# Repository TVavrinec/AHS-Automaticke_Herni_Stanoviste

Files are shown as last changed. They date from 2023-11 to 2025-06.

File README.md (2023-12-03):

# AHS-Specifikace hrubý popis
Specifikace AHS (Automatické Herní Stanoviště), nástupcem Lucerny a BlackBoxu
Jde o statické zařízení sloužící jako herní stanoviště.
Mělo by tedy být mobilní jen natolik aby nebyl problém jej přepravovat.
Není ale cílem aby ho hráči nosil během hry nosil s sebou.

# Konkrétní uživatelské požadavky
- Dva LED kruhy jeden radiální a jeden axiální (tak jak na lucerně)
- Tlaková plocha (tak jak na lucerně ale doladit samotnou kontaktní plochu aby se zvýšila spolehlivost)
- Výdrž na baterii alespoň pět hodin aby bylo možné organizovat čtyřhodinovou hru s rezervou na nastavování atd.
- Elegantní zapínání (znamená ne powerbankou a kabelem!!!)
- Snadná montáž (znamená ne 16h na jeden kus)
- Servisně snadné připojený komunikační/GPS modul uvnitř zařízení (A9, MC60 ???)
- Servisně snadné připojená dvířka a jiné moduly vně základního zařízení
- Základní zvuková odezva (pískle, na pokročilejší zvuk bude modul)

# Základní struktura elektroniky

Elektronika je rozdělena na dvě desky, Led dsku a Hlavní desku.

## LedDeska

Oproti předchozím verzím je přidán LED-kruh i na druhou stranu LedDesky abychom se zbavili LED-pásku a odebrat výstupní konektor
- Přední axiální LEDkoví kruh z 60ti RGB LEDek
- Zadní radiální LEDkoví kruh z 60ti RGB LEDek (buď přímo radiální [buce cca třikrát dražší] nebo axiální s odraznou plochou [radializátorem])
- LDC1614 nebo LDC1314 + čtyři snímací cívky pro snímání tlakové plochy

## Hlavní deska 
- ESP32-S3
- Interní systémy
    - dohodnutí PD
    - bzučák (bez oscilátorové)
    - Power manager
        - jednočlánek
        - zapínání (ovládání na Mini UI)
        - step-up na 5V
        - LDO na 3V3
        - LDO na 1V8
        - nabíječka
        - hw ochrana podvybití
- Konektory na
    - ledDesku
    - komunikační modul
    - externí moduly
    - USB-C (nabíjení a primární programování [USB přímo z ESP, nebudeme zabírat místo převodníkem])
    - mini UI
    - kontakty na SemiSemafoří programátor
    - zbylé piny

## Mini UI
Minimalistické vývojové rozhraní.
- RESET tlačítka
- BOOT tlačítka
- zapínací tlačítko
- vypínací tlačítko bych spojil se zapínacím nebo možná s resetem (dlouhí stisk vypíná, nechci tam mít příliž mnoho tlačítek)
- dvě tlačítka 
- dvě obyčejné ledky?

# Popis jednotlivých bodů
## Interní systémy
### Dohodnutí PD
Vykomunykování vyššího napětí a proudu zajišťuje čip **AP33772** připojený na I2C ESP.

### Bzučák
Piezzo připojené mezi dva piny ESP aby bylo možné programově nastavit frekvenci a částečně i hlasitost.

### Power manager
#### Zapínání
Umožňuje uživateli zařízení zapnout tlačítkem.
Vypnutí je možné provést softwarově z ESP.

#### Step-up na 5V
Zajišťuje napájení světelným kruhům a externím modulům.
Maximální proud je sto ukrmit oba světelné kruhy a moduloví konektor.
*Je tedy sto dodat cca 7A*

#### LDO na 3V3
Z napětí 3.3V je napájeno ESP32S3, LCD1x14 a PD sink AP33772.
*Je tedy sto dodat cca 1A*

#### Nabíječka
Nabíjení probíhá přez USB-C, nabíječka je proto schopna rovzu z 5V.
Aby se ale zařízení dalo nabít rychleji je možno použít standard PowerDelivery s napětí až 21V.
Na nabíjení je proto použit chip **BQ24179YBGR**.

### Hw ochrana podvybití
Kvuli ochraně baterie se zařízení vypne pokud se baterie vybije pod 2.8V (podle https://web.archive.org/web/20101122230718/https://www.panasonic.com/industrial/includes/pdf/Panasonic_LiIon_Charging.pdf by napětí na článek nemělo klesnout pod 2.3V a AHS přidává rezervu 0.1V [ https://web.archive.org/web/20100413182032/http://www.panasonic.com/industrial/batteries-oem/oem/lithium-ion.aspx ]) 

## Konektory
### USB-C
D+ D- jsou napojeny přímo na ESP a CC piny jsou napojeny na AP33772(to přes I2C na ESP).

### Konektor komunikačního modulu
Na konektor, je z ESP vyvedeno: 
-   I2C
-   celý UART
-   FUL_CARD_POWER_OFF
-   RESET
-   WoWWAN (interrupt)

a mimo ESP je na konektoru:
-   napájení přímo z baterie
-   SIM

Pin-out M2 konektoru z https://files.waveshare.com/upload/0/02/SIM7600X-M2_Hardware_Design_V1.01.pdf
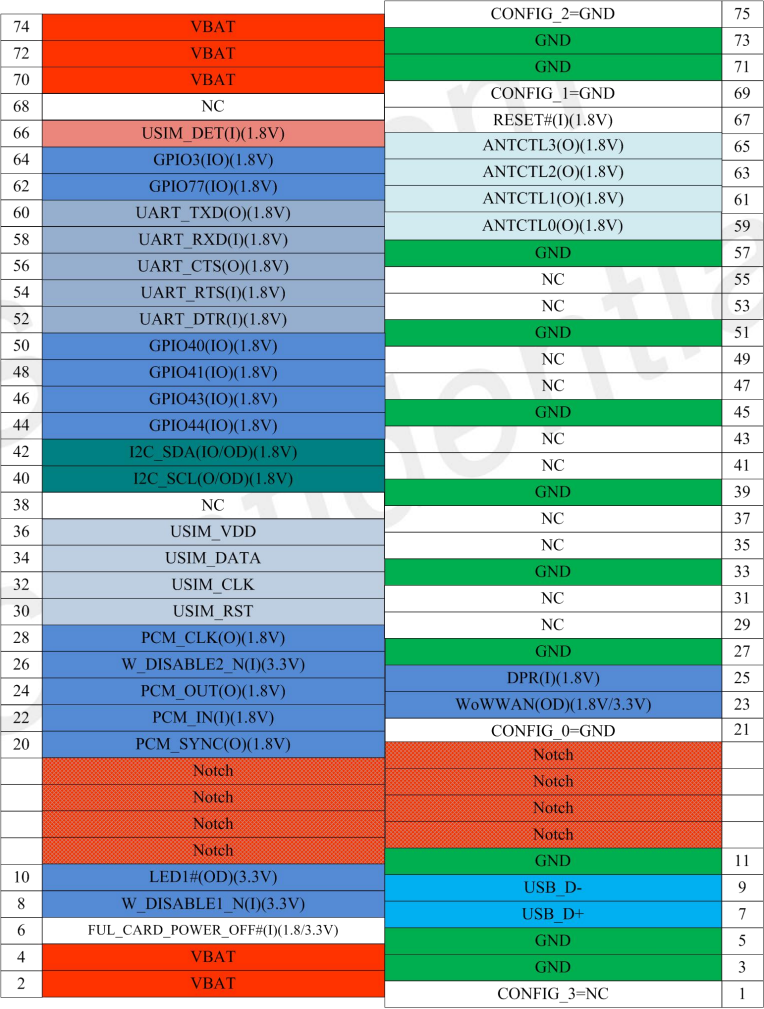
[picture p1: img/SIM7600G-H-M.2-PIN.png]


### Konektor na LedDesku

<-1--13-> 5V

<----14-> LED-DO

<-15-27-> GND

<----28-> 3V3

<----29-> LDC-GND

-----30-> LDC-INT

<----31-> SDA

<----32-- SCL

Pull-upy na I2C a na LDC-INT mají 4.7kΩ.
LDC-GND je na hlavní desce normální GND ale kvůli velkým proudum do ledek je v kabelu a na Led desce vedena odděleně.
Konektorem na 5V proteče alespoň 5A.

### Moduloví konektor

---> USART-RX

<--> 5V

<--> GND

<--- USART-TX

<--> GND

<--> 5V

---> INI

Všechny moduly jsou připojeny na jeden RX pin AHS.
Proto musí firmware AHS zajistit aby dva moduli nevysílali současně!
Každý modul má TX připojen přes rezistor 180Ω jako ochranu.

Interrupt na modulech se chová jako open-collector což je zajistit hardwarově.

AHS zajišťuje odolnost proti rušení na všech vstupních vodičích pomocí 4.7kΩ pull-up a odolnost proti zkratu na datových výstupních vodičích pomocí 180Ω.
Zároveň zajistí ESD ochranu všem vodičům co vedou z/do AHS.

Konektor je zároveň sto dodat napájení 5V s proudem v součty 2A.

Komunikace muže být vedena kabelem o délce až 25cm při komunikační rychlosti 5Mbps.
*Při dalším prodlužování linky bude třeba vodiče RX a TX vlnově přizpůsobit a doplnit linku terminátory*

## mechanická část
Základ AHS je mechanicky krátký válec s tlakovou plochou na horní ploše.
Kolem tlakové plochu je umístěn axiální světelný kruh a v horní části válcové plochy je radiální světelný kruh.

- Tělo minimálně v prototypu tisknuté
- Vyzkoušet různé provedení kontaktní plochy
    - Stejně jako na předchozí verzi FR4 ale tlustší aby se tolik nekroutila
    - PCB s hliníkovým jádrem + zalití do epoxidu nebo jiné dostatečně průsvitné hmoty
- Konektor externích modulu, USB-C a mini UI překrýt krytkou (ochrana před bordelem a náhodným mačkáním na tlačítka) 

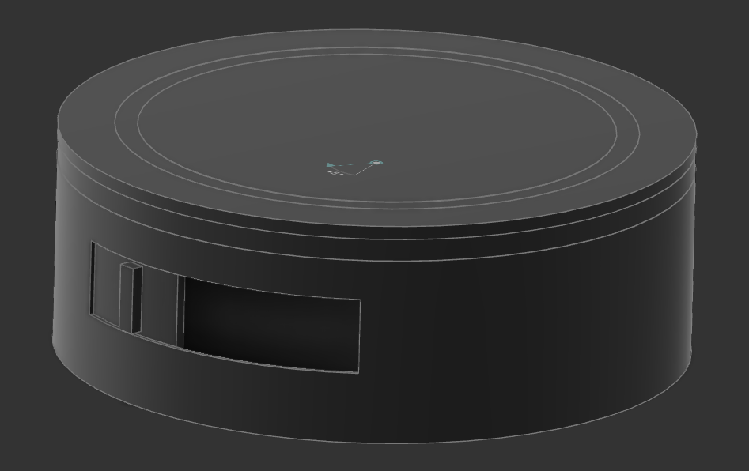
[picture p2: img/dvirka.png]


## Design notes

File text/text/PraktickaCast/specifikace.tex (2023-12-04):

Celé zařízení je rozděleno na základní jednotku a případné moduly které zajistí nové herní možnosti.
Například může jít o připojení úložného prostoru nebo zvukového modulu, který poskytne jak plnohodnotný zvukoví výstup tak vstup.

\subsection{uživatelské požadavky}
Jde o statické zařízení sloužící jako herní stanoviště.
Vyžaduje tedy mobilitu ale jen v rámci transportu na místo hry a spt, nikoliv v rámci samotné hry.

Zařízení bude mít dva světelné kruhy složené z inteligentních RGB LED.
Jeden radiální a druhý axiální na horní straně zařízení sloužící primárně jako odezva pro hráče na malou vzdálenost, např. při zadávání hesla.
Radiální kruh, také v horní části zařízení slouží naopak pro signalizace na delší vzdálenost, takový maják.

Uvnitř axiálního světelného kruhu se bude nacházet tzv. tlaková plocha.
Jedná se o ovládací prvek podobný dotykové ploše, s tím rozdílem že je schopen měřit i silu která na něj působí.

Aby bylo stanoviště reálně použitelné při hře musí celou hru vydržet na baterii.
Není ojedinělé aby měla outdoorová hra čtyři pět hodin bez přestávky.
Plus je nutná nějaká rezerva a čas na nastavování.
Pochopitelně je čas který zařízení zvládne běžet z baterie, silně závisí na činnosti, ale nebylo mi zrovna ideální, kdyby byla baterka, nějak výrazně omezující.
Výdrž na jedno nabití bych tedy chtěl směřovat alespoň na pět hodin.

Vzhledem k plánu připojovat moduly je nutné vyřešit jak se to budě dělat.
Bylo by ideální kdyby si mohl uživatel říct co bude hrát za hru a podle toho si sám připojil moduly které potřebuje.
Tomuto určitě nechceme bránit ale přímo to podporovat nese řadu problému jak ze strany konektoru a mechaniky, tak ze strany softwaru.
Konektor by totiž musel být ideálně beznástrojové rozpojitelný a opětovně spojitelný a přitom dostatečně pevný aby se zařízení mechanicky chovalo jako jeden celek.
Takový konektor je ale poměrně složité udělat tak aby byl spolehliví a tak jde v tuto chvíli spíš o hudbu budoucnosti.
Ze softwarového pohledu jde pak o problém z duvodu detekce konkrétních modulu a hlavně o otázku jak se chovat k modulum které jsou potenciálně záměnné.
Dejme tomu že máme modul klávesnici a modul dvířka.
Dvířka jsou původně primárně úložný prostor, díky detekci zavření je lze ale použít i jako velmi pohodlná tlačítka a v některých hrách se proto používají jen jako tlačítka.
Potenciální modul klávesnice je ovšem jen suma tlačítek.
Při vytváření konkrétní hry na míru modulum které herní návrhář má zrovna k dispozici je tento problém nepodstatný protože sám návrhář rozhodně co má jak být.
Ale ve chvíli kdy je ale o hru navrženou pro jinou kombinaci modulu nastává problém jak rozhodnout zda se dají dvířka použít místo klávesnice nebo ne.
Abychom se všem temto problémům, alespoň prozatím vyhnuli, rozhodli jsme že doplnění, či výměna modulu, pujde jen při servisním zásahu.

Některé hry vyžadují tak velké herní území že by na komunikaci mezi stanovišťmi už nestačila WiFi ani Bluetooth, které AHS jinak využívá ke komunikaci.  
Proto bude mít AHS možnost připojení k mobilní síti a tedy připojení k internetu.
Tím se za prvé rozšíří dosah AHS, všude kde je mobilní pokrytí a také přibude další metoda jak se stanovištěm komunikovat.
V rámci tohoto komunikačního modulu bude možné používat navíc i GNSS \footnote{Global Navigation Satellite System}.
Vzhledem k faktu že se přece jen nejedná o systém, který by využila většina her a zároveň je poměrně drahý došli jsme k rozhodnutí, mít jej jen jako doplnitelný modul.
Protože se jedná o modul který zprostředkovává komunikaci se světem je pravděpodobné že bude potřebovat převádět výrazně větší množství dat než běžný modul.
Primárně z tohoto důvodu je tento modul připojen na samostatném konektoru.
Potřebné antény budou už v základním zařízení ale samotný modul spadá do doplňkové výbavy.

V řadě případu je užitečné mít možnost zvuková zpětné vazby.
Ideální by bylo moci přehrávat libovolnou nahrávku, většinou ale stačí jednoduchý ton jako řekněme potvrzení na zadané heslo.
Možnost přehrávat plnohodnotnou nahrávku proto odsouváme jako možný doplňkový modul a v základní jednotce pro jednoduchost postačí piezoměnič. 

% \begin{itemize}
%     \item Dva LED kruhy jeden radiální na horní straně zařízení a jeden axiální v horní části zařízení
%     \item Tlaková plocha
%     \item Výdrž na baterii alespoň pět hodin aby bylo možné organizovat čtyřhodinovou hru s rezervou na nastavování atd.
%     \item Servisně snadné připojený komunikační/GPS modul uvnitř zařízení
%     \item Servisně snadné připojená dvířka a jiné moduly vně základního zařízení
%     \item Základní zvuková odezva
% \end{itemize}

\subsection{Struktura elektroniky základní jednotky}

Elektronika je rozdělena na tři samostatné PCB.
Jde o HlavníDeska na které je většina elektroniky, o~desku s~hlavním uživatelským rozhraním (LedDeska) a~o~obslužnou desku s~minimalistickým uživatelským rozhraním pro neherní obsluhu (MiniUI).

\subsubsection{LedDesku}
Jak název napovídá na LedDesce se nacházejí oba světelné kruhy, mimo to je zde i elektronika pro snímání tlakové plochy, tedy LDC1x14 \cite{LDC1614} a jeho snímací cívky.
Právě snímaní tlakové plochy je jeden z podstatných duvodu oddělení této desky od zbytku, zabere totiž docela dost prostoru.

\begin{itemize}
    \item Axiální LED kruh z 60ti RGB LED WS2812
    \item Zadní radiální LED kruh z 60ti RGB LED WS2812
    \item LDC1614 nebo LDC1314 se čtyřmi snímacími cívkami pro snímání tlakové plochy
    \item konektor na propojení s HlavníDeskou
\end{itemize}

\subsubsection{MiniUI}
Kvuli aktuální představě mechanické konstrukce není úplně dobře možné mít toto minimalistické uživatelské rozhraní na HlavníDeska.
Proto sme se rozhodli jej vyseparovat na samostatnou destičku, na které bude jen pár tlačítek a dvě signalizační LED.

\begin{itemize}
    \item RESET tlačítka
    \item BOOT tlačítka
    \item zapínací tlačítko
    \item dvě uživatelská tlačítka 
    \item dvě uživatelské ledky
\end{itemize}

\subsubsection{HlavníDeska}
Na HlavníDesce je většina systému základního zařízení.

Protože máme dlouholetým zkušenostem s mikrokontrolery ESP32, rozhodovali jsme jen mezi konkrétními čipy z této rodiny.
% Dnes už tedy jen většina, mikrokontroleru této rodiny má integrovanou WiFi a Bluetooth periferii, kterou AHS určitě využije.
Aktuální plán na tvorbu vysoko-úrovňového návrhu konkrétních her je používat skriptovací jazyk JavaScript, považujeme za nevhodné provádět tento návrh na úrovní jazyka C/C++.
Abychom tohoto mohli dosáhnout, musíme provozovat nějaký interpreter JavaScriptu a z aktuálně dostupných možností, považujeme za nejideálnější Jaculus \cite{Jaculus}.
Jaculus dělá řadu věcí paralelně a je tím pádem pro jeho chod ideální mít více jader procesoru, což aktuálně znamená tři možnosti ESP32, ESP32S2 a ESP32S3.
ESP32S2 nemá Bluetooth, který bychom rádi měli k dispozici.
ESP32S3 je téměř jen vylepšená verze staršího ESP32, oproti tomu mu sice chybí pár možností, ty ale v AHS nepotřebujeme využívat a naopak se nám hodí vyšší výpočetní výkon, rychlejší paměť a více piny.
AHS tedy ovládá mikrokontroler ESP32S3.

Zdroj AHS je tvořen dvěma LiIon články 18650 v paralelním uspořádání.
Paralelní uspořádání jsme zvolili aby nebylo nutné řešit balancování článků.

Aby nebylo možné softwarově baterii podvybít má AHS systém, který celé zařízení vypne v případě kdy dojde k vybití baterie pod 2.8V.
Pochopitelně software by měl vybitou baterii zaznamenat mnohem dřív a chovat se podle toho, např. neumožnit spustit hru s baterii na napětím 3.0V.

Baterii je pochopitelně nutno nabijet a bylo by velmi nepohodlné kvuli tomu muset vytahovat články ze zařízení.
Proto je na HlavníDesce i nabíjecí elektronika.
Navíc aby se minimalizoval čas nabíjení zařízení podporuje standard PowerDelivery a to až do napětí 21V.

Protože různé periferie vyžadují různá napájecí a komunikační napětí jsou na HlavníDeska hned čtyři napájecí větvě.
\begin{itemize}
    \item VCC, napětí baterie sloužící jako zdroj pro ostatní napájecí větvě a pro napájení komunikačního modulu. 
    \item Napětí \(3.3\-[V]\) na napájení logické části celého základního zařízení.
    \item Napětí \(5.0\-[V]\) pro LedDesku a externí moduly
    \item Napětí \(1.8\-[V]\) pro napájení napěťových převodníků sloužících na komunikaci s komunikačním modulem 
\end{itemize}
Napětí jednotlivých větví to u \(3.3\-[V]\) a \(1.8\-[V]\) tvořeno pomocí LDO.
Na vytvoření pěti voltové větvě je ale potřeba spínaný zdroj a to primárně ze dvou důvodů.
Za prvé protože napětí baterie ze které se tato větev napájí má nižší napětí a je jej tedy třeba vyspínat na napětí vyšší.
Za druhé tento zdroj poskytuje do systému mnohem větší proudy než druhé dvě větve a bylo by tedy vhodné, ho použít i v případě použití sériového řazení článků.

Na hlavníDesce je také řada konektorů sloužící pro připojení ostatních systémů.
Jde o konektory na:
\begin{itemize}
    \item propojení s LedDeskou                                             % samostatný objekt
    \item připojení MiniUI                                                  % samostatný objekt
    \item komunikační modul (M2 Konektor umožňuje použít různé moduly)      % externě definovaný objekt
    \item externí moduly                                                    % samostatný objekt
    \item USB-C (nabíjení a programování AHS)                               % externě definovaný objekt
    \item programátor                                                       % samostatný objekt
\end{itemize}
Do konektorů by se asi dal zařadit i držák na dva LiIon články 18650.

Za zmínku také stojí přítomnost piezoměniče pro jednoduchou zvukovou odezvu. 

\subsubsection{Propojení HlavníDesky a LedDesky}
Mezi HlavníDeskou a LedDeskou je třeba převést napájení a několik signálů.
LedDeska vyžaduje na konektoru přítomnost dvou napájecích větví \(5\-[V]\) pro světelné kruhy a \(3.3\-[v]\) pro snímání tlakové plochy.
Protože do LEDek může téct proud až 5A a být zároveň i docela rychle spínaný, považujeme za rozumné oddělit napájecím větvím zem.
Oddělení je tedy provedeno už na konektoru HlavníDesky.

Na samotné propojení jsme se rozhodli použít FFC kabel s roztečí \(0.5\-[mm]\).
Jednim vodičem takovéhoto kabelu zle vést proud maximálně \(0.4\-[A]\) \cite{FFC-konektor}.
Protože ale potřebujeme dodat proud až 5A použijeme 13 vodičů vedle sebe jakožto nejmenší počet který přenese požadovaný proud v rámci daných mezí.

Mimo napájení je tímto propojením veden i signál s daty pro světelné kruhy a I2C sběrnice s interruptem pro připojení čipu LDC1614 \cite{LDC1614}.

Vzhledem k počtu potřebných vodičů (konkrétně 32) jsme se rozhodli použít velmi běžný FFC konektor se 40 kontakty, s tím že zbylé kontakty se mohou hodit v budoucnu.

\subsubsection{Modulový konektor}
Modulovým konektorem je vedeno \(5\-[V]\) jako napájení pro moduly a UART s interruptem pro komunikaci.
Nad volbou komunikační sběrnice jsme strávili poměrně dost času přemýšlením.
Původně jsme uvažovali o využití RS485 jakožto odolné sběrnice u které by v případ potřeby nemusel být problém ani delší kabel.
RS485 má ale nevýhodu v tom že potřebuje dodatečný hardware, kterému bychom se hlavně na modulech rádi vyhnuli.
Stejný problém nastel u CANu i USB které by navíc mělo výhodu kompatibility se velkým množstvím hotových zařízení.

V první uvaze o UARTu jsme jej nejprve zavrhli kvuli potenciální náročnosti na přeposílání dat mezi moduly.
Při standardním použití, bychom totiž moduly řadili za sebe.
Prvnímu modulu by tak chodili data pro všechny ostatní moduly a musel by je přeposílat dál, což by stálo nezanedbatelné množství procesorového času.
V jisté chvíli jsme ale narazili na nestandardní komunikaci pomocí UARTu implementované v projektu Servio \cite{Servio}.
Tato implementace používá UART jako sběrnici.
Namísto standardního použití pro komunikace jeden s jedním tak muže komunikovat jeden s více.
Na tomto řešení je výhodné že nevyžaduje žádný dodatečný hardware a prakticky každý dnešní mikrokontroler je možné k této sběrnici velmi snadno připojit.
Ve srovnání s RS485 je sice mnohem méně odolná proti rušení, ale uvnitř zařízení nebude linka vedena na víc jak malé desítky centimetru.
Komunikace na delším kabelu je pak jednoduše nahraditelné bezdrátovou komunikací a není tak potřebné aby to nativně umožňovala tato sbernice.
Každopádně v případě potřeby delšího kabelu je možné navrhnout externí modul, který s této sbernic velmi jednoduše udělá RS485.
Alternativně by se pro komunikaci na delším kabelu dalo použít USB které je společně s nabíjením přivedeno na USB-C.

Všechny moduly jsou tedy připojeny na jeden RX pin AHS.
Proto musí firmware AHS zajistit aby dva moduly nevysílali současně.
Aby se zabránilo možným zkratum, jako ochranu má každý modul své piny UARTu připojeny přes rezistor \(180\-[\Omega]\).
Interrupt pin modulů se naopak chová jako open-collector a na straně hlavního zařízení je na něj tedy připojen pull-up rezistor.
Abychom alespoň trochu zvýšili odolnost linky proti rušení přidáme na přijímací stranu pull-up rezistor.
Cílem je zvýšení komunikačního proudu aby se případný proud vyvolaný rušením dal jednodušeji zanedbat.
V neposlední řadě jsou mají všechny piny na konektoru ESD ochranu.

\subsubsection{Konektor programátor}
Zařízení se dá jednoduše programovat přes USB-C, tento kanál se ale dá softwarově narušit a pro takové případy je tu konektor na programátor.
Jde o šest plošek na které se programátor připojuje pomocí pogo-pin.
Programátor sice obsahuje jen jednoduchou elektroniku která by mohla být i přímo v elektronice AHS ale ve většině případu by byla zbytečná.
Ve chvíli kdy by byla potřeba tak je stejně nutná odborná obsluha a pro tu není problém použít programátor.

\subsubsection{USB-C}
Jako napájecí a programovací konektor je použito USB-C.
Díky němu je možné podporovat standard PowerDelivery využitý pro zrychlení nabíjení.
Konektor je ale použit i na pohodlnější programování zařízení, pez potřeby programátoru.

\subsubsection{Konektor komunikačního modulu}
Pro připojení komunikačního modulu jsme zvolili konektor M2 typ-B jakožto standard pro tyto moduly.
Díky tomuto konektoru můžeme jednoduše připojit různé LTE a GNSS moduly.

% Na konektor, je z ESP vyvedeno: 
% -   I2C
% -   celý UART
% -   FUL_CARD_POWER_OFF
% -   RESET
% -   WoWWAN (interrupt)

% a mimo ESP je na konektoru:
% -   napájení přímo z baterie
% -   SIM

% Pin-out M2 konektoru z https://files.waveshare.com/upload/0/02/SIM7600X-M2_Hardware_Design_V1.01.pdf
% ![](img/SIM7600G-H-M.2-PIN.png)

% ## mechanická část
% Základ AHS je mechanicky krátký válec s tlakovou plochou na horní ploše.
% Kolem tlakové plochu je umístěn axiální světelný kruh a v horní části válcové plochy je radiální světelný kruh.

% - Tělo minimálně v prototypu tisknuté
% - Vyzkoušet různé provedení kontaktní plochy
%     - Stejně jako na předchozí verzi FR4 ale tlustší aby se tolik nekroutila
%     - PCB s hliníkovým jádrem + zalití do epoxidu nebo jiné dostatečně průsvitné hmoty
% - Konektor externích modulu, USB-C a mini UI překrýt krytkou (ochrana před bordelem a náhodným mačkáním na tlačítka) 

% ![](img/dvirka.png)

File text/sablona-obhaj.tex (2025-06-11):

% Soubory musí být v kódování, které je nastaveno v příkazu \usepackage[...]{inputenc}

\documentclass[%        Základní nastavení
  %draft,    				  % Testovací překlad
  12pt,       				% Velikost základního písma je 12 bodů
	t,                  % obsah slajdů bude vždy začínat od shora (nebude vertikálně centrovaný)
	aspectratio=1610,   % poměr stran bude 16:10 (všechny projektory v učebnách na Technické 12 Brno),
	                    % další volby jsou 43, 149, 169, 54, 32.
	unicode,						% Záložky a informace budou v kódování unicode
]{beamer}				    	% Dokument třídy 'zpráva', vhodná pro sazbu závěrečných prací s kapitolami
%\usepackage{etex}

\usepackage[utf8]		  % Kódování zdrojových souborů je v UTF-8
	{inputenc}					% Balíček pro nastavení kódování zdrojových souborů
	
\usepackage{graphicx} % Balíček 'graphicx' pro vkládání obrázků
											% Nutné pro vložení logotypů školy a fakulty

\usepackage[          % Balíček 'acronym' pro sazby zkratek a symbolů
	nohyperlinks				% Nebudou tvořeny hypertextové odkazy do seznamu zkratek
]{acronym}						
											% Nutné pro použití prostředí 'acronym' balíčku 'thesis'

%% Balíček hyperref je volán třídou beamer automaticky, proto není třeba následujícího kódu:
%\usepackage[
%	breaklinks=true,		% Hypertextové odkazy mohou obsahovat zalomení řádku
%	hypertexnames=false % Názvy hypertextových odkazů budou tvořeny
%											% nezávisle na názvech TeXu
%]{hyperref}						% Balíček 'hyperref' pro sazbu hypertextových odkazů
%											% Nutné pro použití příkazu 'nastavenipdf' balíčku 'thesis'

\usepackage{cmap} 		% Balíček cmap zajišťuje, že PDF vytvořené `pdflatexem' je
											% plně "prohledávatelné" a "kopírovatelné"

%\usepackage{upgreek}	% Balíček pro sazbu stojatých řeckých písmem
											%% např. stojaté pí: \uppi
											%% např. stojaté mí: \upmu (použitelné třeba v mikrometrech)
											%% pozor, grafická nekompatibilita s fonty typu Computer Modern!

%\usepackage{amsmath} %balíček pro sabu náročnější matematiky

\usepackage{booktabs} % Balíček, který umožňuje v tabulce používat
% příkazy \toprule, \midrule, \bottomrule

\usepackage[absolute,overlay]{textpos}

%%%%%%%%%%%%%%%%%%%%%%%%%%%%%%%%%%%%%%%%%%%%%%%%%%%%%%%%%%%%%%%%%
%%%%%%      Definice informací o dokumentu             %%%%%%%%%%
%%%%%%%%%%%%%%%%%%%%%%%%%%%%%%%%%%%%%%%%%%%%%%%%%%%%%%%%%%%%%%%%%

\input{nastaveni}      % v tomto souboru doplňte údaje o sobě, o názvu práce...
                       % (tento soubor je sdílený s textem práce)

%%%%%%%%%%%%%%%%%%%%%%%%%%%%%%%%%%%%%%%%%%%%%%%%%%%%%%%%%%%%%%%%%%%%%%%%

%%%%%%%%%%%%%%%%%%%%%%%%%%%%%%%%%%%%%%%%%%%%%%%%%%%%%%%%%%%%%%%%%%%%%%%%
%%%%%%     Nastavení polí ve Vlastnostech dokumentu PDF      %%%%%%%%%%%
%%%%%%%%%%%%%%%%%%%%%%%%%%%%%%%%%%%%%%%%%%%%%%%%%%%%%%%%%%%%%%%%%%%%%%%%
%% Při vloženém balíčku 'hyperref' lze použít příkaz '\pdfsettings'
\pdfsettings
%  Nastavení polí je možné provést také ručně příkazem:
%\hypersetup{
%  pdftitle={Název studentské práce},    	% Pole 'Document Title'
%  pdfauthor={Autor studenstké práce},   	% Pole 'Author'
%  pdfsubject={Typ práce}, 						  	% Pole 'Subject'
%  pdfkeywords={Klíčová slova}           	% Pole 'Keywords'
%}
\hypersetup{pdfpagemode=FullScreen}       % otevření rovnou v režimu celé obrazovky
%%%%%%%%%%%%%%%%%%%%%%%%%%%%%%%%%%%%%%%%%%%%%%%%%%%%%%%%%%%%%%%%%%%%%%%

\usetheme{VUT} 				% barvy a rozložení prezentace odpovídající VUT FEKT
% alternativně lze použít jiná berevná témata, ale bez záruky. Například: 
%\usetheme{Darmstadt} \usecolortheme{default2}
\logoheader					% vytvoření zkráceného loga VUT FEKT v hlavičce slajdu, nechte odkomentované

\begin{document}

% v případě zakomentování následujícího se zobrazí v pravém dolním rohu slajdů klikatelné navigační symboly 
\disablenavigationsymbols

% titulní snímek, vysazen bez horních, dolních a postranních lišt (volba plain),
% není tak vysazen ani nadpis snímku
\maketitle

%%%%%%%%%%%%%%%%%%%%%%%%%%%%%%%%%%%%%%%%%%%%%%%%%%%%%%%%%%%%%%%%%%%%%%%
% 1. snímek s cíli (zadaním) práce
\begin{frame} 
	% nadpis snímku
	\frametitle{Cíle práce}
	\begin{enumerate}
		\item Popsat potřeby zážitkových her
		\item Navrh specifikace zařízení vhodných pro zážitkové hry 
		\item Navrhnout tato zařízení
		\begin{itemize}
			\item Statické zařízení AHS
			\item Dynamické zařízení Semisemafor 
		\end{itemize}
		\item Navrhnout a otestovat
	\end{enumerate}
\end{frame}

%%%%%%%%%%%%%
\begin{frame} 
	\frametitle{Náčrt funkcí AHS}
	\vspace{10mm}
	\begin{itemize}
		\item Statické herní stanoviště
		\item Bezdrátová komunikace
		\item Zobrazení herních dat
		\item Jednoduše přizpůsobitelný \newline uživatelský vstup
		\item Odolnost proti vodě
		\item Možnost servisně doplnit \newline moduly s přídavnými funkcemi 
	\end{itemize}

	\begin{textblock}{8}(7.5,5)
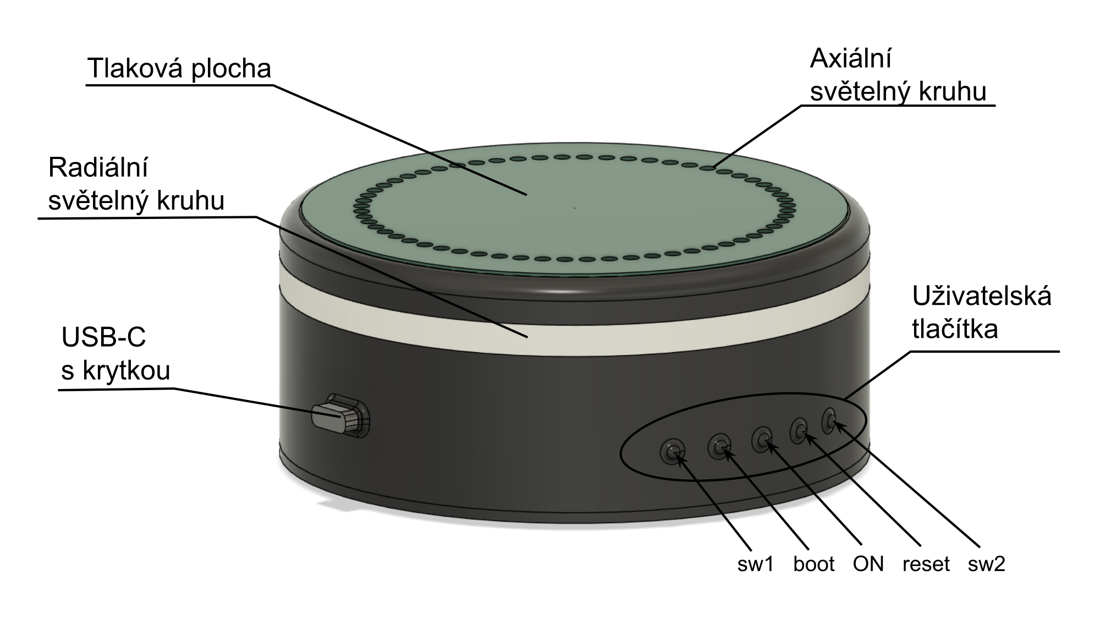
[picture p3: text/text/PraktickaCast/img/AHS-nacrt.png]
		
	\end{textblock}
\end{frame} 

%%%%%%%%%%%%%
\begin{frame} 
	\frametitle{Výsledná konstrukce AHS}
	\centering
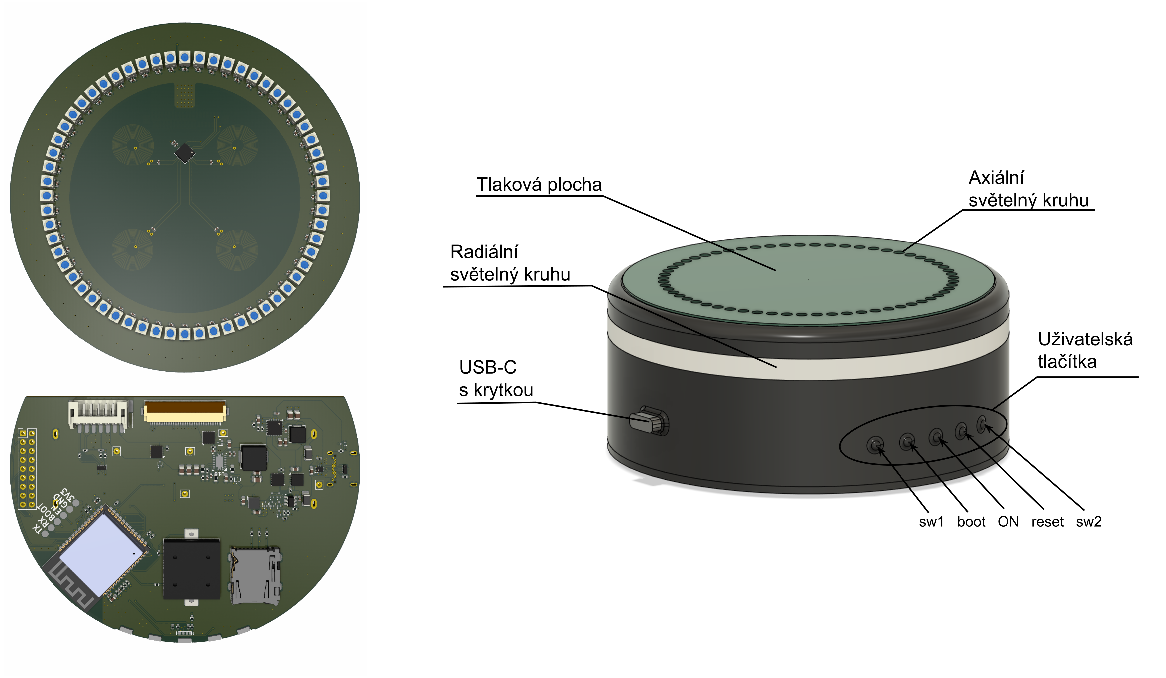
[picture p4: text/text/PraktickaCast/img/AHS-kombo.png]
	
\end{frame} 

\begin{frame} 
	\frametitle{Tlaková plocha}
	\centering
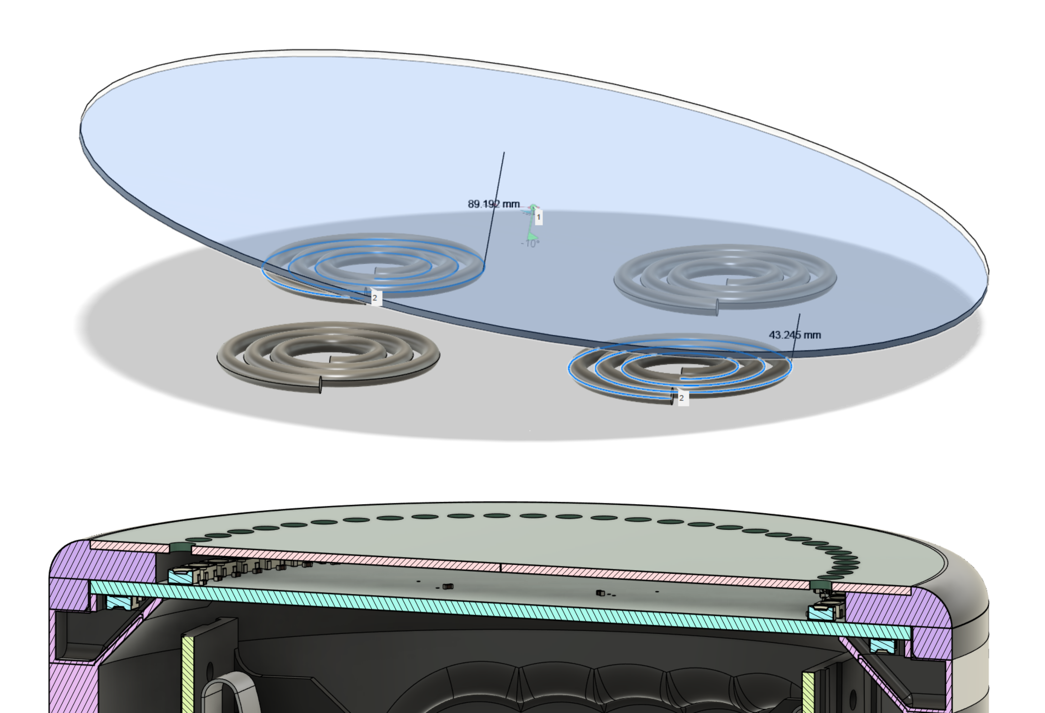
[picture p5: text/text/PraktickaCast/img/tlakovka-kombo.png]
	
\end{frame} 

%%%%%%%%%%%%%
\begin{frame} 
	\frametitle{Náčrt funkcí Semisemaforu}
	\vspace{10mm}
	\begin{itemize}
		\item Osobní zařízení
		\item bezdrátová komunikace
		\item zobrazení herních dat
		\item jednoduchý uživatelský vstup
		\item Odolnost proti vodě
	\end{itemize}

	\begin{textblock}{8}(7.5,2.5)
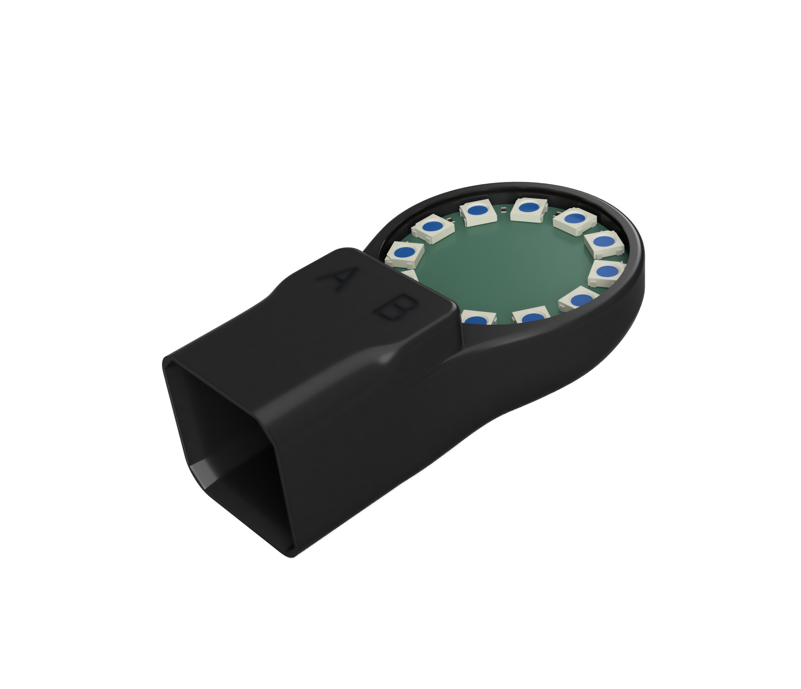
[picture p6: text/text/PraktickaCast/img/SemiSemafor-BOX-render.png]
		
	\end{textblock}
\end{frame} 

%%%%%%%%%%%%%
\begin{frame} 
	\frametitle{Závěr}
	\dots
\end{frame}

% podekovani
\begin{frame}[c] 
% bez nadpisu snímku
	\frametitle{\mbox{ }}
	\begin{center}
		{\Huge Děkuji za pozornost!}
	\end{center}
\end{frame}

% otázky oponenta
\frame{
\frametitle{Otázky oponenta}
	\emph{Jaká je souvislost Vašeho vzorce (1.2) s~Maxwellovými rovnicemi v~integrálním tvaru?}\\[2ex]
	%
	Již staří Římané\,\dots
}

\end{document}

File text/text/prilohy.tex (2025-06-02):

\chapter{Schémata AHS}
\label{AHS-sch}
\includepdf[pages=-, angle=90]{text/PraktickaCast/sch/ZakladniElektronika.pdf}

\chapter{Topologie DPS AHS}
\label{AHS-pcb}

\begin{figure}[!h]
	\begin{center}
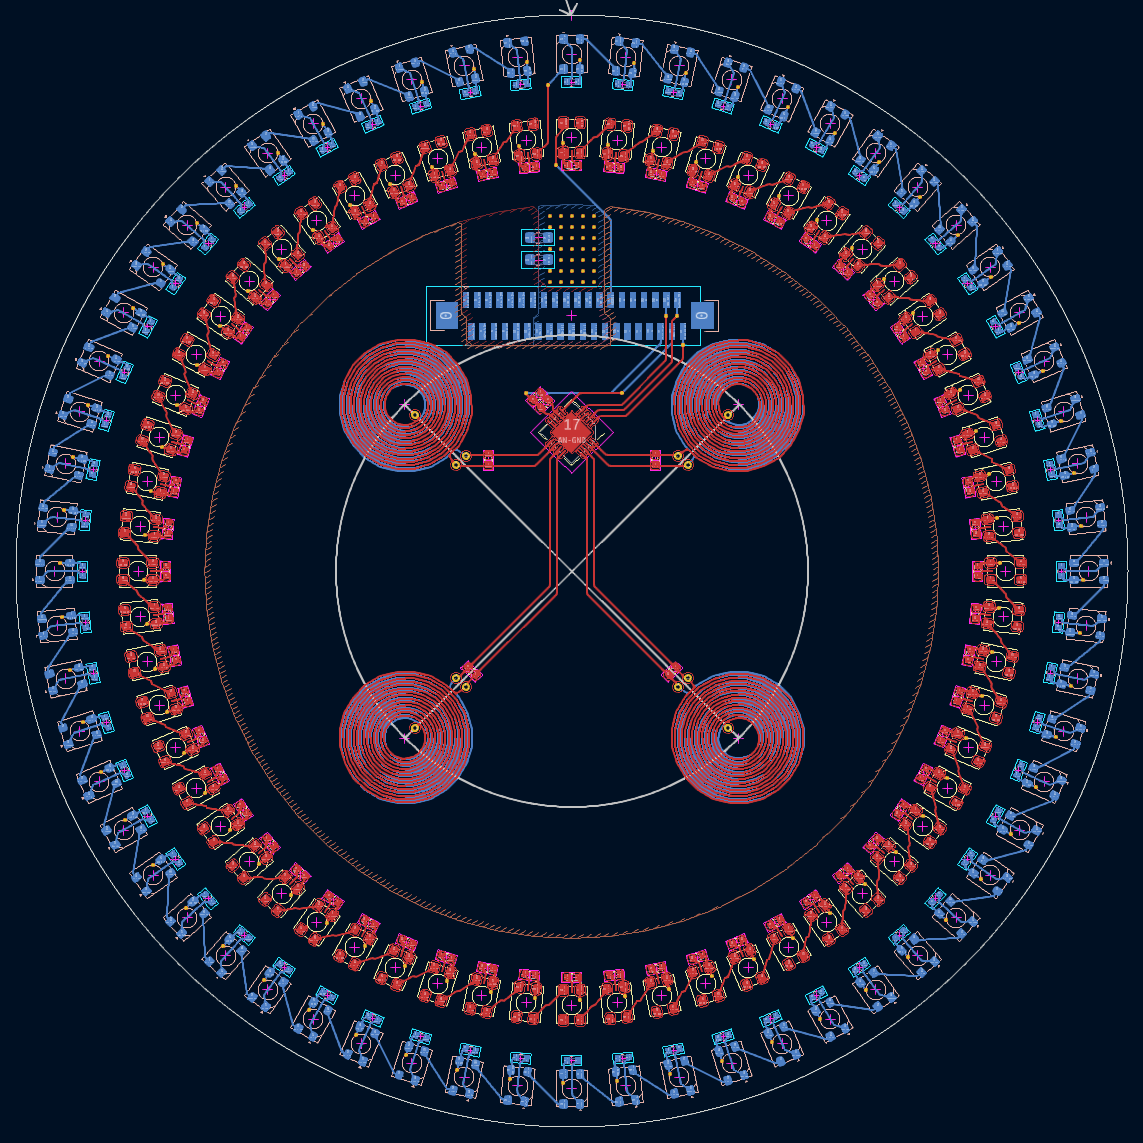
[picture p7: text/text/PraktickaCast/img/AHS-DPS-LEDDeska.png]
		
	\end{center}
	\caption{DPS LED desky AHS}
\end{figure}

\begin{figure}[!h]
	\begin{center}
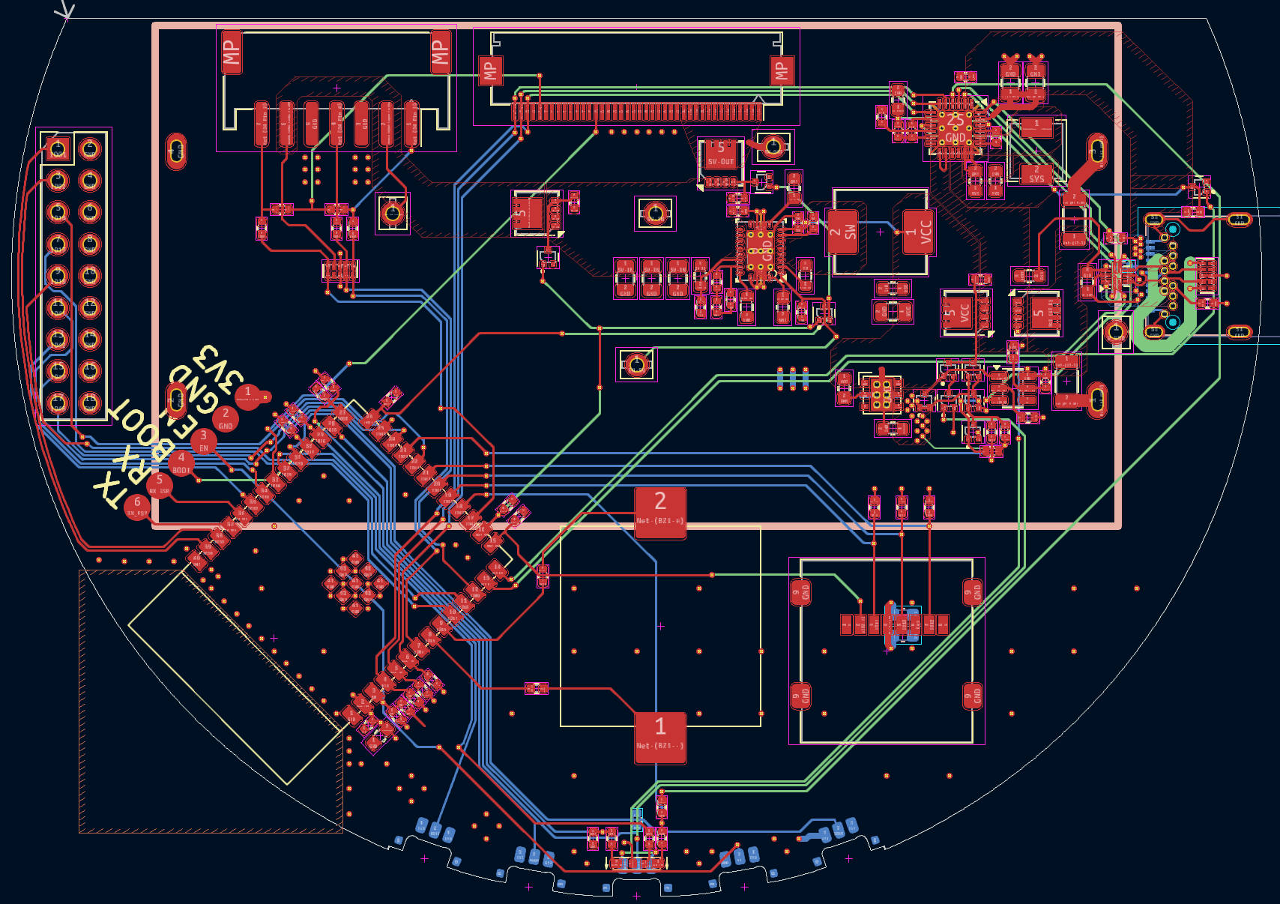
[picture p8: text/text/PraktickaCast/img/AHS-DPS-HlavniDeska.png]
	  
	\end{center}
	\caption{DPS hlavní desky AHS}
\end{figure}

\newpage

\chapter{Schémata Semisemaforu}
\section{Původní schéma Semisemaforu}
\label{Semisemafor-sch-v1}
\includepdf[pages=-, angle=90]{text/PraktickaCast/sch/Semisemafor-V1.0.pdf}

\section{Výsledné schéma Semisemaforu}
\label{Semisemafor-sch-v2}
\includepdf[pages=-, angle=90]{text/PraktickaCast/sch/Semisemafor-V1.1.pdf}

\chapter{Topologie DPS Semisemaforu}
\begin{figure}[!h]
	\begin{center}
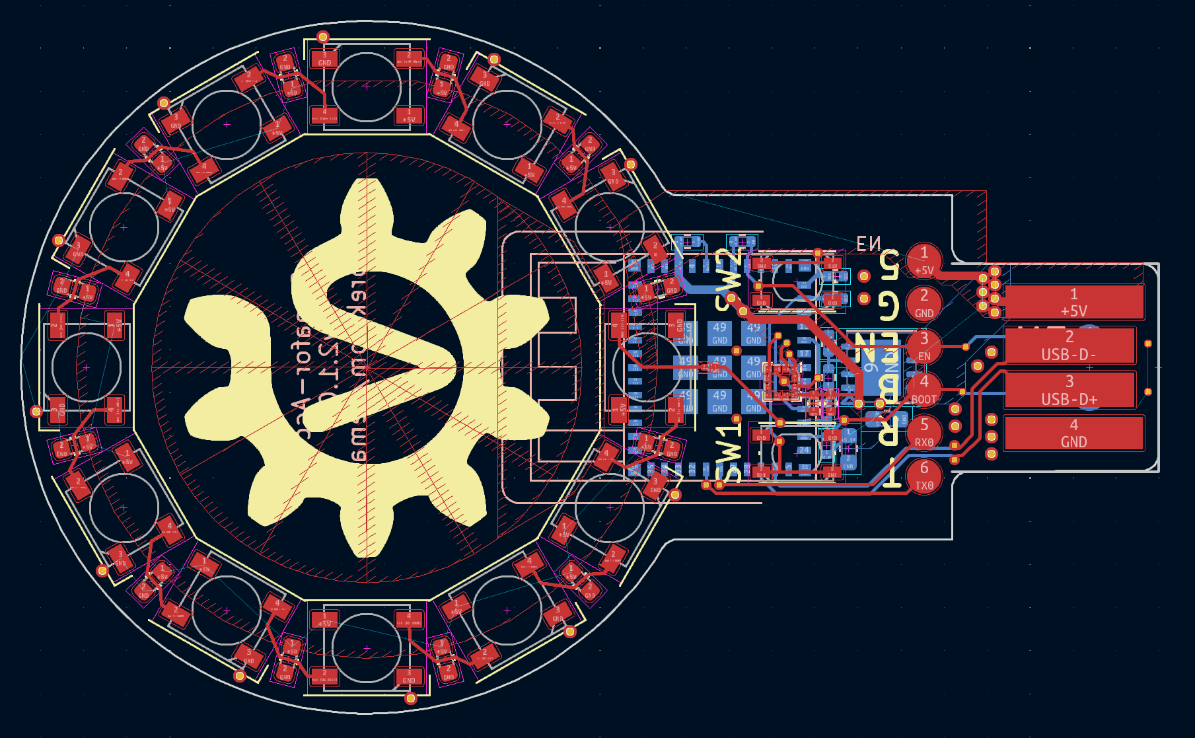
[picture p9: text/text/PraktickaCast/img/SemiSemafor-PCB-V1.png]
	  
	\end{center}
	\caption{Původní DPS Semisemaforu}
	\label{Semisemafor-pcb-v1}
\end{figure}

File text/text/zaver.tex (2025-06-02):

\chapter*{Závěr}
\phantomsection
\addcontentsline{toc}{chapter}{Závěr}

V~práci je~popsáno několik outdoorových her, které nevyužívají elektroniku a~následně je~rozebrána možnost jejich rozšíření za využití elektroniky.
Navíc~je popsána i~jedna hra, která od~základu s~elektronikou počítá.
Na základě těchto her jsou odvozeny požadavky, které jsou na~elektronická zařízení v~hrách kladeny.
Následně byl proveden návrh a~výroba dvou zařízení, která tyto požadavky plní a~je tak možné je~v~outdoorových hrách nasadit.

Jednodušší zařízení je~určeno k~tomu, aby jej hráč nosil sebou, a~jeho cílem je~být dostatečně malé a~levné, aby jej bylo možné používat při hrách ve~velkém počtu.
Využívá mikrokontrloér ESP32-C3 \cite{ESP32C3}, dvanáct LED WS2812B \cite{WS2812B} a~jako zdroj malou powerbanku.

Druhé zařízení je~určeno k~tomu, aby zastoupilo organizátora na~stanovišti a~umožnilo mu~tak zapojení do~hry jiným způsobem.
Toto zařízení tedy už~nemusí být tak malé ani levné, protože se~nepředpokládá nasazení v~tak velkém počtu a~je potřeba, aby bylo dobře viditelné.
Zařízení je~rozděleno na~základní řídící jednotku a~moduly, které jsou k~základní jednotce připojeny pomocí atypicky použitého UARTu.
Nestandardně je~UART použit pro komunikaci jeden s~více, namísto standardního jeden s~jedním (viz podkapitola \ref{sec:ModulovyKonektor}).
To má~za cíl umožnit připojení více modulů k~jedné základní jednotce bez potřeby přeposílání zpráv skrz moduly.
Zařízení má~už vlastní baterii a~elektroniku, která se~stará o~její nabíjení a~chrání ji~proti podbití a~přebití.
Řídícím mikrokontrolerém je~ESP32-S3 \cite{ESP32S3} a~také jsou zde využity LED WS2812B tentokrát ve~větším množství.
Významnou částí základní jednotky je~také tlaková plocha (viz kapitoly \ref{popisTlakovky2} a~\ref{popisTlakovky3}), která umožňuje hráčům interagovat se~základním zařízením pomocí doteku a~tlaku.

Pro obě zařízení bylo také nutné vytvořit vhodný obal, který dokáže odolat např. dešti, kterému mohou být za~provozu vystaveny.
Zařízení byla také zprovozněna a~ověřena jejich funkce.

Přestože jsou obě zařízení elektronicky i~mechanicky funkční, je pro využití jejich potenciálu třeba další vývoj na~straně programu obou zařízení.
Také bude třeba vyvinout moduly k~AHS, např. v~práci zmíněný zvukový modul.
Do budoucna bych také rád zřídil web, na kterém by byly dostupné již hotové hry, a~který by~umožňoval nahrávat hry přímo do~zařízení.
Touto cestou by totiž bylo možné výrazně usnadnit používání zařízení.

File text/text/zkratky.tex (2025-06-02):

\cleardoublepage
\chapter*{\listofabbrevname}
\phantomsection
\addcontentsline{toc}{chapter}{\listofabbrevname}

\begin{acronym}[KolikMista]

	\acro{AHS}
		{Automatické Herní Stanoviště}

	\acro{LDO}		% název/zkratka
		{Low-dropout regulator - regulátor napětí s nízkým úbytkem}

	\acro{FFC}						% název
		{Flexible Flat Cable - plochý ohební kabel}					% popis

	\acro{DPS}
		{Deska Plošných Spojů}    %CAN, UART, RX, TX, USB, I2C, LDC1614, NFC, LoRa, NB-IoT 
	
	% \acro{PCB}
	% 	{Printed Circuit Board - deska plošných spojů}    %CAN, UART, RX, TX, USB, I2C, LDC1614, NFC, LoRa, NB-IoT 

	\acro{FDM}
	{Fused Deposition Modeling}% - 3D tisková technologie využívající tavení tiskové struny}

	\acro{IMU}
	{Inertial Measurement Unit - inerciální měřící jednotka}% - 3D tisková technologie využívající tavení tiskové struny}

\end{acronym}

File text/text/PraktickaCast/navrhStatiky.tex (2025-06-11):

% Celé zařízení je~rozděleno na~základní jednotku a~případné moduly, které zajistí nové herní možnosti.
%~Například může jít o~připojení úložného prostoru nebo zvukového modulu, který poskytne jak plnohodnotný zvukový výstup tak vstup.

%~\subsection{uživatelské požadavky}
Uživatelským požadavkem je~statické zařízení sloužící jako herní stanoviště.
Vyžaduje tedy mobilitu jen v~rámci transportu na~místo hry a~zpět, nikoliv v~rámci samotné hry.
Z~toho plynou požadavky na~velikost výsledného zařízení.

Zařízení bude mít dva světelné kruhy složené z~60 RGB LED.
Číslo 60~jsem zvolil, protože se~jedná o~dostatečně jemné dělení, aby se~daly dělat plynulé efekty.
Zároveň jde o~číslo, které koresponduje s~hodinovým ciferníkem a~stupnicí na~kompasu.
Jeden z~kruhů bude radiální a~druhý axiální.

Axiální kruh bude umístěn~na horní stranu zařízení a~bude sloužit primárně jako odezva pro hráče na~malou vzdálenost, např. při zadávání hesla.
Radiální kruh pak bude umístěn také v~horní části zařízení a~jeho účelem bude naopak signalizace na~delší vzdálenost.
Například může sloužit jako maják viditelný ve tmě i~na stovky metrů.

%TODO: dopsat a~vygenerovat ilustraci
Uvnitř axiálního světelného kruhu se~bude nacházet tzv. tlaková plocha. %\label{popisTlakovky1}
Jedná se~o~ovládací prvek podobný dotykové ploše s~tím rozdílem, že~je schopen měřit i~sílu, která na~něj působí.
% Tento prvek je~založen na~měření rezonanční frekvence snímacích LC~článků, nad kterými se~nachází tlaková plocha.
% Tlaková plocha je~vodivý objekt, ve~kterém se~cívkou LC~článku indukují vířivé proudy a~následně se~jimi indukují proudy zpět v~cívce LC~článku.
% Tím plocha ovlivňuje indukčnost cívky a~tedy i~rezonanční frekvenci LC~článku.
% Ovlivnění indukčnosti je~závislé na~vzdálenosti plochy od~cívky a~tedy i~na~síle, která na~plochu působí.
% Velikost síly, která na~plochu působí, totiž ovlivňuje její průhyb a~tedy i~vzdálenost od~cívky.
% Díky velkému rozlišení použitého čipu LDC1614 \cite{LDC1614} (28 bitů) je~možné měřit změny vzdálenosti v~řádu jednotek mikrometrů \cite{LDC1614LinearPositionSensing}.
% Tato metoda je~tedy schopna měřit vzdálenost plochy od~jednotlivých cívek, které jsou čtyři, a~plochu tak snímají na~čtyřech místech.
% Následně je~z~těchto hodnot možno dopočítat, jak je~plocha nakloněna a~tím určit, kde se~jí uživatel dotýká.
%~Protože je~zároveň možné určit i~sílu jakou uživatel při dotyku vyvinul, dostal tento systém jméno tlaková plocha. %~silová by~bývalo přesnější ale nějak mi~to nejde přes pysky

Aby bylo stanoviště reálně použitelné při hře, musí celou hru vydržet na~baterii.
Není ojedinělé, aby měla bojovka čtyři i~pět hodin bez přestávky.
Plus je~nutná časová rezerva a~čas na~nastavování.
Čas, který zařízení zvládne běžet z~baterie, silně závisí na~činnosti, ale nebylo by~zrovna ideální, kdyby baterie byla výrazně omezujícím faktorem.
Výdrž na~jedno nabití by~tedy měla být alespoň šest hodin.

Vzhledem k~plánu připojovat moduly je~nutné navrhnout mechanizmus připojení.
Bylo by~ideální, kdyby si~mohl uživatel říct, co~bude hrát za~hru, a~podle toho si~sám připojil moduly, které potřebuje.
Tomuto určitě nechci bránit, ale přímo to~podporovat nese~řadu problémů, jak ze~strany konektoru a~mechaniky, tak ze~strany softwaru.
Konektor by~totiž musel být ideálně beznástrojově rozpojitelný a~opětovně spojitelný a~přitom dostatečně pevný, aby se~zařízení mechanicky chovalo jako jeden celek.
Takový konektor je~ale poměrně složité vyrobit, tak aby byl spolehlivý, a~tak jde v~tuto chvíli jen o~možnost dalšího vývoje.
Ze softwarového pohledu jde pak o~problém, jak detekovat konkrétní modul a~hlavně o~otázku, jak se~chovat k~modulům, které jsou potenciálně záměnné.

% Dejme tomu, že~máme modul klávesnici a~modul dvířka.
% Dvířka jsou původně navržena primárně jako úložný prostor, díky detekci zavření je~lze ale použít i~jako pohodlná tlačítka a~v~některých hrách se~proto používají jen jako tlačítka.
% Potenciální modul klávesnice je~ovšem jen suma tlačítek.
% Při vytváření konkrétní hry na~míru modulům, které herní návrhář má~zrovna k~dispozici, je~tento problém nepodstatný, protože sám návrhář rozhodne, co~má jak být.
% Ale ve~chvíli, kdy jde o~hru navrženou pro jinou kombinaci modulů, nastává problém jak rozhodnout, zda se~dají dvířka použít místo klávesnice nebo ne~a~naopak.
% Abych se~všem těmto problémům alespoň prozatím vyhnul, rozhodl jsme se, že~doplnění či~výměna modulu půjde jen při servisním zásahu.
% Problém záměny modulů tak budu řešit tím, že~každá hra bude vytvořena jen pro konkrétní sadu modulů.

V~řadě případů je~užitečné mít možnost zvukové zpětné vazby.
Ideální by~bylo moci přehrávat libovolnou nahrávku, většinou ale stačí jednoduchý tón, řekněme jako potvrzení zadaného hesla.
Pro možnost přehrávání plnohodnotného zvuku bude proto sloužit samostatný modul a~v~základní jednotce, postačí jednoduchá sirénka.

Z~požadavků mi~vyplynulo zařízení, jehož možný vzhled je~nastíněn na~obrázku \ref{fig:AHS-nacrt}.
\begin{figure}[h]
    \centering
    
    \caption{Návrh vzhledu zařízení}
    \label{fig:AHS-nacrt}
\end{figure}

\newpage
\section{Elektronické systémy zařízení}

Elektronika bude~rozdělena na~dvě samostatné DPS.
Pujde o~hlavní desku, na~které bude umístěna většina elektroniky a~o~desku s~hlavním uživatelským rozhraním (LED deska).
Kompletní schéma a~topologie DPS je~k~vidění v~přílohách (schéma je~k vidění v~příloze \ref{AHS-sch} a~DPS v~příloze \ref{AHS-pcb}).

%~Původně jsem uvažoval ještě třetí desku, se~základním uživatelským rozhraním (mini~UI) pro usnadnění zajištění jisté míry voděodolnosti, ale nakonec jsem se~rozhodl spojit ji~s~hlavní deskou.

\subsection{LED deska}
Na LED desce budou umístěny oba světelné kruhy a~elektronika pro snímání tlakové plochy, tedy LDC1614 \cite{LDC1614} a~jeho snímací LC~články.
Právě snímaní tlakové plochy je~jeden z~hlavních důvodů oddělení této elektroniky na~samostatnou desku, zabere totiž na DPS velkou plochu.

Na LED desce se~tedy nachází:
\begin{itemize}
    \item Axiální LED kruh z~60 RGB LED WS2812B v~pouzdře \(3,5\)\;x\;\(2,8~mm\)
    \item Radiální LED kruh z~60 RGB LED WS2812B v~pouzdře \(3,5\)\;x\;\(2,8~mm\)
    \item LDC1614 se~čtyřmi snímacími LC~články pro snímání tlakové plochy 
    \item konektor na~propojení s~hlavní deskou
\end{itemize}

% Čip LDC1614 \cite{LDC1614} lze zaměnit za~LDC1314 \cite{LDC1314}, tyto čipy se~liší vlastně jen šířkou výstupního registru.
% Dalo by~se~tedy čekat snížení citlivosti při použití verze čipu LDC1314, není to~ale úplně pravda.
% Uživatel si~u~LDC1314 ale musí zvolit kompromis mezi rozsahem měření a~jeho citlivostí.
% Nastavení se~navíc dá~jednoduše měnit za~chodu, takže by~LDC1314 znamenalo nanejvýš trochu složitější program ale ne~nutně ztrátu citlivosti nebo rozsahu. 

\newpage
\subsection{Hlavní deska}

Řídícím mikrokontrolérem AHS bude ESP32-S3 (výběr je~rozebrán v~podsekci \ref{subs:vybermikrokontroléru}).
Na hlavní desce bude spolu s~mikrokontrolérem také zdroj poskytující správné napájení všech systémů zařízení.
Hlavní deska bude tedy zprostředkovávat několik napěťových větví.
V~neposlední řadě se zde bude nacházet základní uživatelské rozhraní v~podobě několika tlačítek, jednoduché RGB LED a sirénky.

Zdroj AHS je~tvořen dvěma LiIon články 18650 v~paralelním uspořádání.
Dva články volím, abych zajistil dostatečnou výdrž baterie a~abych využil volné místo v~zařízení.
Paralelní uspořádání jsem volil, aby nebyl nutný balancer při nabíjení, a~tedy abych zjednodušil zařízení.

Elektronika řeší i~nabíjení baterie, současně s~čímž realizuje i~ochranu proti podbití a~případnému přebití.
Aby nebylo možné softwarově baterii podvybít, má~AHS už~zmíněnou ochranu proti podvybití řešenou čistě hardwarově.
Tato ochrana tak celé zařízení vypne v~případě, že~dojde k~vybití baterie pod napětí \(2,8~V\).
Pochopitelně, software by~měl vybitou baterii zaznamenat mnohem dřív a~chovat se~podle toho, např. neumožnit spustit hru napětí na baterii \(3,0~V\).

Abych vyhověl napěťovým požadavkům všech použitých systémů, jsou na~hlavní desce tři různá napájecí napětí, která se~dál dělí do~šesti napájecích větví.
\begin{itemize}
    \item VCC, napětí baterie sloužící jako zdroj pro ostatní napájecí větve a~pro napájení komunikačního modulu. 
    \item Napětí \(3,3~V\) na~napájení logické části celého základního zařízení.
    \item Napětí \(5,0~V\) pro LED desku a~externí moduly a~napájení z~USB
    \begin{itemize}
        \item V-USB, z~USB-C konektoru pro nabíjení a~programování
        \item 5V-A, pro napájení modulu na~modulovém konektoru
        \item 5V-B, pro napájení LED kruhů
        \item 5V, jakožto zdroj pro větvě 5V-A a~5V-B 
    \end{itemize}
\end{itemize}
Napětí větví \(3,3~V\) je~tvořeno pomocí LDO.
Na vytvoření větve 5V~je ale potřeba spínaný zdroj.
Především proto, že napětí baterie, ze~které se~tato větev napájí, má~nižší napětí a~je jej tedy třeba transformovat na~napětí vyšší.
Navíc tento zdroj poskytuje do~systému proudy o~hodnotě až pět ampér a~bylo by~tedy vhodné použít spínaný zdroj i~v~případě vyššího vstupního napětí.
LDO by tak mělo malou efektivitu převodu a~především by~vytvářel nemalé množství odpadního tepla, se kterým by se zařízení muselo vypořádat.

Na hlavní desce je~také řada konektorů sloužících pro připojení ostatních systémů.
Jde o~konektory na:
\begin{itemize}
    \item propojení s~LED deskou,                % samostatný objekt
    \item externí moduly,                        % samostatný objekt
    \item USB-C (nabíjení a~programování AHS),   % externě definovaný objekt
    \item programátor,                           % samostatný objekt
    \item slot pro SD~kartu.
\end{itemize}
Do~konektorů by se také dal zařadit držák na~dva LiIon články 18650.

\subsection{Výběr mikrokontroléru \label{subs:vybermikrokontroléru}}
Požadavky na výbavu mikrokontroléru jsou:
\begin{itemize}
    \item WiFi,
    \item Bluetooth,
    \item alespoň 2~UARTy,
    \item alespoň 22~GPIO pinů,
    \item I2C,
    \item dostatečný výpočetní výkon pro hladký chod interpretru JavaScriptu nebo Pythonu.
\end{itemize}

Porovnání některých dostupných možností je~provedeno v~tab. \ref{tab:vybermikrokontroléru}.
\begin{table}[h]
    % \hspace{-20mm}
    \small
    \begin{tabular}{|l|l|l|l|l|c|}
        % \hline
        % mikrokontrolér                  ~&~Jádro         &~Počet GPIO pinů    & Počet UARTů  ~&~Počet I2C &~Wi-Fi a~Bluetooth                \\ \hline
        \hline
        \makecell{Mikro-\\kontrolér}    & Jádro         &~\makecell{Počet\\GPIO pinů} &~\makecell{Počet\\UARTů} &~\makecell{Počet\\I2C} &~\makecell{Wi-Fi a\\Bluetooth} \\
        \hline
        ESP32        \cite{ESP32}       &~2x Xtensa LX6 &~34    ~            & 3            ~&~2         &~\textcolor{green}{\checkmark}    \\ \hline
        ESP32-S3     \cite{ESP32S3}     &~2x~Xtensa LX7 &~45    ~            & 3            ~&~2         &~\textcolor{green}{\checkmark}    \\ \hline
        ESP32-C3     \cite{ESP32C3}     &~1x~RISC-V     &~16-22              & 2             &~1         &~\textcolor{green}{\checkmark}    \\ \hline
        ESP32-C6     \cite{ESP32C6}     &~1x~RISC-V     &~34    ~            & 3            ~&~2         &~\textcolor{green}{\checkmark}    \\ \hline
        PIC32MZ-W1  ~\cite{PIC32MZ}     &~DS60001192    & 62    ~            & 3            ~&~2         &~\textcolor{green}{\checkmark}    \\ \hline

        \textcolor{red}{nRF7000      \cite{nRF7000}}      &~-             &~\textcolor{red}{13}& \textcolor{red}{0} &~\textcolor{red}{0}    & \textcolor{green}{\checkmark}    \\ \hline
        \textcolor{red}{RTL8710      \cite{RTL8710}}      &~ARM Cortex-M3 &~\textcolor{red}{17}& \textcolor{red}{1} &~3                     &~\textcolor{green}{\checkmark}    \\ \hline
        \textcolor{red}{RTL8721DM    \cite{RTL8721DM}}    & -            ~&~\textcolor{red}{17}& 3                  & 2                    ~&~\textcolor{green}{\checkmark}    \\ \hline
        \textcolor{red}{STM32WB55    \cite{STM32WB55}}    & ARM Cortex-M4 &~37    ~            & \textcolor{red}{1} &~2                     &~\textcolor{red}{$\times$}        \\ \hline
        \textcolor{red}{MSP430BT5190 \cite{MSP430BT5190}} &~-             &~32                 &~4                 ~&~4~                   ~&~\textcolor{red}{$\times$}        \\ \hline
    \end{tabular}
    \caption{Dostupné vyhovující mikrokontroléry}
    \label{tab:vybermikrokontroléru}
\end{table}

Abych nemusel návrh komplikovat anténou, použil jsem v~návrhu mikrokontrolér na~modulu, který má~anténu integrovanou, a~navíc integruje i~flash paměť. 
Protože už~tyto moduly interně používají některé GPIO, klesne množství, které mohu využít.

\begin{table}[h]
    \centering
    \begin{tabular}{|l|l|l|l|l|}
        \hline
        mikrokontrolér                  & Počet GPIO pinů    & vyhovuje?                     \\ \hline
        ESP32-WROOM     \cite{ESP32}    & 26                 & \textcolor{green}{\checkmark} \\ \hline
        ESP32-S3-WROOM  \cite{ESP32S3}  & 36                 & \textcolor{green}{\checkmark} \\ \hline
        ESP32-C3-WROOM  \cite{ESP32C3}  & 15                 & \textcolor{red}{$\times$}     \\ \hline
        ESP32-C6-WROOM  \cite{ESP32C6}  & 23                 & \textcolor{green}{\checkmark} \\ \hline
        WFI32E01PC      \cite{PIC32MZ}  & 37                 & \textcolor{green}{\checkmark} \\ \hline
    \end{tabular}
    \caption{Moduly s~mikrokontroléry}
    \label{tab:ModulySmikrokontroléry}
\end{table}

Jedním z~požadavků na~zařízení je~dostatečný výpočetní výkon pro hladký chod interpretu JavaScriptu nebo Pythonu.
Výpočetní výkon se~porovnává poněkud složitěji, protože se~nejedná tak úplně o~jeden parametr.
V~tomto případě je~ale vhodné prozkoumat i~dostupnost interpretu pro daný mikrokontrolér.
Pro ESP32 a~ESP32-S3 je~dostupný JavaScriptový interpret Jaculus \cite{Jaculus} i~interpret jazyka Python MicroPython \cite{MicroPythonESP32S3} \cite{MicroPythonESP32}.
Pro PIC32MZ-W1 a~ESP32-C6 je~dostupný pouze interpret jazyka Python MicroPython \cite{MicroPythonPIC32MZ-W1} \cite{MicroPythonESP32C6}. %interpret JavaScriptu jsem však nenašel.
ESP32 a~ESP32-S3 tak poskytuje výhodu v~možnosti volby skriptovacího jazyka.
ESP32-S3 má~oproti starší verzi ESP32 výkonnější jádro a~interpret JavaScriptu, resp. Pythonu, na~něm tak běží o~něco plynuleji.

Další výhodou ESP32-S3 oproti PIC32MZ-W1 je~jeho cena, která se~pohybuje okolo 4~USD \cite{JSC-ESP32-S3}.
Zatímco PIC32MZ-W1 je~u~JLCPCB za~13.65~USD \cite{JSC-WFI32}.
Navíc u~firmy JLCPCB, kde plánuji elektroniku vyrábět, sice je~PIC32MZ-W1 v~nabídce, ale není na~skladě \cite{JSC-WFI32}, zatímco u~ESP32-S3 bylo v~době návrhu dostupných hned 19~variant \cite{JSC-ESP32-S3}.

V~mém případě má~ESP32-S3 ještě jednu podstatnou výhodu, a~tou je~fakt, že~s~rodinou mikrokontrolérů ESP32 mám dlouholeté zkušenosti.
Z~těchto důvodů jsem se~rozhodl pro ESP32-S3.

\subsection{Tlaková plocha \label{popisTlakovky2}}
Tlaková plocha je~založena na~měření indukčnosti čtyř cívek.
Tyto cívky jsou použity spolu s~paralelně řazeným kondenzátorem, aby dohromady tvořily rezonanční LC~článek.
Zároveň jsou cívky vytvořeny jako reliéf v~mědi DPS, aby jimi vytvořené magnetické pole sahalo mimo ně~a~dalo se~tak použít pro ovlivnění jejich vlastností.

V~objektu vloženém do~proměnného magnetického pole vytvářeného cívkou se~vytváří vířivé proudy, které následně tvoří magnetické pole ve~směru opačném k~poli vytvořenému cívkou.
Magnetické pole vzniklé z~vířivých proudů tak indukuje další proudy zpět v~cívce, čímž snižuje její zdánlivou indukčnost.
Ve výsledku tak objekt v~magnetickém poli cívky ovlivňuje její indukčnost.
Velikost indukovaných vířivých proudů a~tedy i~míra ovlivnění indukčnosti cívky, je~závislá na~vodivosti daného objektu (terčíku), na~jeho rozměrech a~na jeho poloze vůči cívce.
V~případě pohybu terčíku, pouze ve~směru kolmém k~ploše DPS s~vytvořenou cívkou, se~tak převádí vzdálenost terčíku a~DPS na~indukčnost cívky.
Vizualizace popsaného mechanizmu sa nachází na obr. \ref{fig:pryncip-LDC}.

\begin{figure}[h!]
    \centering
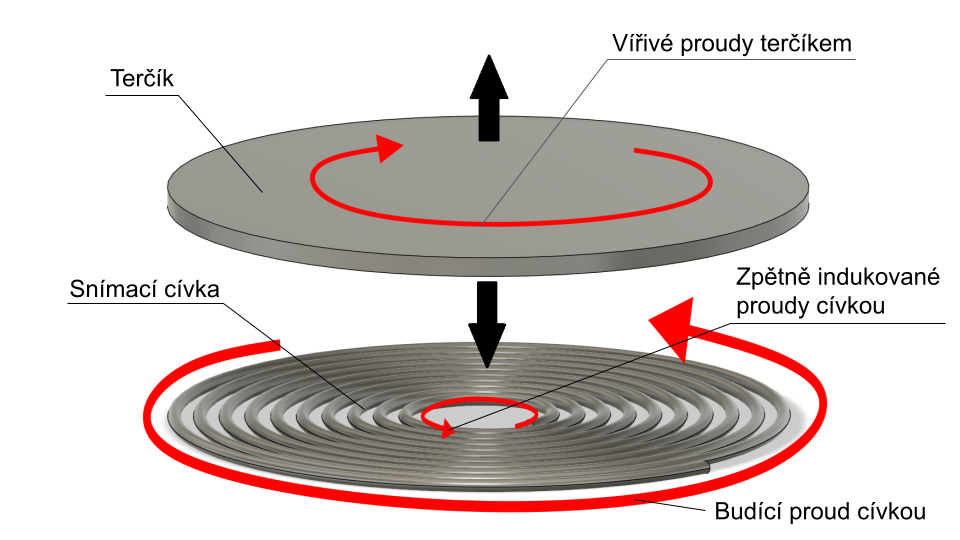
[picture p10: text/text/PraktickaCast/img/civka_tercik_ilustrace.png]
    
    \caption{Princip převodu vzdálenosti na~indukčnost}
    \label{fig:pryncip-LDC}
\end{figure}

Protože pro indukci vířivých proudů v~terčíku musí být magnetické pole cívky proměnné, musí být i~proud cívkou proměnný a~tedy i~napětí na~celém LC~článku.
V~případě použití čipu LDC1614 je~tedy LC~článek chvíli buzen nastaveným proudem, dokud nedosáhne nastavené napěťové amplitudy.
Následně přejde do~stavu měření, ve~kterém změří rezonanční frekvenci LC~článku porovnáváním s referenčním oscilátorem.
LDC1614 má interní oscilátor s~frekvencí \(40\)~{\itshape MHz}, ale např. v~aplikacích náročných na~přesnost je~možné připojit oscilátor externí. 
V~případě využití více kanálů následně přepne na~další kanál a~opakuje stejný postup \cite{LDC1614}.

Princip tlakové plochy tedy spočívá ve~snímání vzdálenosti terčíku, se~kterým přichází do~kontaktu uživatel, čtyřmi snímacími cívkami na~LED desce.
Princip uspořádání je~zobrazen na~obrázku č.\ref{fig:nastin-tlakovky}.

Kromě katalogových listů čipu LDC1614 jsem vycházel i~z~informací uvedených v~aplikační poznámce firmy Texas Instruments \cite{LDC1614SensorDesign} a~ze skript předmětu Mikrosenzory a mikroelektromechanické systémy \cite{SkriptaMMS}

\begin{figure}[h!]
    \centering
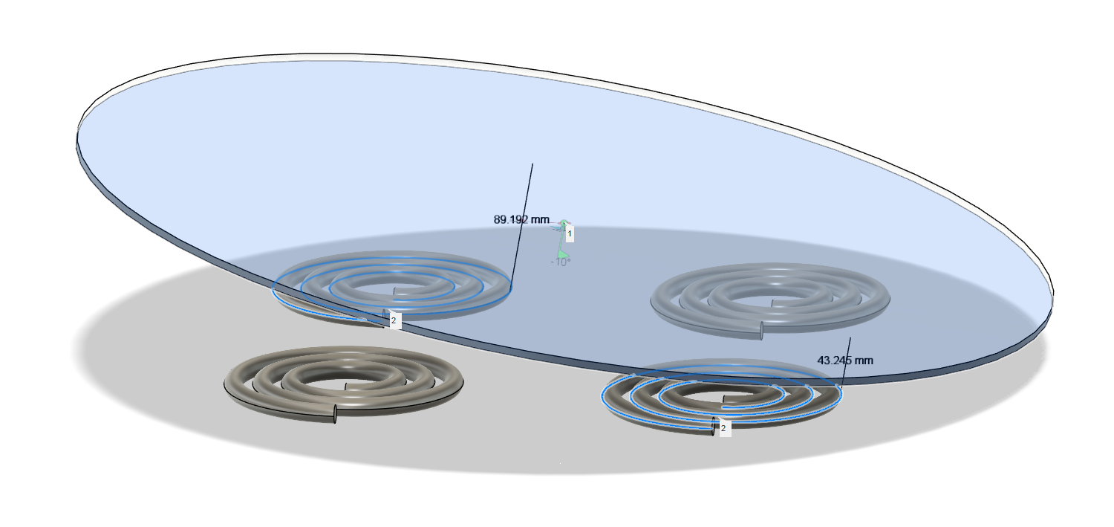
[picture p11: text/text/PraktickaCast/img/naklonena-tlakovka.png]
    
    \caption{Nástin principu snímání tlakové plochy}
    \label{fig:nastin-tlakovky}
\end{figure}

\subsection{Propojení hlavní desky a~LED desky}
Mezi hlavní deskou a~LED deskou je~třeba převést napájení a~několik signálů.
LED deska vyžaduje na~konektoru přítomnost dvou napájecích větví, \(5~V\) pro světelné kruhy a~\(3.3~V\) pro snímání tlakové plochy.
Protože do~RGB diod může téct proud až~\(5~A\) a~může být zároveň i~rychle spínaný, považuji za~rozumné oddělit napájecím větvím zem, abych omezil průnik rušení z~diod do~snímání tlakové plochy.
Oddělení je~tedy provedeno už~na konektoru hlavní desky a~už~v~kabelu jsou tedy větve vedeny samostatně.

Na samotné propojení jsem se~rozhodl použít FFC kabel s~roztečí \(0.5~mm\), pro jeho rozměry a~cenovou dostupnost.
Jedním vodičem takovéhoto kabelu lze vést proud maximálně \(0.4~A\) \cite{FFC-konektor}.
Protože ale potřebuji dodat proud až~\(5~A\), použiji \(13\) vodičů vedle sebe pro jednu cestu, jakožto nejmenší počet, který přenese~požadovaný proud v~rámci daných mezí.

Mimo napájení je~tímto propojením veden i~signál s~daty pro světelné kruhy a~I2C sběrnice se~signálem přerušení pro připojení čipu LDC1614 \cite{LDC1614}.
Výsledný počet vodičů v~kabelu je~tedy \(2 \cdot 13\) pro napájení, \(1\) pro data k~LED kruhům, dále \(2\) pro I2C, \(1\) pro signál přerušením a~nakonec \(2\) pro napájení snímání tlakové plochy.
Dohromady tedy kabel potřebuje \(32\) vodičů. 

Vzhledem k~počtu potřebných vodičů jsem se~rozhodl použít běžný FFC kabel se~40 kontakty s~tím, že~zbylé kontakty se~mohou hodit v~budoucnu.

\subsection{Modulový konektor \label{sec:ModulovyKonektor}}
Modulovým konektorem je~vedeno \(5~V\) jako napájení pro moduly a~komunikační sběrnice se~signálem přerušení pro komunikaci.

Nad volbou komunikační sběrnice jsem strávil značné množství času.
Původně jsem uvažoval o~využití RS485 jakožto odolné sběrnice, u~které by~v~případě potřeby nemusel být problém ani delší kabel.
RS485 má~ale nevýhodu v~tom, že~potřebuje dodatečný hardware, kterému bych se~hlavně na~modulech rád vyhnul.
Obdobný problém nastal u~CANu a~USB.
USB by~navíc mělo výhodu kompatibility s~velkým množstvím hotových zařízení.

V~první úvaze o~využití UARTu jsem jej zavrhl kvůli potenciální náročnosti na~přeposílání dat mezi moduly.
Při standardním použití bych totiž moduly řadil do~řetězu za~sebe.
Prvnímu modulu by~tak chodila data pro všechny ostatní moduly a~musel by~je přeposílat dál, což by~mohlo stát nezanedbatelné množství procesorového času.
%~TODO: nová linka, duvody, obhajoba

V~jisté chvíli jsem ale narazil na~nestandardní komunikaci pomocí UARTu implementované v~projektu Servio \cite{Servio}.
Tato implementace používá UART jako sběrnici.
Namísto standardního použití pro komunikace jeden-s-jedním tak může komunikovat jeden-s-více.
Na tomto řešení je~výhodné, že~nevyžaduje žádný dodatečný hardware a~prakticky každý dnešní mikrokontrolér je~možné k~této sběrnici velmi snadno připojit.

Ve srovnání s~RS485 je~sice mnohem méně odolná proti rušení, ale uvnitř zařízení nebude linka vedena na~příliš velkou vzdálenost.
Komunikace na~delším kabelu je~pak jednoduše nahraditelná bezdrátovou komunikací a~není tak potřebné, aby to~tato sběrnice v~základu podporovala.
% Navíc v~případě potřeby delšího kabelu je~možné navrhnout externí modul, který z~této sběrnice velmi jednoduše udělá RS485 pro externí využití.
% Alternativně by~se~pro komunikaci na~delším kabelu dalo použít USB, které je~společně s~nabíjením přivedeno na~USB-C.

Všechny moduly jsou připojeny na~jeden RX~pin AHS.
Proto musí firmware AHS zajistit, aby dva moduly nevysílaly současně.
Aby se~zabránilo možným zkratům, má~jako ochranu každý modul své piny UARTu připojeny přes rezistor \(180~\Omega\).
Pin~přerušení má na modulech naproti tomu jen schopnost signál přizemnit a~na straně hlavního zařízení je~dráha připojena přes rezistor k~napětí \(3,3~V\).
Abych alespoň trochu zvýšil odolnost linky proti rušení, přidám na~přijímací stranu pull-up rezistor.
Cílem je~zvýšení komunikačního proudu, aby se~případný proud vyvolaný rušením neprojevil.
V~neposlední řadě mají všechny piny na~konektoru ESD ochranu \cite{TPD4E02B04}.

\subsection{Konektor programátoru}
Zařízení se~dá jednoduše programovat přes USB-C, tento kanál je~ale možné softwarově narušit a~pro takové případy je~tu konektor na~programátor.
Jde o~šest plošek, na~které se~programátor připojuje pomocí pružinkových kontaktů.
Programátor sice obsahuje jen jednoduchou elektroniku, která by~mohla být i~přímo v~elektronice AHS, ale ve~většině případů by~byla zbytečná.
Ve chvíli, kdy by~byla potřeba, je~stejně nutná odborná obsluha a~pro tu~není problém použít externí programátor.

\subsection{USB-C}
USB-C je~použito pro nabíjení a~pohodlnější programování zařízení bez potřeby programátoru.

USB-C v~základu neposkytuje žádné napájecí napětí, protože je~navrženo k~obousměrnému provozu a může napájení jak poskytovat, tak spotřebovávat.
% Asi nejjednodušší zpusob jak požádat zdroj o~napájení je~dva rezistory s~hodnotou \(5.1~k\Omega\), přes které se~připojí signály \(CC1\) a~\(CC2\) k~zemi.
Asi nejjednodušší způsob jak požádat zdroj o~napájení, je~připojit dráhy {\it CC1} a~{\it CC2} k zemi přes rezistory o~hodnotě \(5.1~k\Omega\).
Takto zařízení dostane napětí \(5~V\) s~omezením proudu do~\(0.5~A\), tedy výkon \(2.5~W\).
V~tuto chvíli by~se~zařízení už~mohlo nabíjet, výkonem \(2.5~W\) by~se~ale nabíjelo velmi pomalu.
Proto jsem implementoval další systém, který má~za úkol zvýšit nabíjecí výkon a~tak zrychlit nabíjení.
Čip BQ25895M \cite{BQ25895} slouží primárně pro řízení nabíjení, ale zároveň se~stará o~komunikaci se~zdrojem a~zprostředkovává tak vyšší nabíjecí proud.
Velikost nabíjecího proudu se~navíc dá~v~případě potřeby nastavit přes I2C sběrnici z~ESP32-S3.

\subsection{Správa zapínání}
Zařízení je~vybaveno obvodem umožnujícím vypnutí jak uživatelské, tak programové a~v~případě hrozícího podbití i~automaticky.
Tento obvod zároveň kontroluje i~potenciální přebití baterie a~v~takovém případě odpojuje napájení nabíječky.

Původní verze správy zapínání je~vidět na~obr. \ref{fig:stary_PoverManager} (zapojení zapínacího tlačítka je~zjednodušeno, protože jeho zapojení je~složitější z~důvodu jeho čtení z~procesoru).

Na úvod popisu funkce je~vhodné říct, že~rezistor \(R_{5}\) slouží pro definici napětí na~\(G\) tranzistoru \(Q_{2}\) ve~chvíli vypnuté větve {\it 3V3} a~má~dostatečně velký odpor, aby se~při ostatních úvahách dal zanedbat.
Hlavní spínač je~PMOS tranzistor \(Q_{p1}\), který je~řízený NMOS tranzistory \(Q_{1}\) a~\(Q_{2}\).
Obvod \(U_{1}\) kontroluje stav baterie a~v~případě nízkého napětí na~dráze {\it Baterie} předpokládá, že~došlo k~limitnímu vybití baterie a~připojí na~vývod {\it OD}~(Over Discharge) \(0~V\) \cite{SL8261}.
To znamená zavřený tranzistor \(Q_{1}\), což znamená, že~se~rozepne i~tranzistor \(Q_{P1}\), protože se~jeho elektroda \(G\) vybije skrz rezistor \(R_{2}\).
Pokud je~baterie naopak nabita dostatečně, je~na vývod \(OD\)~obvodu \(U_{1}\) přivedeno jeho napájecí napětí \cite{SL8261}, v~našem případě tedy napětí baterie, které je~tak přivedeno na~\(G\) tranzistoru \(Q_{1}\).
Tranzistor \(Q_{1}\) je~tak otevřený, což znamená, že~zařízení má~povolení k~zapnutí. 
Když v~tuto chvíli dojde ke~stisku zapínacího tlačítka, přivede se~\(0~V\) na~\(G\) tranzistoru \(Q_{p1}\) a~dojde k~jeho otevření.
Následně naběhne napájecí větev {\it 3V3}, na~které bylo do~té doby \(0~V\).
Přes rezistor \(R_{4}\) se~tak přivede napětí {\it 3V3} na~\(G\) tranzistoru \(Q_{2}\) a~dojde k~jeho otevření.
Po otevření tranzistoru \(Q_{2}\) je~tranzistor \(Q_{p1}\) trvale otevřen a~zařízení je~tak zapnuto.

Následné vypnutí je~možné třemi cestami:
\begin{itemize}
    \item vybití baterie,
    \item povel z~procesoru,
    \item uživatelské tlačítko (v~pozdější verzi bylo odstraněno).
\end{itemize}

Ve chvíli, kdy dojde k~vybití baterie, zareaguje na~to obvod \(U_{1}\) rozepnutím tranzistoru \(Q_{1}\), čímž pomocí rezistoru \(R_{2}\) rozepne i~tranzistor \(Q_{p1}\) a~zařízení se~tak vypne.

Když procesor dostane příkaz k~vypnutí zařízení, stáhne dráhu {\it OFF} k~zemi, čímž vybije kapacitu \(C_{2}\) a~současně kapacitu \(G\) tranzistoru \(Q_{2}\), čímž dojde k~rozepnutí tranzistoru \(Q_{2}\).
Následně dojde k~rozepnutí tranzistoru \(Q_{p1}\) a~poklesu napětí na~napájecí větvi {\it 3V3}.
Z~této větve běží mimo jiné i~procesor a~není tedy jisté, že~udrží dráhu {\it OFF} na~napětí \(0~V\) až~do konce vypínání.
To je~důvodem přítomnosti kondenzátoru \(C_{2}\), který sice zpomalí reakci obvodu na~příkaz k~vypnutí, ale následně zajistí, že~se~obvod skutečně vypne.
Stisk tlačítka {\it OFF} má~reakci obdobnou. 

\begin{figure}[h!]
    \centering
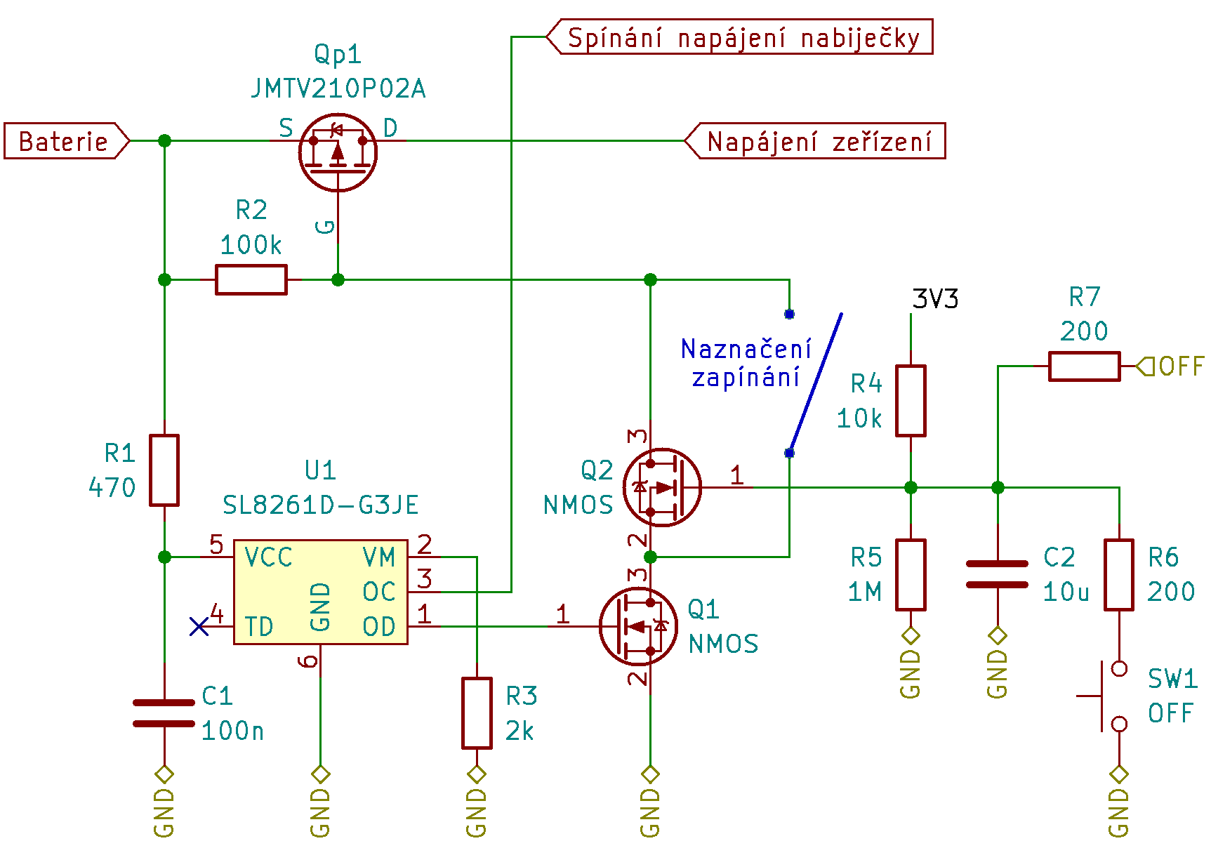
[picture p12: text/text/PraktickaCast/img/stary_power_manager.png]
    
    \caption{Původní verze správy zapínání}
    \label{fig:stary_PoverManager}
\end{figure}

Tato varianta však měla jeden problém způsobený absencí hystereze u~čipu kontrolující napětí baterie SL8261 \cite{SL8261}.
Ve chvíli, kdy se~baterie dostane do~stavu, kdy je~potřeba ji~odpojit, kontrola ji~skutečně odpojí.
To by~bylo správně, jenže z~baterie v~tu~chvíli pořád teče proud, který způsobuje úbytek jejího napětí.
Při přerušení proudu z~baterie se~tak napětí baterie lehce zvedne a~ochrana podbití tak znovu sepne.
Během této doby se~nestihne vybít kapacita na~napájecí větvi a~zařízení se~tak nestihne plně vypnout.
Obvod tak začne oscilovat a~skončí teprve až~napětí na~baterce klesne natolik, aby odpojení znovu nezvedlo napětí nad rozpoznávací úroveň čipu SL8261.

Tento problém má~dvě potenciální řešení.
Buď vyměnit obvod SL8261 za~jiný s~vhodnou hysterezí nebo upravit zapojení tak, aby v~případě, kdy se~čip SL8261 rozhodne zařízení vypnout, se~zařízení stihlo vypnout.
Následně tak už~nezáleží zda kontrola baterie zapnutí opět povolila, protože zařízení je~vypnuto klasickým způsobem.
Tato možnost navíc umožňuje zařízení uživatelsky znovu zapnout a~pokud by~zároveň výrazně klesla spotřeba, zařízení se~ještě chvíli udrží zapnuté a~uživateli tak může zahlásit vybití.
To může být výhodné, např. v~situacích, kdy se~stanoviště vybije ve~chvíli, kdy nikdo není poblíž a~když následně uživatel přijde, nemusí dlouho přemýšlet, co~se~stalo.

Obvod jsem tedy přepracoval a~doplnil jsem do~něj jeden bit paměti, do~kterého může kontrola baterie nebo mikrokontrolér zapsat a~tím zahájit vypínání.
Zároveň jsem odebral vypínací tlačítko s~tím, že~vypínání se~bude provádět programově za~pomoci běžného tlačítka, aby bylo možné nastavit časové chování tlačítka, např. vypnutí až~po delším stisku. 
Ve chvíli, kdy je~vypínání zahájeno, zařízení se~už nedá znovu zapnout až~do doby, než klesne napětí na~napájecí větvi výrazně pod napětí, při kterém by~mohlo dojít k~samovolnému zapnutí (cca \(1.5~V\)).
Výsledný obvod je~vidět na~obr. \ref{fig:PoverManager}.

Hlavní spínač je~v~tomto zapojení PMOS tranzistor \(Q_{p2}\), který je~řízený okolním zapojením.
Přivedením napětí \(0~V\) na~\(G\) tranzistoru \(Q_{p2}\) dojde k~jeho sepnutí a~následnému startu zařízení.
K~tomu může dojít sepnutím NMOS tranzistorů \(Q_{6}\) a~\(Q_{7}\).
Tranzistor \(Q_{4}\) má~stejnou funkci jako tranzistor \(Q_{1}\) v~předchozím zapojení, tedy když obvod \(U_{2}\) rozezná kriticky vybitou baterii, tranzistor rozepne.
Naopak když obvod rozezná nabitou baterii, povolí zapnutí sepnutím tranzistoru \(Q_{4}\).
Ve chvíli, kdy je~zapnutí povoleno a~uživatel stiskne \(ON\)~tlačítko, otevře tranzistor \(Q_{5}\), čímž přivede \(0~V\) na~\(G\) tranzistoru \(Q_{p2}\).
Tranzistor \(Q_{p2}\) se~tak sepne, v~reakci na~což se~uvede do~provozu napájecí větev {\it 3V3}.
To znamená, že~se~začnou skrz rezistory \(R_{12}\) a~\(R_{13}\) nabíjet kapacity \(G\) tranzistorů \(Q_{7}\), \(Q_{8}\) a~\(Q_{6}\).

Tranzistory \(Q_{7}\) a~\(Q_{8}\) spolu s~rezistory \(R_{12}\) a~\(R_{13}\) vytváří dvě do~kruhu zapojené inverze, které tak vytváří jednoduchou paměť.
Stav této paměti je~čitelný na~vývodech \(G\) obou tranzistorů, kde vždy existuje logická nula i~jednička, které se~mohou mezi sebou prohazovat a~tím udržovat informaci.
Zapnutý stav znamená logickou jedničku na~\(G\) tranzistoru \(Q_{7}\) a~nulu na~\(G\) tranzistoru \(Q_{8}\).
Při startu je~nutné, aby toto pořadí naběhlo správně a~nikoliv opačně (což by~znamenalo, že~ihned po~zapnutí dojde k~vypnutí).
Aby tedy se paměť při startu správně inicializovala, mají rezistory \(R_{12}\) a~\(R_{13}\) různé hodnoty, přesněji \(R_{12}\) má~větší odpor a~napětí na~\(G\) tranzistoru \(Q_{8}\) tak bude nabíhat pomaleji.
Napětí na~\(G\) tranzistoru \(Q_{7}\) tak dosáhne jeho otevření dříve, čímž přivede \(0~V\) na~\(G\) tranzistoru \(Q_{8}\), který tak zavře, čímž se~stav paměti ustálí.
Zvláštní hodnota rezistoru \(R_{12}\) je~způsobena snahou o~minimalizaci součástek.
Tuto hodnotu jsem již použil jinde na~zařízení a~abych tedy nemusel přidávat další hodnotu rezistoru, použil jsem tuto.

Aby měly takto vytvořené paměti smysl, je~nutné zajistit, aby žádný ze~zdrojů neměl dvojčinný [push-pull] výstup nebo aby alespoň uměl pracovat v~režimu s~vysokou impedancí.
Výstup z~mikrokontroléru toto umí zajistit jednoduše programově.
Obvod \(U_{1}\) hlídající napětí baterie má~ale výstup dvojčinný z~důvodu potřeby přímého řízení tranzistoru NMOS a~musím ho~to tedy ošetřit jinak.
Zvolil jsem řízení na~straně logické jedničky v~zapnutém stavu, aby vypnutí znamenalo stažení dráhy k~zemi.
Alternativou by~totiž bylo tahat dráhu k~napájecí větvi {\it 3V3}, což by~znamenalo dodatečné zapojení, protože obvod \(U_{2}\) je~napájený jiným napětím než mikrokontrolér a~tedy než tato paměťová buňka.
Mikrokontrolér stažením dráhy \(OFF\) spojí dráhu ze~zemí přes, pro naši úvahu zanedbatelný, ochranný rezistor \(R_{76}\).
Ochrana podbití je~pak připojena přes tranzistor \(Q_{3}\), z~něhož je~využita jen jeho dioda.
Namísto tranzistoru \(Q_{3}\) by~mohla být zapojena jen samostatná dioda, tranzistor je~zde použit z~obdobného důvodu jako zvláštní hodnota rezistoru \(R_{12}\) a~to, aby nebylo nutné do~zařízení přidávat další typ součástky.

Ve chvíli, kdy do~zapojení přijde povel k~vypnutí, zapíše se~povel nejprve do~této paměti.
Toto je~ostatně další důvod, proč se~do paměti zapisuje přes \(G\) tranzistoru \(Q_{7}\) a~ne~\(G\) tranzistoru \(Q_{8}\).
Kdyby totiž zápis probíhal z~druhé strany, zařízení by~se~začalo vypínat už~v~době zápisu do~paměti, protože by~probíhal na~straně, která řídí tranzistor \(Q_{p2}\).
Když tedy dojde k~zápisu do~paměti a~tranzistor \(Q_{p2}\) se~rozepne, začne padat napětí na~napájecí větvi {\it 3V3}, na~rozdíl od~dřívějšího zapojení, ale během toho nemůže dojít k~samovolnému zapnutí.
Protože aby mohlo dojít k~zapnutí, musel by~se~sepnout tranzistor \(Q_{7}\), což se~ale stát nemůže, protože je~sepnut tranzistor \(Q_{8}\). 
Tranzistor \(Q_{8}\) se~rozepne teprve ve~chvíli, kdy napětí na~napájecí větvi {\it 3V3} poklesne natolik, aby už~neudrželo tranzistor sepnutý a~v~tu~chvíli už~nemůže dojít k~sepnutí tranzistoru \(Q_{7}\).

\begin{figure}[h!]
    \centering
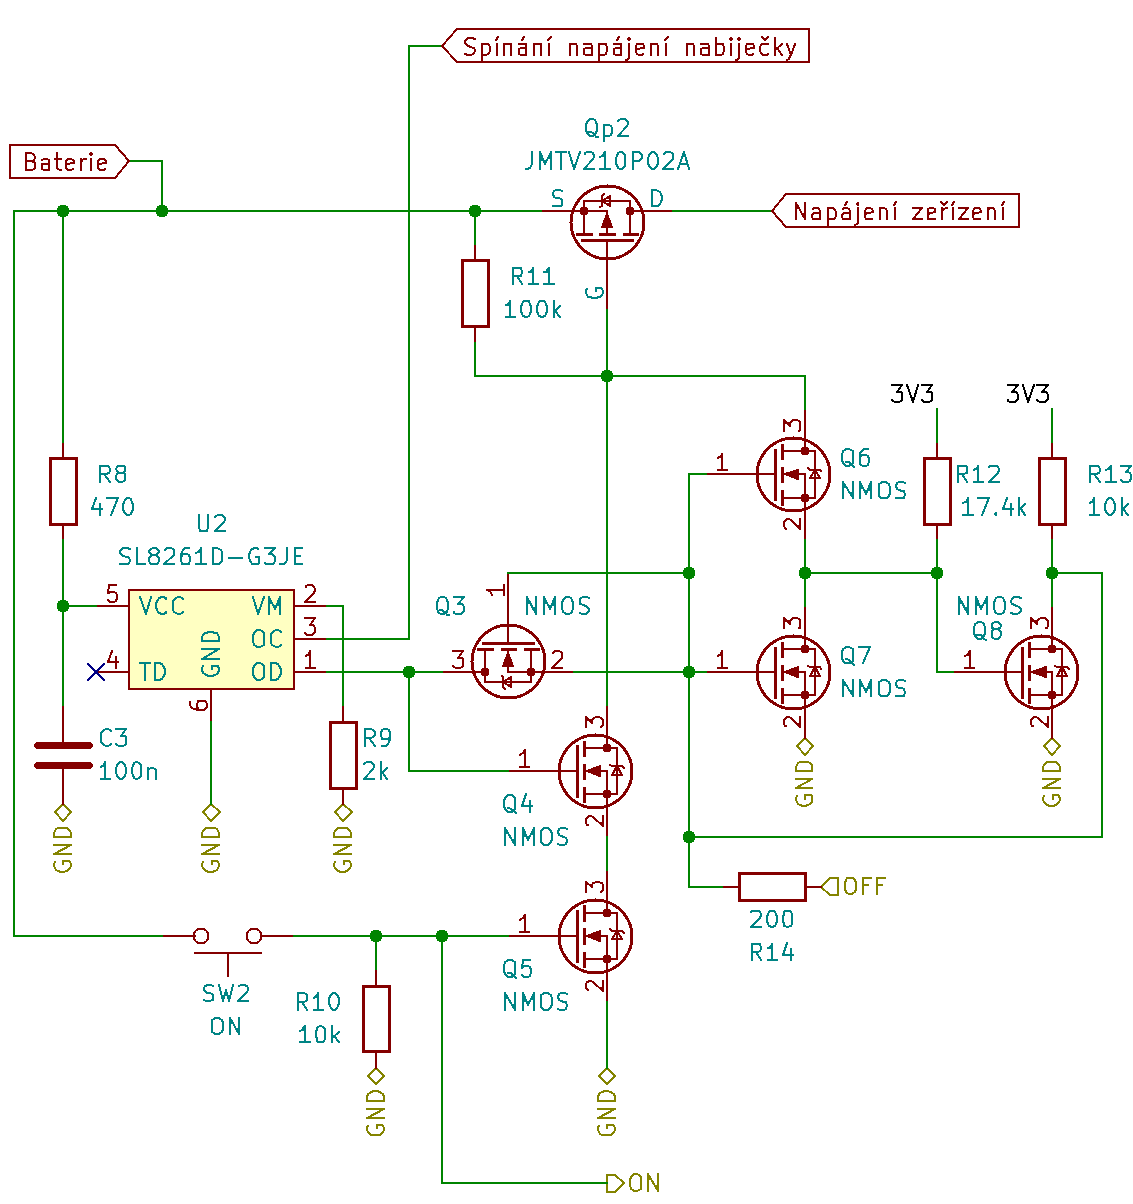
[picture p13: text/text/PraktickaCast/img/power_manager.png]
    
    \caption{Nová verze správy zapínání}
    \label{fig:PoverManager}
\end{figure}

Přestože~\(G\) tranzistoru \(Q_{p2}\) je~řízený stranou paměti \(G\) tranzistoru \(Q_{8}\), tyto dráhy musí být částečně odděleny.
V~případě přímého spojení by~totiž paměťová buňka nemohla správně plnit svoji funkci, protože by~na~ni~bylo skrz rezistor \(R_{11}\) ve~vypnutém stavu přivedeno napětí baterie.
To by~mělo za~následek růst spotřeby ve~vypnutém stavu zaviněný částečným startem zařízení a~především nemožnost normálního startu.
Skrze resistory \(R_{11}\) a~\(R_{12}\) by~se~totiž dostalo napětí baterie na~napájecí větev {\it 3V3}, kde by~mohlo některé systémy uvést do~provozu.
Proud tekoucí přes rezistory \(R_{11}\) a~\(R_{12}\) by~dosahoval řádově desítek mikroampér, což by~spotřebu ve~vypnutém stavu navýšilo přibližně o~řád.
Významnější problém by~ale byl otevřený tranzistor \(Q_{8}\), který by~tak držel zavřený tranzistor \(Q_{7}\), což by~znemožnilo nemožnost správného startu zařízení.
Řešením tohoto problému je~tranzistor \(Q_{6}\), který se~sepne jen ve~chvíli, kdy je~v~paměti zapsána správná hodnota.
Tehdy je~jeho \(S\) připojeno skrze tranzistor \(Q_{7}\) k~zemi a~jeho \(G\) skrze rezistor \(R_{13}\) k~napětí \(3,3~V\) a~je~tedy plně otevřen.
Naopak ve~chvíli, kdy je~do paměti zapsán povel k~vypnutí, je~na jeho \(S\) připojeno skrze rezistor \(R_{12}\) napětí napájecí větve {\it 3V3} a~jeho \(G\) skrze tranzistor \(Q_{8}\) k~zemi a~je~tedy plně uzavřen.
Tímto způsobem je~tedy zajištěno oddělení paměťové buňky od~\(G\) tranzistoru \(Q_{p2}\).

\subsection{Výkonová napájecí větev}
Jako napájecí napětí pro výkonové části zařízení slouží napětí \(5~V\), protože toto napětí využívají světelné kruhy, skládající se~z~LED WS2812 \cite{WS2812B}.
Tyto LED mají rozsah napájecího napětí \(3,5\) až~\(5,3~V\), a~právě proto volím napájecí napětí \(5~V\).
Stačilo by~sice i~napětí nižší, ale s~větví \(3,3~V\) bych výkonovou větev tak jako tak nespojil.
Především by tak však byl nutný složitější spínaný zdroj, který by~musel spínat nejen na~vyšší napětí, ale i~na~nižší, podle toho jaké napětí je~zrovna na~baterii.
Navíc je~napětí \(5~V\) vhodný i~pro napájení na~modulovém konektoru.

Vznikají tak dva systémy, které jsou napájeny napětím \(5~V\), především LED kruhy ale také moduly připojené na~modulovém konektoru.
Protože oba tyto systémy mohou mít nezanedbatelnou spotřebu i~ve~chvíli, kdy nejsou používány, je~vhodné mít možnost odpojit je~od napájení.
Použité LED mají totiž spotřebu i~ve vypnutém stavu \(0,5~mA\), což při počtu \(120\) LED dělá klidovou spotřebu \(60~mA\).
U~modulu toto sice neumím říct dopředu, ale dá se předpokládat, že bude výhodné moduly vypínat.

Čím jemnější dělení, tím lépe půjde optimalizovat spotřeba.
Protože jsou všechny moduly připojeny na~stejném konektoru, znamená to~dvě samostatně řiditelné větve.
Navíc je~vhodné vypínat i~samotný zdroj obou větví ve~chvíli, kdy není využíván.
Za tímto účelem jsem tedy implementoval schéma na~obr.\ref{fig:spinac_vikonove_vetve}

\begin{figure}[h!]
    \centering
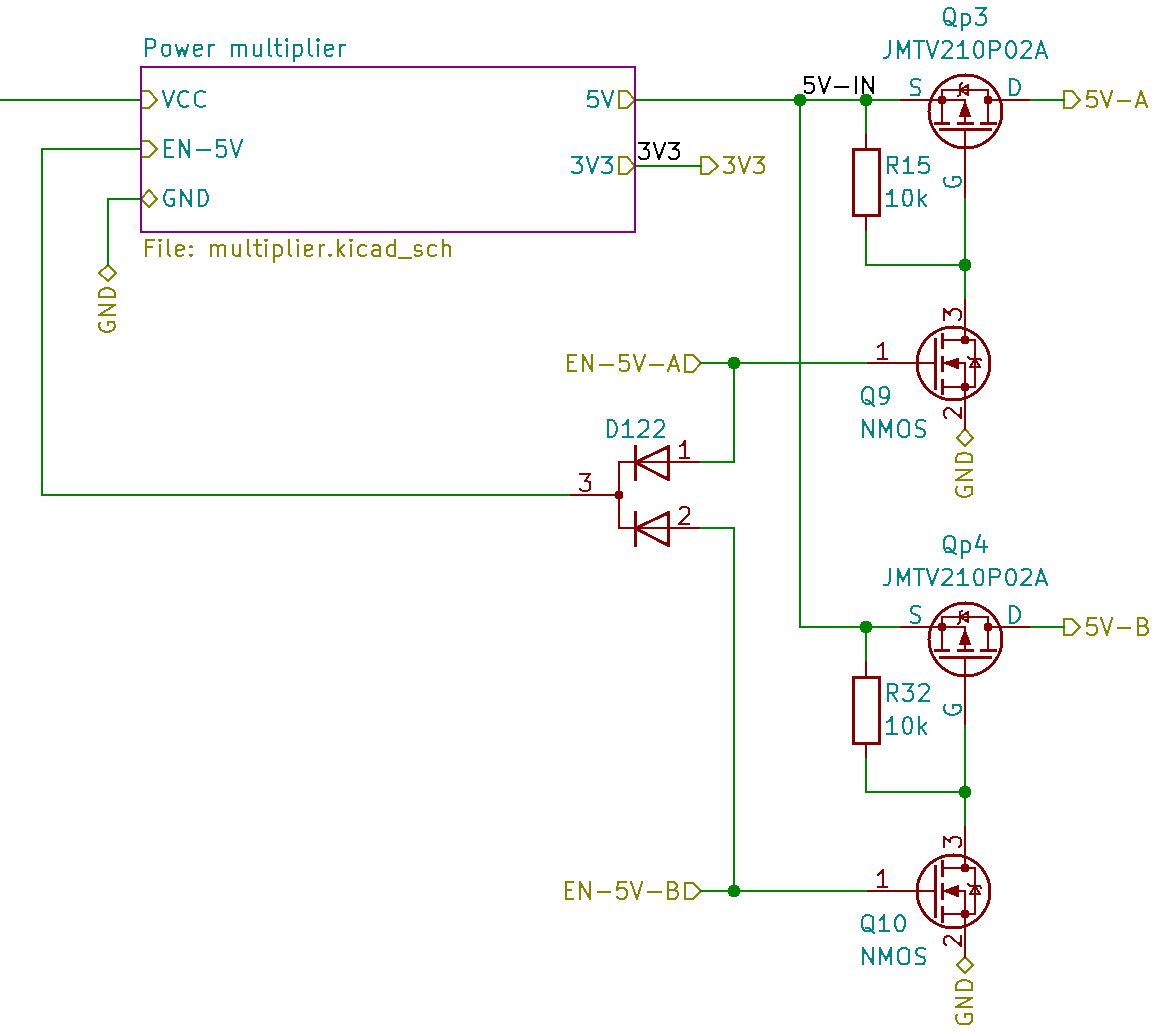
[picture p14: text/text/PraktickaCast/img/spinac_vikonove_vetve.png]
    
    \caption{Spínač výkonové větve}
    \label{fig:spinac_vikonove_vetve}
\end{figure}

Výchozí stav vstupů {\itshape EN-5V-A} a~{\itshape  EN-5V-B} je~\(0~V\), což je~definováno pomocí rezistorů, které tyto dráhy připojuje k~zemi.
Tyto rezistory však ve~schématu na~obr.\ref{fig:spinac_vikonove_vetve} nenajdete, protože jsou součástí schématu s~mikrokontrolérem.
Tam jsou zároveň použity k~definici výchozího stavu pinů {\it IO45} a~{\it IO46}, které se~používají při startu procesoru.
Ve výchozím stavu drah {\itshape EN-5V-A} a~{\itshape EN-5V-B} je~tedy \(0~V\), což znamená rozpojené tranzistory \(Q_9\) a~\(Q_{10}\).
Výsledkem rozpojení tranzistorů \(Q_9\) a~\(Q_{10}\) je~tedy za~pomocí rezistorů \(R_{15}\) a~\(R_{32}\) i~rozpojení tranzistorů \(U_{9}\) a~\(U_{15}\).
Současně s~tím je~\(0V\) i~na~dráze {\itshape EN-5V}, která řídí spínaný zdroj základní pěti voltové větve.
Výchozí stav této dráhy je~opět definovaný připojením k~zemi přes rezistor, který je~tentokrát umístěn ve~schématu spínaného zdroje.
Ve chvíli, kdy dojde z~procesoru povel k~zapnutí jedné z~větví, řekněme větve {\itshape 5V-A}, mikrokontrolér přivede napětí \(3,3~V\) na~dráhu {\itshape EN-5V-A}.
Tedy přivede napětí \(3,3~V\) na~\(G\) tranzistor \(Q_9\), čímž jej sepne a~zároveň skrze jednu diodu \(D_{122}\) na~{\itshape EN-5V}, čímž uvede do~provozu spínaný zdroj a~tedy přivede napětí na~dráhu \(5V\).
Následkem sepnutí tranzistoru \(Q_9\) se~přivede \(0~V\) na~\(G\) tranzistoru \(U_{9}\), čímž se~sepne a~přivede napětí \(5V\) na~dráhu {\itshape 5V-A}.
Obdobně pak v~případě aktivace dráhy {\itshape 5V-B}.

%~\newpage

\subsection{Jednoduchá signalizační LED}

Pro signalizaci některých stavů jsem do~zařízení přidal i~obyčejnou RGB LED.
Je~řiditelná z~mikrokontroléru, ale ve~chvíli, kdy ji~mikrokontrolér aktivně neřídí, může slabým svitem signalizovat i~některé hardwarové stavy.
Červeným kanálem signalizuje, že~je zařízení v~chodu a~modrým kanálem informuje o~stavu nabíjení.
Když nabíjení probíhá, svítí modrý kanál trvale.
Když nabíjení neprobíhá, např. když je~dokončeno, modrý kanál nesvítí a~v~případě, že~nabíjecí obvod BQ25895 \cite{BQ25895} detekuje nějaký problém, bliká s~frekvencí \(1 Hz\).
Zapojení LED je~vidět na obr. \ref{fig:hloupa-LED}.

\vspace{-3mm}
\begin{figure}[h!]
    \centering
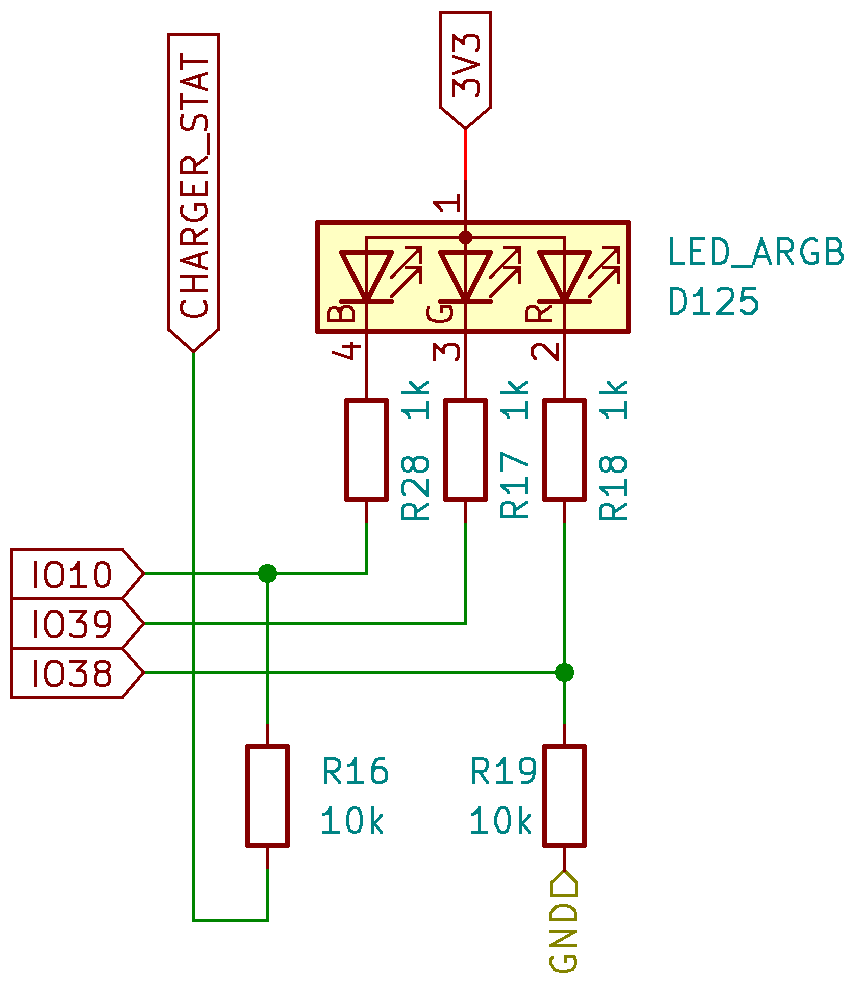
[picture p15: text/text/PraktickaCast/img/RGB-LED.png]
    
    \caption{Zapojení prosté signalizační RGB LED}
    \label{fig:hloupa-LED}
\end{figure}
\vspace{-2mm}

Zdvojení řízení LED umožňují dodatečné odpory \(R_{16}\) a~\(R_{19}\).
Ve chvíli, kdy je~tak např. pin mikrokontroléru pin \(IO38\) ve~stavu vysoké impedance, je~červený kanál diody vlastně připojen přes odpor \(11~k\Omega\) k~zemi.
Výsledný jas diody sice není vysoký, ale informaci uživateli předá.

\subsection{Odhad spotřeby zařízení}
Spotřeba zařízení bude silně záviset na~typu využívání.
Některé hry například mohou vyžadovat jen jednu-dvě svítící LED naráz a~jiné naopak mohou pracovat se~všemi naráz.
Navíc budou spotřebu ovlivňovat aktuálně připojené moduly.
Pro odhad tedy budu předpokládat spíše náročnější podmínky, aby byl odhad spíše skeptický.

Předpokládám využití jednoho světelného kruhu s~osmdesáti procentním jasem jednoho kanálu LED.
Zároveň předpokládám běžící tlakovou plochu a~bezdrátovou komunikaci.
U spínaného zdroje, který zprostředkovává napájení větve \(U_{OUT} = 5~V\) předpokládám efektivitu \(\mu = 95\-\%\) \cite{TPS61088}.
Nakonec aktuální napětí baterie \(U_{bat} = 3,5~V\). 

\begin{itemize}
    \item LED WS2812 \cite{WS2812B-cinsky}
    \begin{itemize}
        \item spotřeba jednoho kanálu je~dle dokumentace \(12~mA\), při osmdesáti procentním jasu tedy \(I_{LED-k} = 9,6~mA\)
        \item fixní spotřeba řídící elektroniky celé LED \(I_{LED-d} = 0,5~mA\)
    \end{itemize}
    \item Moduly 
    \begin{itemize}
        \item průměrnou spotřebu modulu předpokládám na~\(I_{mod} = 50~mA\) (předpokládám, že moduly budou pracovat jen malé procento času) 
    \end{itemize}
    \item Tlaková plocha
    \begin{itemize}
        \item spotřeba LDC1614 je~\(I_{LDC} = 35~\mu A\) \cite{LDC1614}
    \end{itemize}
    \item ESP32-S3
    \begin{itemize}
        \item spotřebu při využívání WiFi odhaduji na~základě měření uvedeného v~dotazu na ESP32 foru \cite{spotreba-ESP32S3} jako \(I_{ESP} = 150~mA\)
    \end{itemize}
\end{itemize}

\vspace{5mm}
\large
\begin{centering}
\(
    I_{bat} = \frac{U_{OUT}}{U_{bat} \cdot \mu} \cdot (60 \cdot (I_{LED-k} + I_{LED-d}) + I_{mod}) + I_{LDC} + I_{ESP} = 
    \frac{5}{3.5 \cdot 0.95} \cdot (60 \cdot (12\cdot10^{-3} \cdot 0.8 + 0.5\cdot10^{-3}) + 50\cdot10^{-3}) + 35\cdot10^{-3} + 150\cdot10^{-3} = 1.17~[A]
\)
\end{centering}
\normalsize
\vspace{1mm}

Při kapacitě jednoho článku baterie \(C_{čla} = 3400~mAh\) \cite{kapacita-18650}, tedy dvojnásobné kapacitě celé baterie, tak můžeme určit výdrž na~jedno nabití jako:

\vspace{3mm}
\large
\( t_{vyd} = \frac{2 \cdot C_{čla}}{I_{bat}} = \frac{2 \cdot 3.4}{1.17} = 5.8 [h] \)  \normalsize resp. \( 5~hodin + 48~minut \)
\vspace{3mm}

To sice vychází na~trochu míň, než jsem na~začátku kapitoly požadoval, ale dá se~předpokládat, že během nastavování bude spotřeba nižší.
Předpokládám totiž, že při nastavování nebudou LED svítit tak vysokým jasem.
% Dost možná nebudou svítit vůbec, protože se~vše nastaví z~telefonu.

Kromě spotřeby za provozu je~také vhodné určit spotřebu zařízení ve~vypnutém stavu.
Nebylo by totiž vhodné, aby během nečinnosti došlo k~podbití baterie a~tím pádem k~jejímu poškození.

Na spotřebu ve~vypnutém stavu má vliv několik součástek.
Jde především o~proud, tekoucí do~nabíjecího obvodu bq25895M \cite{BQ25895}, ale také o~ochranu baterie SL8261D \cite{SL8261} a~několik tranzistorů v~zapínacím obvodu uvedeném na~obr.~\ref{fig:PoverManager}.

\begin{itemize}
    \item Dokumentace nabíjecího obvodu bq25895M \cite{BQ25895} udává spotřebu ve~stavu nečinnosti \(I_{nab} = 12~\mu A\).
    \item Ochrana baterie SL8261D \cite{SL8261} udává spotřebu v~sepnutém stavu \(I_{och} = 3~\mu A\).
    \item Hlavní spínací MOS transistor \cite{WSD20L75DN33} udává proud v~rozepnutém stavu maximálně \(I_{PMOS} = 1~\mu A\).
    \item Dva logické MOS transistor \cite{N-MOS} udává proud v~rozepnutém stavu maximálně \(I_{NMOS} = 1~\mu A\).
\end{itemize}

Výslednou spotřebu ve~vypnutém stavu tak můžeme určit jako:

\vspace{5mm}
\large
\begin{centering}
\(
    I_{vyp} = I_{nab} + I_{och} + I_{PMOS} + I_{NMOS} = (12 + 3 + 1 + 1) \cdot 10^{-6} = 17 [\mu A]
\)
\end{centering}
\normalsize
\vspace{1mm}

Při této spotřebě tedy určíme dobu za kterou by se~zařízení vybilo jako:

\vspace{5mm}
\large
\begin{centering}
\(
    t_{vyd} = \frac{2 \cdot C_{čla}}{I_{vyp}} = \frac{2 \cdot 3.4}{17 \cdot 10^{-6}} = 3.9\cdot10^{5}~[h] \) resp. \(\frac{3.9\cdot10^{5}}{24\cdot365} \approx 46~[let]\)
\end{centering}
\normalsize
\vspace{1mm}

Spotřeba ve~vypnutém stavu je~tedy víc než dostatečně malá.
Nepodařilo se~mi najít hodnoty samovybíjení použitých článků, ale dá se~předpokládat, že budou řádově větší než spotřeba elektroniky ve~vypnutém stavu.

\section{Mechanická stavba}
Celé zařízení bude mít tvar krátkého válce.
Na~horní stranu je~umístěn axiální světelný kruh, do~kterého je~umístěna tlaková plocha.
Na bocích je~pak umístěn radiální světelný kruh a~základní uživatelské ovládání.

Z~důvodu minimalizace součástí je~výhodné LED radiálního světelného kruhu umístit na~LED desku místo na~samostatný díl.
Zároveň je~to způsob, jak se~vyhnout montáži současně radiální i~axiální.
Na prvním prototypu jsem totiž zvolil možnost osadit jen axiální kruh a~radiální jsem vytvořil pomocí LED pásku, který jsem omotal kolem krytu zařízení.
Výsledkem byla neprakticky komplikovaná montáž, kterou se~i~touhle cestou snažím co~možná nejvíc zjednodušit bez ztráty výsledné kvality.

Axiální kruh osazený přímo na~DPS ovšem znamená další komplikaci, jeho účelem je~totiž svítit ve~směru rovnoběžném s~plochou DPS.
Použité LED tedy musí svítit v~ose~rovnoběžné s~plochou desky.
To se~dá zařídit buď do~strany svítícími LED nebo zajistit odraz světla do~stran, tak aby mohly diody svítit ve~směru kolmém na~plochu DPS a~aby přesto vzniklý světelný kruh svítil radiálně.

Do strany svítící inteligentní LED sice existují, ale nemají vhodné rozměry a~navíc jsou výrazně dražší.
Proto jsem se~rozhodl použít stejné diody jako na~axiálním kruhu a~doplnit tělo zařízení o~odraznou plochu, která zajistí správný výsledný směr světla.
Zároveň, abych pokud možno zachoval rozlišitelnost jednotlivých LED, jsem mezi ně~přidal přepážky.
Jejich cílem je~minimalizovat přesvity jednotlivých diod do~prostor diod sousedních.
Obojí je~vidět na~obr.\ref{fig:AHS-radializatoru}.

\begin{figure}[h!]
    \begin{minipage}{0.5\textwidth}
        \centering
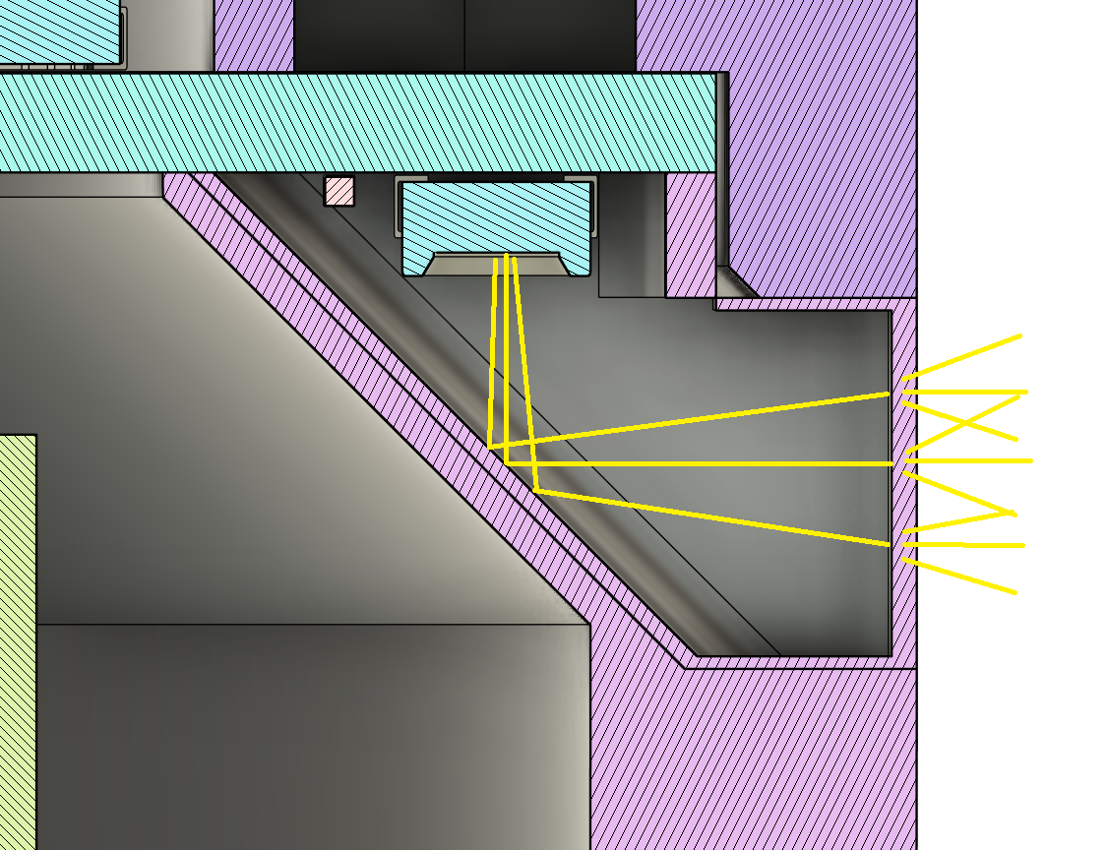
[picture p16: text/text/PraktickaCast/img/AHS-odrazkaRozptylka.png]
        
    \end{minipage}
    \begin{minipage}{0.5\textwidth}
        \centering
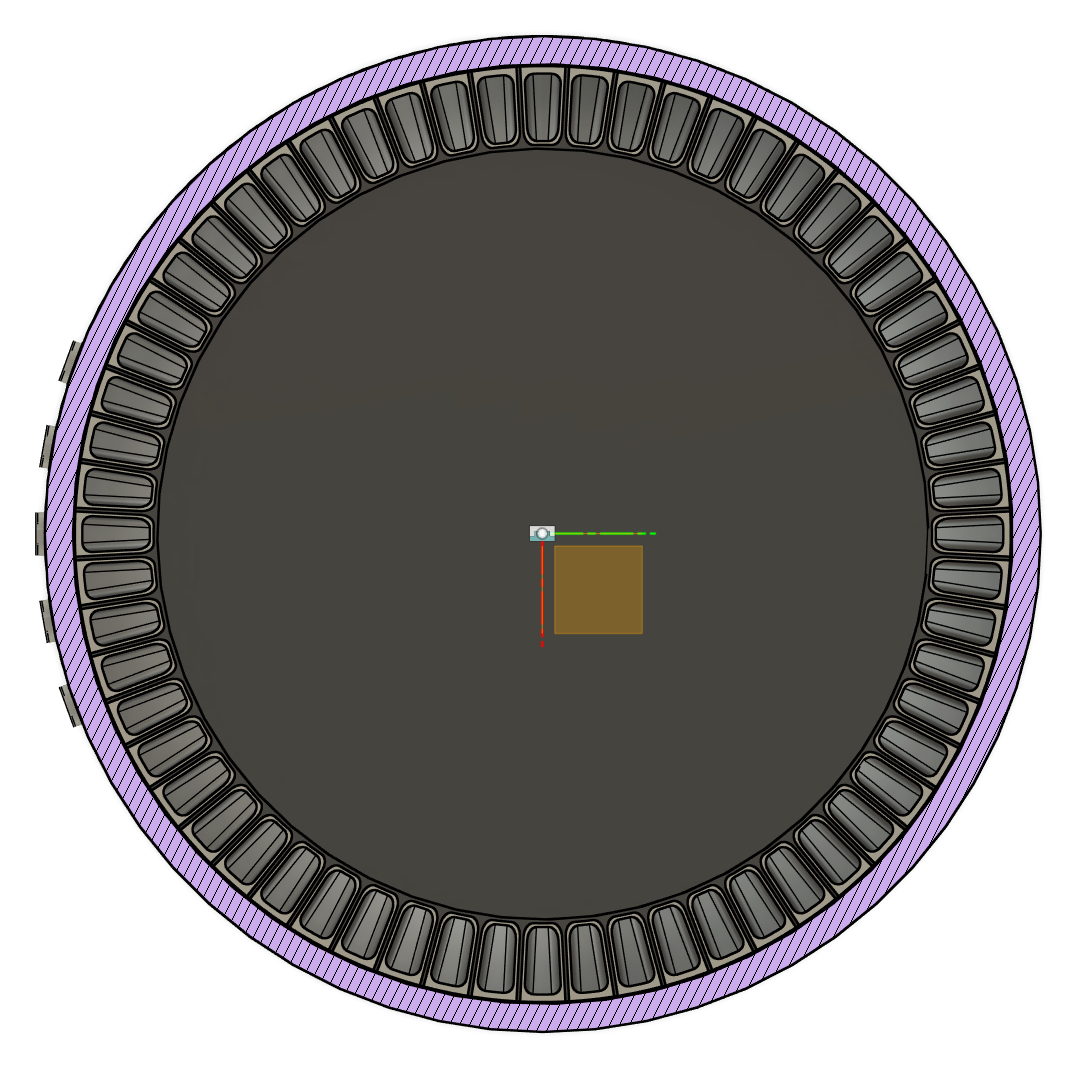
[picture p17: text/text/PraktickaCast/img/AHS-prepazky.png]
        
    \end{minipage}
    \caption{Odrazná plocha a~přepážky Radiálního světelného kruhu}
    \label{fig:AHS-radializatoru}
\end{figure}

Významnou mechanickou částí je~také uložení tlakové plochy.
Tento systém se~skládá ze~snímací části, která je~součástí LED desky a~snímané části, terčíků, se~kterou je~v~kontaktu uživatel.
Terčíky se~musí při používání pohybovat, sice málo ale za~to konzistentně, aby bylo možné výsledek použít jako ovládací prvek.
Protože se~navíc tlaková plocha nachází uvnitř axiálního světelného kruhu, je~nutné, aby byl terčík buď průsvitný nebo uchycený až~uvnitř kruhu.
Uchycení uvnitř kruhu by~ale znamenalo zmenšení snímatelné plochy a~potřebu poměrově výraznějších deformací, aby se~dosáhlo stejné změny indukčnosti.
Abych minimalizoval velikost nesnímaných okrajů, rozhodl jsem se~pro průsvitnou variantu.

V~první verzi jsem tedy terčíky řešil tenkým plošným spojem, na~kterém jsem odleptal vše kromě kruhu o~něco málo menšího než vnitřní průměr světelného kruhu.
Měď tak sloužila jako vodivý terčík.
Sklolaminát, který tvoří nosnou část DPS, sice není úplně čirý a~způsobuje tak difuzi světla, ta~ale v~tomto případě nevadí.
Tuto DPS jsem následně přilepil na~tělo zařízení, těsně nad LED desku na~mezikruží obklopující světelný kruh.
Zvolil jsem tedy \(0.6~mm\) tlustá FR4 DPS.
Tloušťku jsem zvolil tak, abych umožnil co~možná největší deformace a~ulehčil tak rozlišování skutečného stisku od~nežádoucího šumu.

Tato metoda však měla pár nedostatků.
Především \(0.6~mm\) tlustá FR4 DPS nebyla dostatečně stálá a~docházelo k~její postupné trvalé deformaci.
Po několika měsících tak DPS začala tvarem připomínat misku, což vedlo k~porušení lepidla a~bylo tak nutné ji~lepit znovu.
Rozhodl jsem se~proto DPS zesílit, aby trvalým deformacím lépe odolala.

%~Rozhodl jsem se~proto vyzkoušet dvě alternativní řešení:
%~\begin{enumerate}
%~    \item Tlustší FR4 DPS
%~    \item DPS s~hliníkovým jádrem
%~\end{enumerate}

%~Tlustší FR4 DPS by~měla výhodu v~tom že~je principiálně stejná jako předchozí varianta a~vyžadovala by~tedy jen minimální upravu.
%~Nevýhodou by~naopak mohl být stále stejný problém s~tím že~by se~jen prodloužil čas kdy funguje dle požadavku. 
%~DPS s~hliníkovým jádrem by~měla naopak výhodu stálosti ale zase~by~se~objevil problém s~průsvitností.

%~Rozhodl jsem se~tedy vyzkoušet obojí

Samotný kryt zařízení jsem rozdělil na~několik částí, jejichž sestava je~vidět na~obr.\ref{fig:AHS-kryt}
\begin{itemize}
    \item Hlavní tělo, jehož součástí je~odrazná plocha pro radiální světelný kruh a~hmatník tlačítek, který je~součástí těla z~důvodu těsnosti zařízení
    \item Horní okraj, který překrývá okraje LED desky a~usazuje DPS terčíku
    \item Zadní víko, které se~šroubuje do~závitu v~hlavním těle a~zajišťuje tak uchycení hlavní desky a~zároveň uzavírá zařízení
    \item Distanční přítlačná vložka, zajištující rovinnost plochy hlavní desky v~místech kontaktu s~šroubovacím víkem
    \item Dodatečný díl, který by~ideálně byl součástí hlavního těla, ale pro usnadnění tisku je~oddělen, tisknut zvlášť a~následně pomocí pozičních výstupků zapozicován a~nalepen k~hlavnímu tělu  ~
\end{itemize}

\begin{figure}[h!]
    \centering
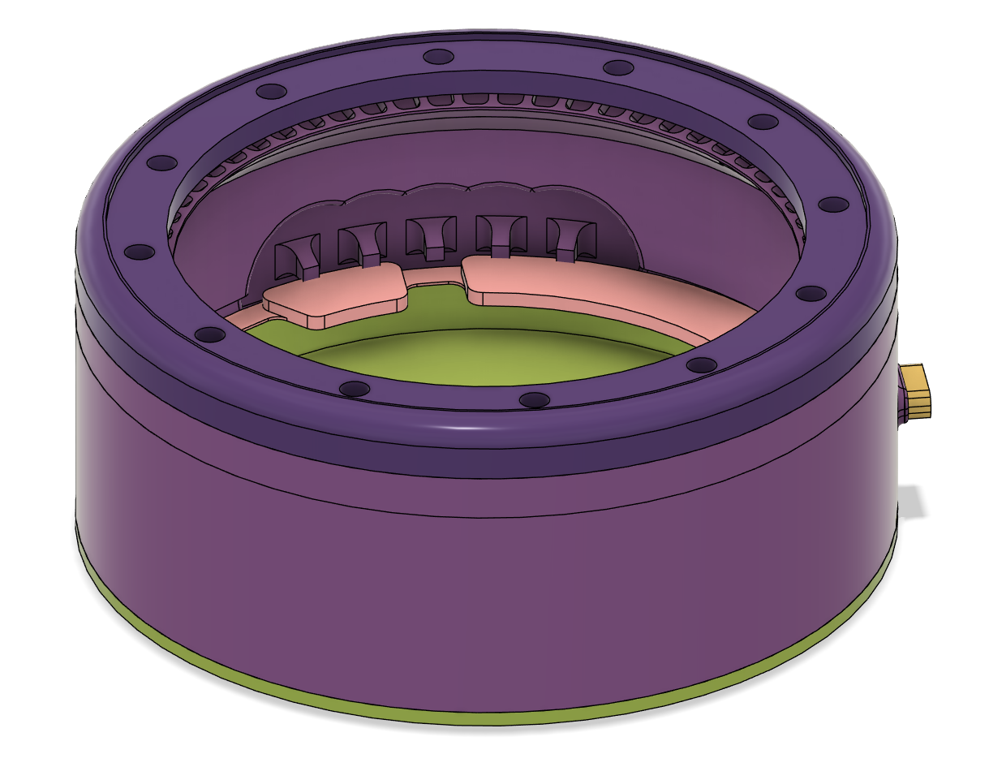
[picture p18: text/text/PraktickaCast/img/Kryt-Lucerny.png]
    
    \caption{Sestava krytu bez elektroniky a~terčíku tlakové plochy}
    \label{fig:AHS-kryt}
\end{figure}

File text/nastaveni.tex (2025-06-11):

% V tomto souboru se nastavují téměř veškeré informace, proměnné mezi studenty:
% jméno, název práce, pohlaví atd.
% Tento soubor je SDÍLENÝ mezi textem práce a prezentací k obhajobě -- netřeba něco nastavovat na dvou místech.

\usepackage[
%%% Z následujících voleb jazyka lze použít pouze jednu
  czech-english,		% originální jazyk je čeština, překlad je anglicky (výchozí)
  %english-czech,	  % originální jazyk je angličtina, překlad je česky
  %slovak-english,	% originální jazyk je slovenština, překlad je anglicky
  %english-slovak,	% originální jazyk je angličtina, překlad je slovensky
%
%%% Z následujících voleb typu práce lze použít pouze jednu
  %semestral,		  % semestrální práce (výchozí)
  bachelor,			%	bakalářská práce
  %master,			  % diplomová práce
  %treatise,			% pojednání o disertační práci
  %doctoral,			% disertační práce
%
%%% Z následujících voleb zarovnání objektů lze použít pouze jednu
%  left,				  % rovnice a popisky plovoucích objektů budou zarovnány vlevo
	center,			    % rovnice a popisky plovoucích objektů budou zarovnány na střed (vychozi)
%
]{thesis}   % Balíček pro sazbu studentských prací

%%% Jméno a příjmení autora ve tvaru
%  [tituly před jménem]{Křestní}{Příjmení}[tituly za jménem]
% Pokud osoba nemá titul před/za jménem, smažte celý řetězec '[...]'
\author[]{Tomáš}{Vavrinec}

%%% Identifikační číslo autora (VUT ID)
\butid{240893}

%%% Pohlaví autora/autorky
% (nepoužije se ve variantě english-czech ani english-slovak)
% Číselná hodnota: 1...žena, 0...muž
\gender{0}

%%% Jméno a příjmení vedoucího/školitele včetně titulů
%  [tituly před jménem]{Křestní}{Příjmení}[tituly za jménem]
% Pokud osoba nemá titul před/za jménem, smažte celý řetězec '[...]'
\advisor[doc.\ Ing..]{Pavel}{Šteffan}[Ph.D.]

%%% Jméno a příjmení oponenta včetně titulů
%  [tituly před jménem]{Křestní}{Příjmení}[tituly za jménem]
% Pokud osoba nemá titul před/za jménem, smažte celý řetězec '[...]'
% Nastavení oponenta se uplatní pouze v prezentaci k obhajobě;
% v případě, že nechcete, aby se na titulním snímku prezentace zobrazoval oponent, pouze příkaz zakomentujte;
% u obhajoby semestrální práce se oponent nezobrazuje (jelikož neexistuje)
% U dizertační práce jsou typicky dva až tři oponenti. Pokud je chcete mít na titulním slajdu, prosím ručně odkomentujte a upravte jejich jména v definici "VUT title page" v souboru thesis.sty.
\opponent[doc.\ Mgr.]{Křestní}{Příjmení}[Ph.D.]

%%% Název práce
%  Parametr ve složených závorkách {} je název v originálním jazyce,
%  parametr v hranatých závorkách [] je překlad (podle toho jaký je originální jazyk).
%  V případě, že název Vaší práce je dlouhý a nevleze se celý do zápatí prezentace, použijte příkaz
%  \def\insertshorttitle{Zkác.\ náz.\ práce}
%  kde jako parametr vyplníte zkrácený název. Pokud nechcete zkracovat název, budete muset předefinovat,
%  jak se vytváří patička slidu. Viz odkaz: https://bit.ly/3EJTp5A
\title[Title of Student's Thesis]{Automatické herní stanoviště}

%%% Označení oboru studia
%  Parametr ve složených závorkách {} je název oboru v originálním jazyce,
%  parametr v hranatých závorkách [] je překlad
\specialization[Microelectronics and Technology]{Mikroelektronika a technologie}

%%% Označení ústavu
%  Parametr ve složených závorkách {} je název ústavu v originálním jazyce,
%  parametr v hranatých závorkách [] je překlad
%\department[Department of Control and Instrumentation]{Ústav automatizace a měřicí techniky}
%\department[Department of Biomedical Engineering]{Ústav biomedicínského inženýrství}
%\department[Department of Electrical Power Engineering]{Ústav elektroenergetiky}
%\department[Department of Electrical and Electronic Technology]{Ústav elektrotechnologie}
%\department[Department of Physics]{Ústav fyziky}
%\department[Department of Foreign Languages]{Ústav jazyků}
%\department[Department of Mathematics]{Ústav matematiky}
\department[Department of Microelectronics]{Ústav mikroelektroniky}
%\department[Department of Radio Electronics]{Ústav radioelektroniky}
%\department[Department of Theoretical and Experimental Electrical Engineering]{Ústav teoretické a experimentální elektrotechniky}
% \department[Department of Telecommunications]{Ústav telekomunikací}
%\department[Department of Power Electrical and Electronic Engineering]{Ústav výkonové elektrotechniky a elektroniky}

%%% Označení fakulty
%  Parametr ve složených závorkách {} je název fakulty v originálním jazyce,
%  parametr v hranatých závorkách [] je překlad
%\faculty[Faculty of Architecture]{Fakulta architektury}
\faculty[Faculty of Electrical Engineering and~Communication]{Fakulta elektrotechniky a~komunikačních technologií}
%\faculty[Faculty of Chemistry]{Fakulta chemická}
%\faculty[Faculty of Information Technology]{Fakulta informačních technologií}
%\faculty[Faculty of Business and Management]{Fakulta podnikatelská}
%\faculty[Faculty of Civil Engineering]{Fakulta stavební}
%\faculty[Faculty of Mechanical Engineering]{Fakulta strojního inženýrství}
%\faculty[Faculty of Fine Arts]{Fakulta výtvarných umění}
%
%Nastavení logotypu (v hranatych zavorkach zkracene logo, ve slozenych plne):
\facultylogo[logo/FEKT_zkratka_barevne_PANTONE_CZ]{logo/UTKO_color_PANTONE_CZ}

%%% Rok odevzdání práce
\graduateyear{2025}
%%% Akademický rok odevzdání práce
\academicyear{2024/25}

%%% Datum obhajoby (uplatní se pouze v prezentaci k obhajobě)
\date{17.\,6.\,2025} 

%%% Místo obhajoby
% Na titulních stránkách bude automaticky vysázeno VELKÝMI písmeny (pokud tyto stránky sází šablona)
\city{Brno}

%%% Abstrakt
\abstract[%
The goal of this thesis is to design and operate an electronic device for use in outdoor games. 
The primary goal, to create an automated game station, was extended to design a simple personal device as well. 
This thesis aims to design and to create a working electronic device with its own cover shell. 
It emphasizes the right choice of system solutions for the application in the outdoor games and the correct design of the electrical circuits. 
The thesis is divided into several parts - the introduction describes the requirements of the games, the design of a simple personal device and the design of a game with the primary goal of designing a core and evaluating game results. 
]{%
Cílem práce je navrhnout a~zprovoznit elektronické zařízení pro využití v outdoorových hrách. 
Primárně jde o~návrh automatického herního stanoviště, ale došlo i~k~návrhu jednoduchého osobního zařízení. 
Tato práce se zabývá návrhem a~následným oživením elektroniky a~navíc návrhem jejího krytu.
Je kladen důraz na výběr vhodných systémů k~aplikaci ve hrách a~z~nich vycházející návrh elektroniky.
Práce je rozdělena do několika skupin, uvod popisující požadavky her, návrh osobního zařízení a~návrh herního stanoviště, který se zabývá primárně návrhem jádra a~následné zhodnotecní výsledků.
}

%%% Klíčová slova
\keywrds[%
microcontroller, ESP32, ESP32-C3-MINI-1, ESP32-S3, ESP32-S3-WROOM, outdoor games, gaming stations, gaming facilities
]{%
mikrokontrolér, ESP32, ESP32-C3-MINI-1, ESP32-S3, ESP32-S3-WROOM, outdoorové hry, herní stanoviště, herní zařízení
% Klíčová slova v~originálním jazyce
}

%%% Poděkování
\acknowledgement{%
  Rád bych poděkoval vedoucímu bakalářské práce panu doc. Ing. Pavlu Šteffanovi, Ph.D.\ za konzultace, trpělivost a návrhy k~práci.
  Dále bych chtěl poděkovat svému švagrovi Ing. Janu Kirchnerovi za užitečné návrhy ke konstrukci krytů zařízení, k technoligii jejich výroby a především za umožnění využití jeho pětihlavé tiskárny.
  Také bych rád poděkoval mé matce Ing. Věře Vavrincové, přítelkyni Bc. Lucii Rebrovej a především kolegovi Mgr. Petru Kubicovi za kontrolu a připomínky k textové stránce práce.
  % Nakonec bych chtěl poděkovat jednomu nespolehlivému programátorovi Bc. Tomáši Rohlinkovi za to, že si zaplatil výroby prototypu a možná dodá kod na prezentaci práce.
  % Zvláštní poděkování patří Bc. Tomáši Rohlinkovi, který ochotně financoval výrobu prototypu AHS a~možná i~dodá kód k~przentaci práce.
}%

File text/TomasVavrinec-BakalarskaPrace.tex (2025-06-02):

% Soubory musí být v kódování, které je nastaveno v příkazu \usepackage[...]{inputenc}

\documentclass[%        Základní nastavení
  12pt,       				% Velikost základního písma je 12 bodů
  a4paper,    				% Formát papíru je A4
	% twoside,      			% Dvoustranný tisk (kapitoly a další důležité části tedy začínají na lichých stranách)
	unicode,						% Záložky a metainformace ve výsledném  PDF budou v kódování unicode
]{report}				    	% Dokument třídy 'zpráva', vhodná pro sazbu závěrečných prací s kapitolami

\usepackage[utf8]		  %	Kódování zdrojových souborů je UTF-8
	{inputenc}					% Balíček pro nastavení kódování zdrojových souborů
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
]{acronym}						
											% Nutné pro použití prostředí 'acronym' balíčku 'thesis'

\usepackage[
	breaklinks=true,		% Hypertextové odkazy mohou obsahovat zalomení řádku
	hypertexnames=false, % Názvy hypertext. odkazů budou tvořeny nezávisle na názvech TeXu
  % colorlinks=false,    % Bez barevných odkazů
  hidelinks            % Bez rámečků kolem odkazů
]{hyperref}						% Balíček 'hyperref' pro sazbu hypertextových odkazů
											% Nutné pro použití příkazu 'pdfsettings' balíčku 'thesis'

\usepackage{pdfpages} % Balíček umožňující vkládat stránky z PDF souborů
                      % Nutné při vkládání titulních listů a zadání přímo
                      % ve formátu PDF z informačního systému

\usepackage{enumitem} % Balíček pro nastavení mezerování v odrážkách
  \setlist{topsep=0pt,partopsep=0pt,noitemsep} % konkrétní nastavení

\usepackage{cmap} 		% Balíček cmap zajišťuje, že PDF vytvořené `pdflatexem' je
											% plně "prohledávatelné" a "kopírovatelné"

%\usepackage{upgreek}	% Balíček pro sazbu stojatých řeckých písmem
											%% např. stojaté pí: \uppi
											%% např. stojaté mí: \upmu (použitelné třeba v mikrometrech)
											%% pozor, grafická nekompatibilita s fonty typu Computer Modern!
                      
%\usepackage{amsmath} %balíček pro sabu náročnější matematiky                 

\usepackage{dirtree}	% sazba adresářové struktury
                      % vhodné pro prezentaci obsahu elektronické přílohy (např. CD)

% tabulky
\usepackage{makecell}

%====== Bibtex =====

\usepackage{csquotes}
\usepackage[style=iso-numeric]{biblatex}
\addbibresource{text/literatura.bib}

\usepackage[formats]{listings}	% Balíček pro sazbu zdrojových textů
\lstset{              % nastavení
%	Definice jazyka použitého ve výpisech
%    language=[LaTeX]{TeX},	% LaTeX
%	language={Matlab},		% Matlab
	language={C},           % jazyk C
    basicstyle=\ttfamily,	% definice základního stylu písma
    tabsize=2,			% definice velikosti tabulátoru
    inputencoding=utf8,         % pro soubory uložené v kódování UTF-8
		columns=fixed,  %fixed nebo flexible,
		fontadjust=true %licovani sloupcu
    extendedchars=true,
    literate=%  definice symbolů s diakritikou
    {á}{{\'a}}1
    {č}{{\v{c}}}1
    {ď}{{\v{d}}}1
    {é}{{\'e}}1
    {ě}{{\v{e}}}1
    {í}{{\'i}}1 
    {ó}{{\'o}}1
    {ř}{{\v{r}}}1
    {š}{{\v{s}}}1
    {ť}{{\v{t}}}1
    {ú}{{\'u}}1
    {ů}{{\r{u}}}1
    {ý}{{\'y}}1
    {ž}{{\v{z}}}1
    {Á}{{\'A}}1
    {Č}{{\v{C}}}1
    {Ď}{{\v{D}}}1
    {É}{{\'E}}1
    {Ě}{{\v{E}}}1
    {Í}{{\'I}}1
    {Ň}{{\v{N}}}1
    {Ó}{{\'O}}1
    {Ř}{{\v{R}}}1
    {Š}{{\v{S}}}1
    {Ť}{{\v{T}}}1
    {Ú}{{\'U}}1
    {Ů}{{\r{U}}}1
    {Ý}{{\'Y}}1
    {Ž}{{\v{Z}}}1
}

%%%%%%%%%%%%%%%%%%%%%%%%%%%%%%%%%%%%%%%%%%%%%%%%%%%%%%%%%%%%%%%%%
%%%%%%      Definice informací o dokumentu             %%%%%%%%%%
%%%%%%%%%%%%%%%%%%%%%%%%%%%%%%%%%%%%%%%%%%%%%%%%%%%%%%%%%%%%%%%%%

\input{nastaveni.tex}  % do tohoto souboru doplňte údaje o sobě, druhu práce, názvu...

%%%%%%%%%%%%%%%%%%%%%%%%%%%%%%%%%%%%%%%%%%%%%%%%%%%%%%%%%%%%%%%%%%%%%%%%

%%%%%%%%%%%%%%%%%%%%%%%%%%%%%%%%%%%%%%%%%%%%%%%%%%%%%%%%%%%%%%%%%%%%%%%%
%%%%%%     Nastavení polí ve Vlastnostech dokumentu PDF      %%%%%%%%%%%
%%%%%%%%%%%%%%%%%%%%%%%%%%%%%%%%%%%%%%%%%%%%%%%%%%%%%%%%%%%%%%%%%%%%%%%%
%% Při načteném balíčku 'hyperref' lze použít příkaz '\pdfsettings':
\pdfsettings
%  Nastavení polí je možné provést také ručně příkazem:
%\hypersetup{
%  pdftitle={Název studentské práce},    	% Pole 'Document Title'
%  pdfauthor={Autor studenstké práce},   	% Pole 'Author'
%  pdfsubject={Typ práce}, 						  	% Pole 'Subject'
%  pdfkeywords={Klíčová slova}           	% Pole 'Keywords'
%}
%%%%%%%%%%%%%%%%%%%%%%%%%%%%%%%%%%%%%%%%%%%%%%%%%%%%%%%%%%%%%%%%%%%%%%%

\pdfmapfile{=vafle.map}

%%%%%%%%%%%%%%%%%%%%%%%%%%%%%%%%%%%%%%%%%%%%%%%%%%%%%%%%%%%%%%%%%%%%%%%
%%%%%%%%%%%       Začátek dokumentu               %%%%%%%%%%%%%%%%%%%%%
%%%%%%%%%%%%%%%%%%%%%%%%%%%%%%%%%%%%%%%%%%%%%%%%%%%%%%%%%%%%%%%%%%%%%%%
\begin{document}
\pagestyle{empty} %vypnutí číslování stránek

%%% Vložení desek -- od září 2021 na žádost fakulty nepoužíváno
%\includepdf[pages=1]%  buďto generovaných informačním systémem
  %{pdf/student-desky}% název souboru nesmí obsahovat mezery!
%%% NEBO vytvoření desek z balíčku
%%\makecover
%%%
%\oddpage % při dvojstranném tisku přidá prázdnou stránku
%% kazdopádně ale:
%\setcounter{page}{1} %resetovaní čítače stránek -- desky do číslování nezahrnujeme

%% Vložení titulního listu
\includepdf[pages=1]%    buďto generovaného informačním systémem
  {pdf/student-titulka}% název souboru nesmí obsahovat mezery!
%% NEBO vytvoření titulní stránky z balíčku
%\maketitle
%%
\oddpage  % při dvojstranném tisku se přidá prázdná stránka
   
%% Vložení zadání
\includepdf[pages=1]%   buďto generovaného informačním systémem
  {pdf/student-zadani}% název souboru nesmí obsahovat mezery!
%% NEBO lze vytvořit prázdný list příkazem ze šablony
%\patternpage{}%
%	{\sffamily\Huge\centering ZDE VLOŽIT LIST ZADÁNÍ}%
%	{\sffamily\centering Z~důvodu správného číslování stránek}
%%
\oddpage  % při dvojstranném tisku se přidá prázdná stránka

%% Vysázení stránky s abstraktem
\makeabstract

%%% Vysázení citace práce
\makecitation

%%% Vysázení prohlášení o samostatnosti
\makedeclaration

%%% Vysázení poděkování
\makeacknowledgement

%%% Vysázení obsahu
\tableofcontents

%%% Vysázení seznamu obrázků
% (vynechejte, pokud máte dva nebo méně obrázků)
\listoffigures

% %%% Vysázení seznamu tabulek
% % (vynechejte, pokud máte dvě nebo méně tabulek)
% \listoftables

% %%% Vysázení seznamu výpisů kódu
% % (vynechejte, pokud máte dva nebo méně výpisů)
% \lstlistoflistings

\cleardoublepage\pagestyle{plain}   % zapnutí číslování stránek

%Pro vkládání kapitol i příloh používejte raději \include než \input
%%% Vložení souboru 'text/uvod.tex' s úvodem

\chapter*{Úvod}
\input{text/uvod}

\chapter{Důvody elektronizace zážitkových her}
\input{text/TeoretickyUvod/AplikaceHernichZarizeni/AHZUvod.tex}

\chapter{Požadavky na zařízení}
\input{text/TeoretickyUvod/AplikaceHernichZarizeni/Pozadavky.tex}

\section{Moduly}
\input{text/TeoretickyUvod/AplikaceHernichZarizeni/Moduly.tex}

\chapter{Návrh statického zařízení}
\input{text/PraktickaCast/navrhStatiky.tex}

\chapter{Návrh dynamického zařízení}
\input{text/PraktickaCast/navrhDynamiky.tex}

\chapter{Testování statického zařízení}
\input{text/PraktickaCast/testovaniStatiky.tex}

\chapter{Testování dynamického zařízení}
\input{text/PraktickaCast/testovaniDynamiky.tex}

%%% Vložení souboru 'text/zaver' se závěrem
\include{text/zaver}

%%% Vložení souboru 'text/literatura' se seznamem zdrojů
% \section{Použité zdroje}
% \begin{refsection}
%     \nocite{*}
%     \printbibliography[type=online,title={Online články a dokumenty}]
%     \printbibliography[type=manual,title={Katalogové listy důležitých součástek}]
% \end{refsection}
\clearpage
\section{Použité zdroje}
\nocite{*}
\printbibliography[type=online,title={Online články a dokumenty}, heading=subbibliography]
\printbibliography[type=manual,title={Katalogové listy důležitých součástek}, heading=subbibliography]

%%% Vložení souboru 'text/zkratky' se seznam použitých symbolů, veličin a zkratek
\include{text/zkratky}

%% Začátek příloh
\appendix

% Vysázení seznamu příloh
\listofappendices

%% Vložení souboru 'text/prilohy' s přílohami
% Obvykle je přítomen alespoň popis co najdeme na přiloženém médiu
% \chapter{Přílohy}
\include{text/prilohy}

\end{document}

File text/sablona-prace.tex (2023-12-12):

% Soubory musí být v kódování, které je nastaveno v příkazu \usepackage[...]{inputenc}

\documentclass[%        Základní nastavení
%  draft,    				  % Testovací překlad
  12pt,       				% Velikost základního písma je 12 bodů
  a4paper,    				% Formát papíru je A4
  %oneside,      			% Jednostranný tisk
	twoside,      			% Dvoustranný tisk (kapitoly a další důležité části tedy začínají na lichých stranách)
	unicode,						% Záložky a metainformace ve výsledném  PDF budou v kódování unicode
]{report}				    	% Dokument třídy 'zpráva', vhodná pro sazbu závěrečných prací s kapitolami

\usepackage[utf8]		  %	Kódování zdrojových souborů je UTF-8
	{inputenc}					% Balíček pro nastavení kódování zdrojových souborů
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
]{acronym}						
											% Nutné pro použití prostředí 'acronym' balíčku 'thesis'

\usepackage[
	breaklinks=true,		% Hypertextové odkazy mohou obsahovat zalomení řádku
	hypertexnames=false, % Názvy hypertext. odkazů budou tvořeny nezávisle na názvech TeXu
  % colorlinks=false,    % Bez barevných odkazů
  hidelinks            % Bez rámečků kolem odkazů
]{hyperref}						% Balíček 'hyperref' pro sazbu hypertextových odkazů
											% Nutné pro použití příkazu 'pdfsettings' balíčku 'thesis'

\usepackage{pdfpages} % Balíček umožňující vkládat stránky z PDF souborů
                      % Nutné při vkládání titulních listů a zadání přímo
                      % ve formátu PDF z informačního systému

\usepackage{enumitem} % Balíček pro nastavení mezerování v odrážkách
  \setlist{topsep=0pt,partopsep=0pt,noitemsep} % konkrétní nastavení

\usepackage{cmap} 		% Balíček cmap zajišťuje, že PDF vytvořené `pdflatexem' je
											% plně "prohledávatelné" a "kopírovatelné"

%\usepackage{upgreek}	% Balíček pro sazbu stojatých řeckých písmem
											%% např. stojaté pí: \uppi
											%% např. stojaté mí: \upmu (použitelné třeba v mikrometrech)
											%% pozor, grafická nekompatibilita s fonty typu Computer Modern!
                      
%\usepackage{amsmath} %balíček pro sabu náročnější matematiky                 

\usepackage{dirtree}	% sazba adresářové struktury
                      % vhodné pro prezentaci obsahu elektronické přílohy (např. CD)

%====== Bibtex =====

\usepackage{csquotes}
\usepackage[style=iso-numeric]{biblatex}
\addbibresource{text/literatura.bib}

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

%%%%%%%%%%%%%%%%%%%%%%%%%%%%%%%%%%%%%%%%%%%%%%%%%%%%%%%%%%%%%%%%%
%%%%%%      Definice informací o dokumentu             %%%%%%%%%%
%%%%%%%%%%%%%%%%%%%%%%%%%%%%%%%%%%%%%%%%%%%%%%%%%%%%%%%%%%%%%%%%%

\input{nastaveni}  % do tohoto souboru doplňte údaje o sobě, druhu práce, názvu...

%%%%%%%%%%%%%%%%%%%%%%%%%%%%%%%%%%%%%%%%%%%%%%%%%%%%%%%%%%%%%%%%%%%%%%%%

%%%%%%%%%%%%%%%%%%%%%%%%%%%%%%%%%%%%%%%%%%%%%%%%%%%%%%%%%%%%%%%%%%%%%%%%
%%%%%%     Nastavení polí ve Vlastnostech dokumentu PDF      %%%%%%%%%%%
%%%%%%%%%%%%%%%%%%%%%%%%%%%%%%%%%%%%%%%%%%%%%%%%%%%%%%%%%%%%%%%%%%%%%%%%
%% Při načteném balíčku 'hyperref' lze použít příkaz '\pdfsettings':
\pdfsettings
%  Nastavení polí je možné provést také ručně příkazem:
%\hypersetup{
%  pdftitle={Název studentské práce},    	% Pole 'Document Title'
%  pdfauthor={Autor studenstké práce},   	% Pole 'Author'
%  pdfsubject={Typ práce}, 						  	% Pole 'Subject'
%  pdfkeywords={Klíčová slova}           	% Pole 'Keywords'
%}
%%%%%%%%%%%%%%%%%%%%%%%%%%%%%%%%%%%%%%%%%%%%%%%%%%%%%%%%%%%%%%%%%%%%%%%

\pdfmapfile{=vafle.map}

%%%%%%%%%%%%%%%%%%%%%%%%%%%%%%%%%%%%%%%%%%%%%%%%%%%%%%%%%%%%%%%%%%%%%%%
%%%%%%%%%%%       Začátek dokumentu               %%%%%%%%%%%%%%%%%%%%%
%%%%%%%%%%%%%%%%%%%%%%%%%%%%%%%%%%%%%%%%%%%%%%%%%%%%%%%%%%%%%%%%%%%%%%%
\begin{document}
\pagestyle{empty} %vypnutí číslování stránek

%%% Vložení desek -- od září 2021 na žádost fakulty nepoužíváno
%\includepdf[pages=1]%  buďto generovaných informačním systémem
  %{pdf/student-desky}% název souboru nesmí obsahovat mezery!
%%% NEBO vytvoření desek z balíčku
%%\makecover
%%%
%\oddpage % při dvojstranném tisku přidá prázdnou stránku
%% kazdopádně ale:
%\setcounter{page}{1} %resetovaní čítače stránek -- desky do číslování nezahrnujeme

%% Vložení titulního listu
\includepdf[pages=1]%    buďto generovaného informačním systémem
  {pdf/student-titulka}% název souboru nesmí obsahovat mezery!
%% NEBO vytvoření titulní stránky z balíčku
%\maketitle
%%
\oddpage  % při dvojstranném tisku se přidá prázdná stránka
   
%% Vložení zadání
\includepdf[pages=1]%   buďto generovaného informačním systémem
  {pdf/student-zadani}% název souboru nesmí obsahovat mezery!
%% NEBO lze vytvořit prázdný list příkazem ze šablony
%\patternpage{}%
%	{\sffamily\Huge\centering ZDE VLOŽIT LIST ZADÁNÍ}%
%	{\sffamily\centering Z~důvodu správného číslování stránek}
%%
\oddpage  % při dvojstranném tisku se přidá prázdná stránka

%% Vysázení stránky s abstraktem
\makeabstract

%%% Vysázení citace práce
\makecitation

%%% Vysázení prohlášení o samostatnosti
\makedeclaration

%%% Vysázení poděkování
\makeacknowledgement

%%% Vysázení obsahu
\tableofcontents

%%% Vysázení seznamu obrázků
% (vynechejte, pokud máte dva nebo méně obrázků)
\listoffigures

% %%% Vysázení seznamu tabulek
% % (vynechejte, pokud máte dvě nebo méně tabulek)
% \listoftables

% %%% Vysázení seznamu výpisů kódu
% % (vynechejte, pokud máte dva nebo méně výpisů)
% \lstlistoflistings

\cleardoublepage\pagestyle{plain}   % zapnutí číslování stránek

%Pro vkládání kapitol i příloh používejte raději \include než \input
%%% Vložení souboru 'text/uvod.tex' s úvodem

\chapter*{Úvod}
\input{text/uvod}

% %%% Vložení souboru 'text/cile.tex' s úvodem
% \include{text/cile}

%%% Vložení souboru 'text/reseni' s popisem řešení práce
% (rozdělte na více souborů či kapitol, pokud je vhodné)
\chapter{Důvody elektronizace zážitkových her}
% \chapter{Motivace pro elektronizaci zážitkové pedagogiky}
\input{text/TeoretickyUvod/AplikaceHernichZarizeni/AHZUvod.tex}
\section{Požadavky na zařízení}
\input{text/TeoretickyUvod/AplikaceHernichZarizeni/Pozadavky.tex}
% \section{Základní řídící jednotka}
% \input{text/TeoretickyUvod/AplikaceHernichZarizeni/zakladAHS.tex}
\section{Moduly}
\input{text/TeoretickyUvod/AplikaceHernichZarizeni/Moduly.tex}
% \section{Dynamických zařízení}
% \input{text/TeoretickyUvod/AplikaceHernichZarizeni/Semi.tex}

%%% Vložení souboru 'text/vysledky' s popisem vysledků práce
% (rozdělte na více souborů či kapitol, pokud je vhodné)
\chapter{Návrh dynamického zařízení}
\input{text/PraktickaCast/navrhDynamiky.tex}
\chapter{Návrh statického zařízení}
\input{text/PraktickaCast/navrhStatiky.tex}

%%% Vložení souboru 'text/zaver' se závěrem
\include{text/zaver}

%%% Vložení souboru 'text/literatura' se seznamem zdrojů
% \section{Použité zdroje}
% \begin{refsection}
%     \nocite{*}
%     \printbibliography[type=online,title={Online články a dokumenty}]
%     \printbibliography[type=manual,title={Katalogové listy důležitých součástek}]
% \end{refsection}
\clearpage
\section{Použité zdroje}
\nocite{*}
\printbibliography[type=online,title={Online články a dokumenty}, heading=subbibliography]
\printbibliography[type=manual,title={Katalogové listy důležitých součástek}, heading=subbibliography]

%%% Vložení souboru 'text/zkratky' se seznam použitých symbolů, veličin a zkratek
\include{text/zkratky}

%%% Začátek příloh
\appendix

%%% Vysázení seznamu příloh
% (vynechejte, pokud máte dvě nebo méně příloh)
\listofappendices

%%% Vložení souboru 'text/prilohy' s přílohami
% Obvykle je přítomen alespoň popis co najdeme na přiloženém médiu
\include{text/prilohy}

\end{document}

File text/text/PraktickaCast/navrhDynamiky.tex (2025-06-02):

% Uživatelským požadavkem je~dynamické zařízení sloužící například jako identifikátor hráče, nebo jako herní nástroj.
% Mělo by~ale být schopno zastat i~roli statického zařízení, pro případy her na~delších výletech, kde by~bylo nepraktické nosit s~sebou velké zařízení.
% Vyžaduje tedy dostatečnou mobilitu, aby uživateli nepřekáželo v~pohybu.
% Zároveň by~zařízení mělo být co~nejlevnější pro možnost nasazení ve~velkém počtu.
% Z~toho plynou požadavky na~výslednou konstrukci a~velikost zařízení.

% Zařízení by~mělo být schopno komunikovat s~ostatními zařízeními, ať~už statickými nebo dynamickými.
% Potřebuje také světelný výstup pro zobrazování herních stavů a~jednoduchý vstup pro ovládání.

% %~realizace

Z praktických důvodů jsem tomuto zařízení dal jméno Semisemafor.
Idea zařízení totiž částečně vychází z~projektu Semafor \cite{StarySemafor}, který často sloužil podobně jako dopravní semafor, podle kterého dostal své jméno.

Vstup Semisemaforu bude realizován pomocí dvou tlačítek a~šestiosého IMU, pro možnost používání gest.
Světelný výstup bude realizován pomocí dvanácti RGB LED uspořádaných do~kruhu.
Číslo dvanáct bylo zvoleno proto, aby korespondovalo s~hodinami, typicky pro hry, kde probíhá nějaký odpočet.

Aby nebylo nutné starat se~o~baterii, je napájení zajištěno pomocí USB-A konektoru a~malé powerbanky, která se~tak dá~třeba i~snadno vyměnit za~nabitou.

\section{Výběr součástek}
Protože zařízení bude vyráběno u~firmy JLCPCB, je~výhodné využívat součástky, které mají ve~své nabídce.
Dá se~sice zařídit, aby firma osadila i~součástky od~externího dodavatele, ale je~to o~něco složitější a~je tak jednodušší se~tomu vyhnout.

Aby nebylo nutné pro práci se~Semisemaforem a~AHS používat různá prostředí, je~výhodné použít stejný mikrokontrolér nebo alespoň mikrokontrolér ze~stejné rodiny.
Proto byl zvolen mikrokontrolér ESP32-C3-MINI-1, který je~ve srovnání s~ESP32-S3 výrazně levnější a~aplikaci plně dostačuje. 
ESP32-S3 má~stejně jako ESP32-S3 USB periferii, která se~dá využít na~programování kontroleru.
I~tady je~ale problém, že~se tato metoda dá~softwarově narušit a~Semisemafor je~proto vybaven stejným programovacím konektorem jako ESP32-S3 na~AHS.

Protože mám dobré zkušenosti s~LED WS2812B, zvolil jsem na~LED kruh jejich typickou pětimilimetrovou variantu.

IMU na semaforu nemá sloužit pro žádná přesná měření, ale např. pro detekci jednoduchých gest nikoliv pro přesné měření zrychlení, nezáleží proto tolik na~jeho přesnosti.
Při jeho výběru šlo proto primárně o~cenu a~zvoleno bylo LIS2DH12TR \cite{LIS2DH12TR}, které komunikuje po~SPI nebo I2C, ze~kterých jsem zvolil SPI.

Mikrokontrolér ESP32-C3 i~LIS2DH12TR mají rozsah napájecího napětí do~\(3,6~V\) \cite{ESP32C3}\cite{LIS2DH12TR}.
Není proto možné je~napájet přímo z~napětí na~USB, na~kterém je~k~disposici napětí \(5~V\) a~bude tedy potřeba měnič.
ESP32-C3 požaduje zdroj se~schopností dodat \(0,5~A\) \footnote{specifikováno v katalogovém listu \cite{ESP32C3} na straně 20, v~tabulce 10} a~jeho typická spotřeba ze~zkušenosti nepřesáhne \(200~mA\), LIS2DH12TR pak vyžaduje zanedbatelných \(185~\mu A\) (v~závislosti na~vzorkovací frekvenci i~výrazně méně, viz \cite{LIS2DH12TR} strana 17,~tabulka 12).
Považuji proto za~vhodné pro jeho napájení použít LDO.
Z~nabídky JLCPCB jsem proto zvolil LD39200 \cite{LD39200} pro jeho elektrické parametry a~malé pouzdro.

\section{Návrh schématu a~DPS}

Doplnil jsem blokovací kondenzátory dle doporučení výrobců, zpětnovazební dělič k~LDO a~k~tlačítkům jsem připojil kondenzátor proti odskokům.
Také jsem doplnil rezistory připojující pin mikrokontroleru, využívané při startu procesoru, k~napájení resp. k~zemi, podle jejich účelu. 
Dostal jsem tak schéma, umístěné v příloze \ref{Semisemafor-sch-v1}.

\section{Prototypy}
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

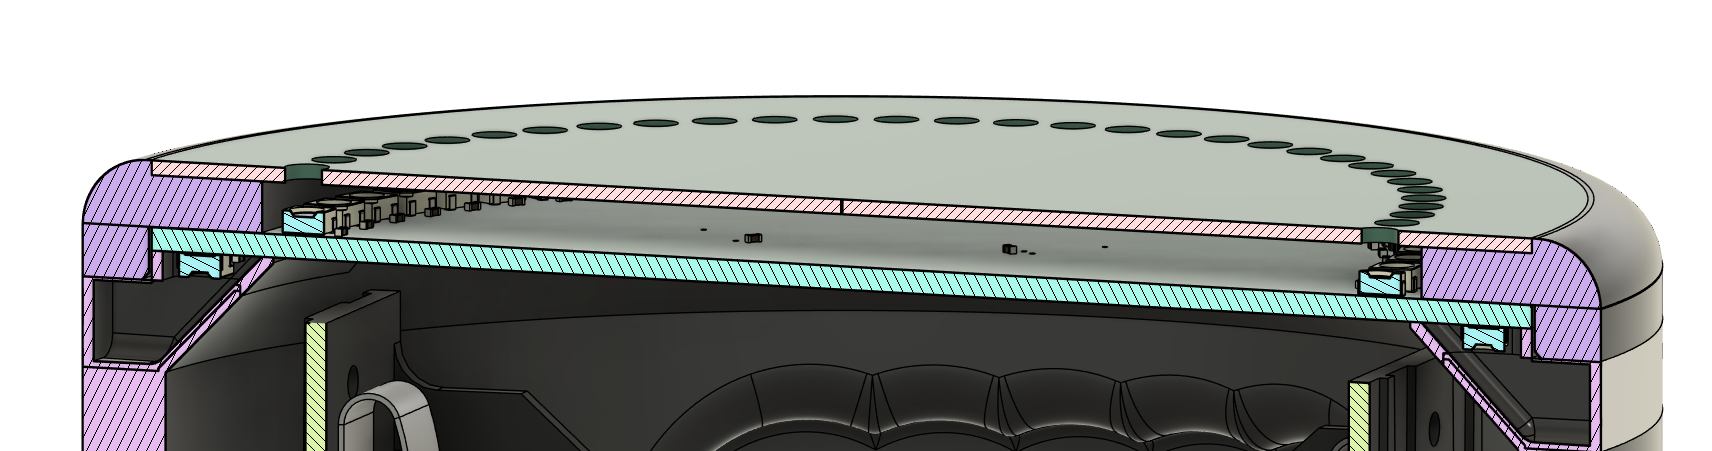
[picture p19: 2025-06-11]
text/text/PraktickaCast/img/rez_tlakovkou.png

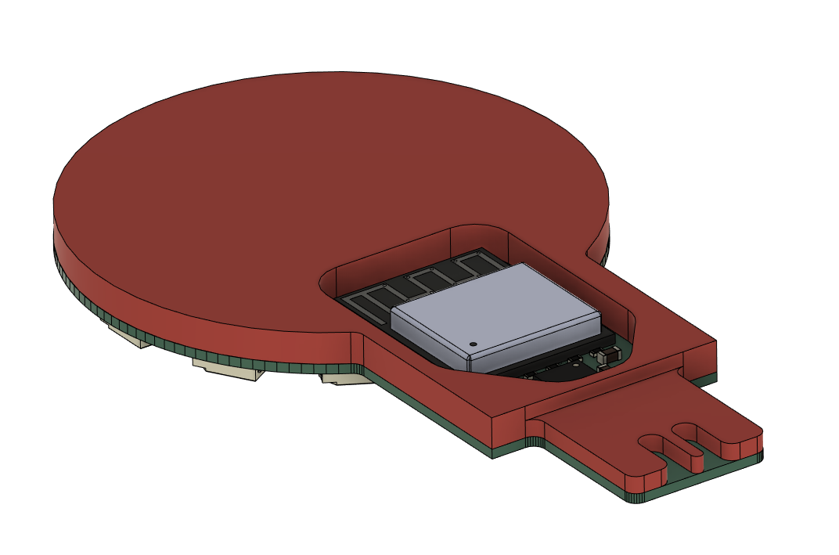
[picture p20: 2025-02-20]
text/text/PraktickaCast/img/SemiSemafor-vlozka.png

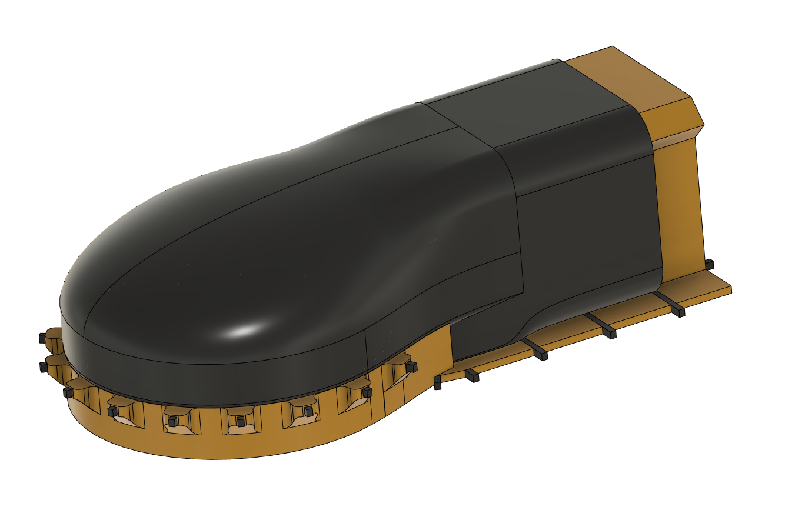
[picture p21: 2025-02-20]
text/text/PraktickaCast/img/SemiSemafor-BOX-pritlak.png

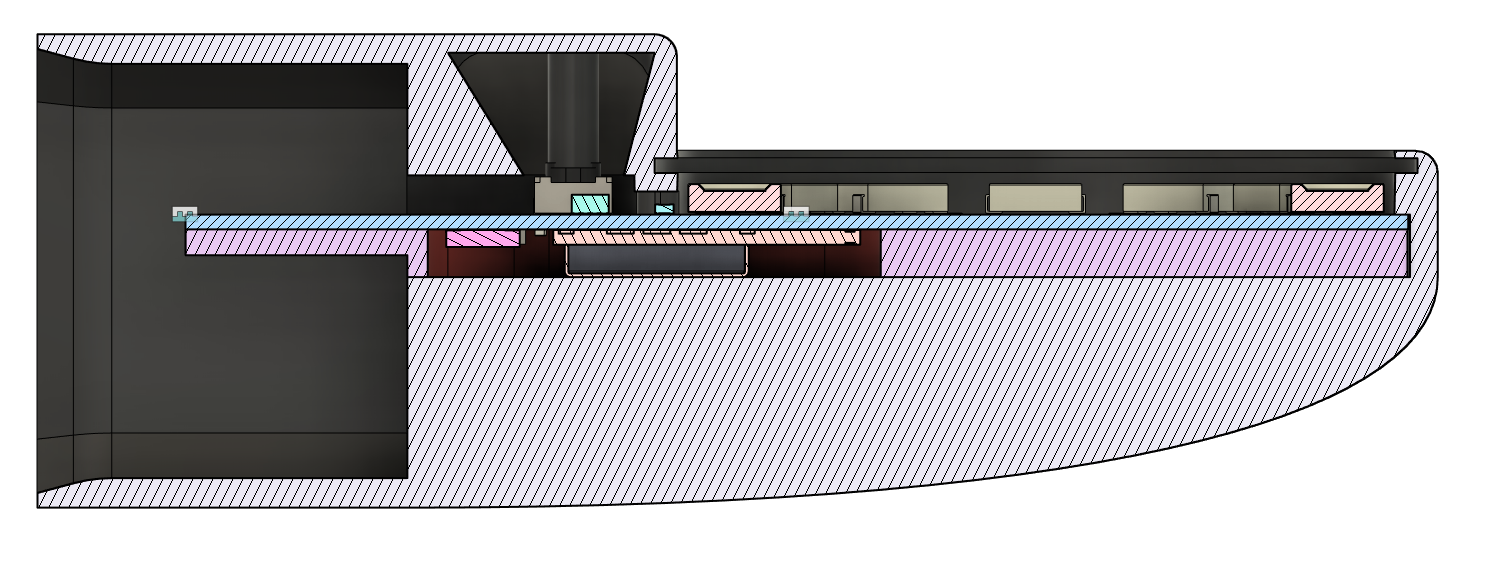
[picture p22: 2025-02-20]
text/text/PraktickaCast/img/SemiSemafor-BOX-rez.png

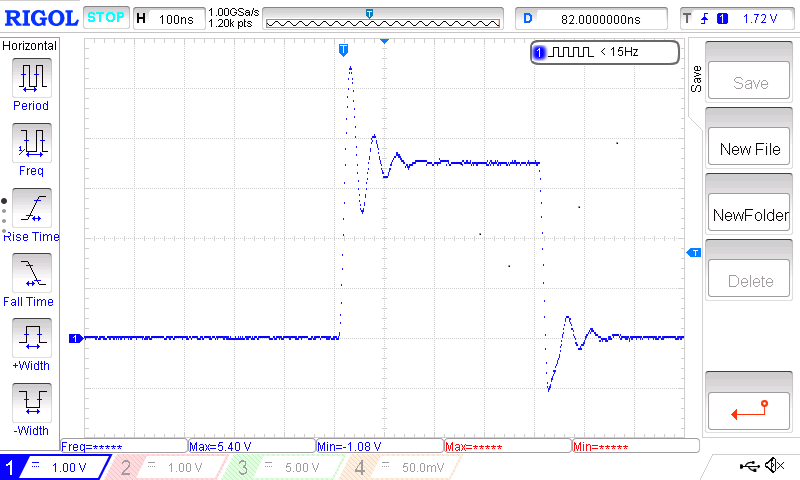
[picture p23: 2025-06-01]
text/text/PraktickaCast/img/osci/fejk.png

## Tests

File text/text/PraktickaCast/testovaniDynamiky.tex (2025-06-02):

\section{Spotřeba}
Podstatným parametrem zařízení je~jeho spotřeba a~tedy doba, po~kterou je možné zařízení provozovat z~powerbanky.

V~rámci prostého měření vstupního proudu při využívání všech periferií vyjma WiFi a Bluetooth, jsem při napětí \(5~V\) změřil vstupní proud v~rozsahu \(35~mA\) až~\(195~mA\) v~závislosti na~aktuálním využití LED kruhu.
Provozní příkon je~tedy v~rozsahu \(35 [mA] \cdot 5~[V] = 175 [mW]\) až~\(195 [mA] \cdot 5~[V] = 975 [mW]\).
Jako zdroj budeme používat powerbanku s~kapacitou \(2200 [mAh] /~3,7 [V]\) neboli \(8,14~Wh\).
Efektivitu převodu napětí u~konkrétní powerbanky bohužel neznám, využil jsem tedy výsledku měření \(73\) různých powerbanek na~stránce GeekBoy \cite{TestPowerbank} a~dále předpokládám efektivitu v~hodnotě mediánu tohoto měření, tedy \(86\%\).
Dobu provozu zařízení tedy můžeme určit jako: 

\vspace{2mm}
\large
\(
 ~t_{min} = \frac{C \eta}{P_{in-max}} = \frac{8.14 \cdot 0.86}{0.975} = 7 [h]
\)

\(
 ~t_{max} = \frac{C \eta}{P_{in-min}} = \frac{8.14 \cdot 0.86}{0.175} = 40 [h]
\)
\normalsize
\vspace{2mm}

Během využívání WiFi stoupne vstupní proud při vypnutém LED kruhu na~\(90~mA\), což odpovídá výdrži \(15.6~h\).
Naopak při současném využívání LED kruhu (střídání plného jasu jednotlivých barevných kanálů) stoupla průměrná spotřeba na~\(278~mA\), což odpovídá \(5~h\) provozu.

K~měření jsem použil osciloskop Rigol DS1045 a~proudovou sondu I-prober 520, kterou jsem připojil na~kabel z~laboratorního zdroje, který jsem použil místo powerbanky, abych mohl připojit proudovou sondu.
Uvedené hodnoty jsou pak střední hodnotou z~\(2,4~s\) dlouhého měření.

Další test výdrže jsem provedl prostým spuštěním hry s~maximálním jasem.
Výsledek, čtyři hodiny padesát minut.
Výsledek tedy téměř přesně sedí na odhad založený na prostém měření proudu.
Navíc je~podstatné zmínit, že~při reálných hrách je~zařízení málokdy spuštěno na~plný jas, a~výdrž se~tak může výrazně zvětšit.

Při následném testu s~desetiprocentním jasem, který je~pro noční hru víc než dostatečný, jsem naměřil výdrž \(11,5\) hodiny.

\newpage
\section{Dosah WiFi}
V~rámci testování dosahu WiFi jsem napsal kód zobrazující sílu přijímaného signálu na~LED kruhu Semisemaforu, abych sebou během testování nepotřeboval další vybavení.
ESP32-C3 umí sílu signálu změřit v~rozsahu \(10~dBm\) do~\(-100~dBm\).
Protože mě~ale zajímal především maximální dosah, zobrazoval jsem jen rozsah mezi \(-88~dBm\) a~\(-100~dBm\), jedna LED na~jeden \(dBm\).
Případné odpojení klienta od~serveru jsem pak signalizoval červeným blikáním, abych jasně viděl ztrátu spojení.

Samotný test jsem prováděl v~Zamilovaném hájku v~Brně v Řečkovicích, kde jsem předpokládal dostatek prostoru, abych narazil na~limit spojení na~přímou viditelnost.
K~mému překvapení se~tak nestalo a~i~na~vzdálenost \(393~m\) měl pořád přijatý signál výkon kolem \(-95~dBm\).
Poloha měření je~vidět na~obrázku \ref{Semisemafor-dosah-zamilec}

\begin{figure}[!h]
  \centering
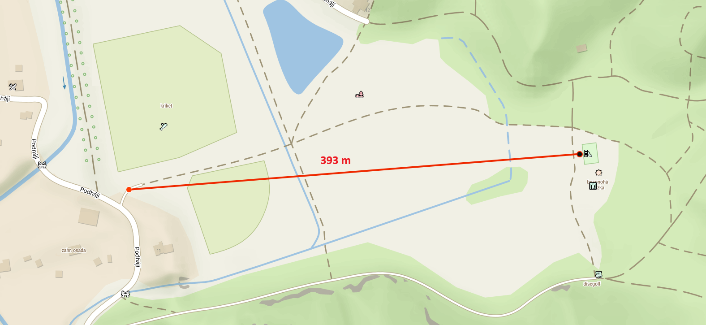
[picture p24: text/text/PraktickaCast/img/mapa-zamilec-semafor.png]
  
  \caption{Mapa zobrazující polohu komunikujících zařízení \cite{MereniDosahuSemaforu-zamilec}}
  \label{Semisemafor-dosah-zamilec}
\end{figure}

Při testování v~lese se~dosah výrazně zkrátí, především pokud v~cestě signálu stojí např. hustý keř.
Přesto jsem ale většinou neměl problém navázat spojení na~vzdálenosti do~padesáti metrů.

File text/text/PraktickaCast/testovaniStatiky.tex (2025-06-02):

\section{Tlaková plocha \label{popisTlakovky3}}
V~rámci testování tlakové plochy jsem testoval primárně schopnost určit polohu stisku a~také citlivost na~působící sílu.
Rozpoznávání polohy stisku je~primárně programový problém a~poměrně rychle jsem jej tak posunul na~kolegu, který se~zabýval právě programem výsledného zařízení.
Kolega Tomáš Rohlínek poměrně rychle dodal program, který je sto vyhodnotit polohu stisku tlakové plochy a~zobrazit ji~na axiálním světelném kruhu.
Člověk tak může určovat, která LED z~kruhu svítí a~silou stisku jí~regulovat barvu.

Sám jsem pak testoval citlivost plochy na~působící sílu, konkrétně její schopnost fungovat jako váha.
Nejmenší zkoušený objekt, který jsem byl sto tlakovou plochou rozeznat, byl SMD rezistor v~pouzdře 0603, vážící pravděpodobně jednotky miligramů (mikrováhou měřící od~\(0.01~g\) jsem jej nerozeznal).
Při testování citlivosti jsem však průměroval výstup plochy z~posledních deseti sekund a~pro praktické užití tak tato přesnost není, navíc jde už~o~tak malé rozlišení, že~zde hraje roli řada okolních podmínek.
Podstatné je~také zmínit, že~terčík byl tvořen \(0.6~mm\) tlustou FR4 DPS a~zároveň plní funkci pružné části systému.
Výsledné chování tudíž nebylo zcela konzistentní v~čase. Při použití plochy jako váhy by~bylo vždy nutné provést kalibraci a~vzít tak v~potaz aktuální deformaci DPS.

Výsledkem tohoto testování je každopádně potvrzení funkčnosti tlakové plochy.
Testování navíc potvrzuje její vysokou citlivost a~schopnost sloužit jako ovládací prvek.

\section{Spotřeba}
Podstatným parametrem zařízení je~jeho spotřeba a~tedy doba, po~kterou může běžet z~baterie.

V~rámci prostého měření proudu baterií jsem měřil spotřebu v~,,menu''~zařízení, tedy při využívání tlakové plochy a~obou světelných kruhů.
Axiální kruh slouží pro nastavení jasu zařízení a~je~rozdělen na~čtvrtiny, které svítí s~různou intenzitou.
Jas radiálního kruhu se pak mění dle aktuálního nastavení.
Měření tedy neprobíhalo za plného jasu všech LED, ale jen při takovém jasu, který odpovídá skutečnému použití.
Spotřebu jsem tak při jejim měření mohl nastavováním jasu regulovat.

Při napětí \(4~V\), tedy při napětí odpovídající cca z~poloviny nabité baterii, jsem při nastaveném maximálním jasu naměřil proud \(780~mA\) a~naopak při minimálním, neboli \(4 \%\) jasu, \(320~mA\). %~TODO: zadefinovat maximální a~minimální jas
Při kapacitě baterie \(4400~mAh\) to~tak odpovídá výdrži \(4400/780 = 5.64~h\) až~\(4400/320 = 13.75~h\).

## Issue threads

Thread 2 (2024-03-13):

Čtení zapínacího tlačítka

TVavrinec, 2024-03-13:
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
R26 musí vést na VCC přímo a ne přez R60, takhle vede na D Q17 a v zapnutém stavu je tak Q19 neustále otenřen => při čtení signálu BUTTON_ON dostaneme vždy 0.

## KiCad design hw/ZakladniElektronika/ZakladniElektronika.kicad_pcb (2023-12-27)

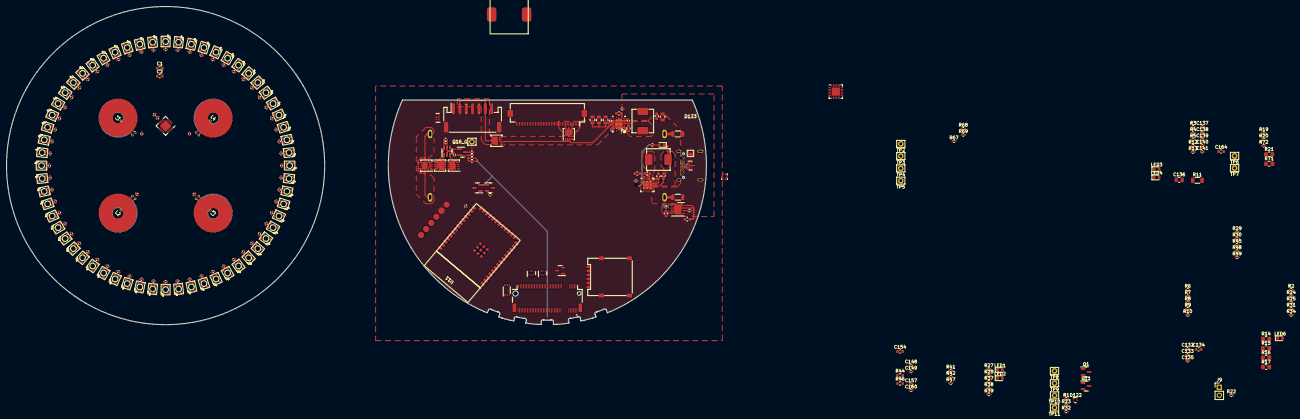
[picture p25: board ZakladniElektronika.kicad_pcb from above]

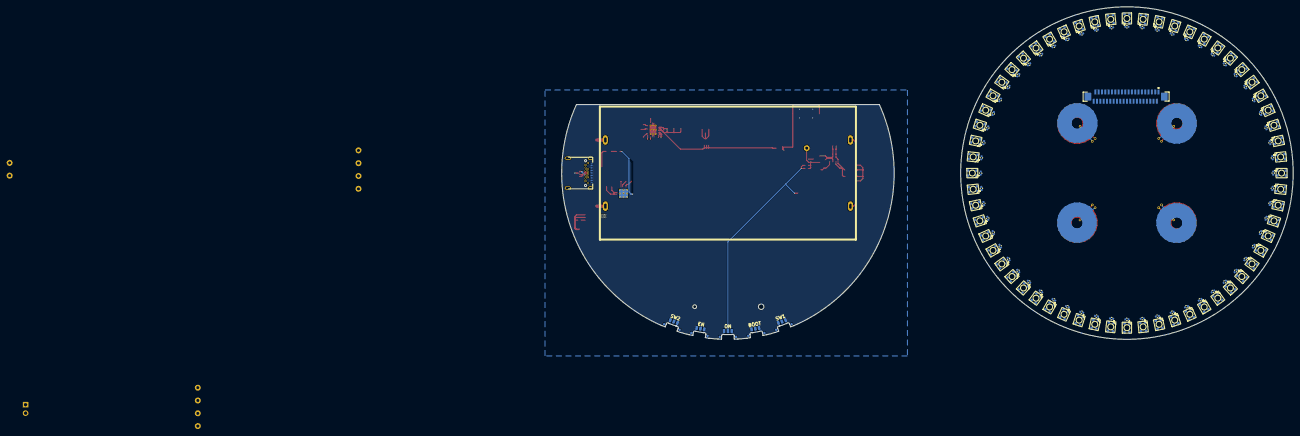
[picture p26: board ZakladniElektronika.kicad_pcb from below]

Board: 4 copper layers, 220.0 x 100.0 mm, 405 parts (128 on the bottom side), 258 nets.

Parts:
BZ1: Buzzer; PKLCS1212E-(RH-Logic_piezzo)
C1, C2, C6, C134, C145, C146, C147, C155: 10u; C_0603_1608Metric
C3, C132, C133, C138, C141, C142, C144, C148, C149, C163, C166: 1u; C_0402_1005Metric
C4, C7, C12, C13, C14, C15, C16, C17, C18, C19, C20, C21, C22, C23, C24, C25, C26, C27, C28, C29, C30, C31, C32, C33, C34, C35, C36, C37, C38, C39, C40, C41, C42, C43, C44, C45, C46, C47, C48, C49, C50, C51, C52, C53, C54, C55, C56, C57, C58, C59, C60, C61, C62, C63, C64, C65, C66, C67, C68, C69, C70, C71, C72, C73, C74, C75, C76, C77, C78, C79, C80, C81, C82, C83, C84, C85, C86, C87, C88, C89, C90, C91, C92, C93, C94, C95, C96, C97, C98, C99, C100, C101, C102, C103, C104, C105, C106, C107, C108, C109, C110, C111, C112, C113, C114, C115, C116, C117, C118, C119, C120, C121, C122, C123, C124, C125, C126, C127, C128, C129, C130, C131, C135, C137, C139, C140, C143, C151: 100n; C_0402_1005Metric
C5, C153, C156, C159: 22u; C_0805_2012Metric
C8, C9, C10, C11: 1000p; C_0402_1005Metric
C136: 10u; C_0805_2012Metric
C150, C154, C164: 4.7u; C_0603_1608Metric
C152, C165: 47n; C_0603_1608Metric
C157: 10n; C_0402_1005Metric
C160: 100p; C_0402_1005Metric
D1, D2, D3, D4, D5, D6, D7, D8, D9, D10, D11, D12, D13, D14, D15, D16, D17, D18, D19, D20, D21, D22, D23, D24, D25, D26, D27, D28, D29, D30, D31, D32, D33, D34, D35, D36, D37, D38, D39, D40, D41, D42, D43, D44, D45, D46, D47, D48, D49, D50, D51, D52, D53, D54, D55, D56, D57, D58, D59, D60, D61, D62, D63, D64, D65, D66, D67, D68, D69, D70, D71, D72, D73, D74, D75, D76, D77, D78, D79, D80, D81, D82, D83, D84, D85, D86, D87, D88, D89, D90, D91, D92, D93, D94, D95, D96, D97, D98, D99, D100, D101, D102, D103, D104, D105, D106, D107, D108, D109, D110, D111, D112, D113, D114, D115, D116, D117, D118, D119, D120: WS2812B; 3528RGBW-WS2812B
D122: D_Dual_CommonCathode_AAK_Parallel; SOT-723
D123: PTVSHC3N24; DFN3-2x2
F3, F4: 3A-6A; L_1206_3216Metric
J2: USB_C_Receptacle_USB2.0; USB31-TYPEC-33141-2FS
J3: Conn_2Rows-75Pins; Conn_M2
J4: Conn_01x07; JST_PH_S7B-PH-SM4-TB_1x07-1MP_P2.00mm_Horizontal
J7: ESP-Programing_conector
J9: Conn_01x02; PinHeader_1x02_P2.54mm_Vertical
J10: Conn_01x40; AFC11-S40ICC-00
J11: Conn_01x40; Hirose_FH12-40S-0.5SH_1x40-1MP_P0.50mm_Horizontal
L1, L2, L3, L4: L; PCB_coil
L6: 1.2u; L_Abracon_ASPI-0630LR
L7: 2.2u; L_Abracon_ASPI-0630LR
LED1, LED3, LED4, LED5, LED6: red; LED_0603_1608Metric
LED2: green; LED_0603_1608Metric
Q1, Q11, Q17: Q_NMOS_DGS-L; SOT-23
Q7: Q_PMOS_DGS-L; SOT-23
Q10, Q13: Q_PMOS_DGS-P; Diodes_PowerDI3333-8
Q12, Q14, Q15: Q_NMOS_DGS-P; Diodes_PowerDI3333-8
Qe: Q_NMOS_DGS-L; SOT-23
R1, R6, R7, R8, R9, R10, R12, R19, R20, R22, R23, R32, R34, R67, R70: 10k; R_0402_1005Metric
R2, R26, R41, R50, R60: 200k; R_0402_1005Metric
R3, R4: 5.1k; R_0402_1005Metric
R5, R13, R18, R24, R25, R31, R37, R38, R39, R45, R48: 4.7k; R_0402_1005Metric
R11: 10m; R_1206_3216Metric
R14, R16: 0-nc; R_0805_2012Metric_Pad1.20x1.40mm_HandSolder
R15, R17, R21, R71: 0; R_0805_2012Metric_Pad1.20x1.40mm_HandSolder
R27, R28: 1k; R_0402_1005Metric
R29, R30, R49, R69: 200; R_0402_1005Metric
R33: 2k; R_0402_1005Metric
R35: 470; R_0402_1005Metric
R36, R68: 1M; R_0402_1005Metric
R42: 3.92k; R_0402_1005Metric
R43, R44: 150k; R_0603_1608Metric
R46: 56k; R_0603_1608Metric
R47: 17.4k; R_0402_1005Metric
R72: 100; R_0402_1005Metric
SW1, SW2: SW_Push; TCF2QR
SW3: ON; TCF2QR
SW4: BOOT; TCF2QR
SW5: EN; TCF2QR
TP1: Q16_G; Pin_D0.9mm_L10.0mm_W2.4mm_FlatFork
TP2: TestPoint-BAT; Pin_D0.9mm_L10.0mm_W2.4mm_FlatFork
TP3: TestPoint-VCC; Pin_D0.9mm_L10.0mm_W2.4mm_FlatFork
TP4: TestPoint-BUTTON_ON; Pin_D0.9mm_L10.0mm_W2.4mm_FlatFork
TP5: TestPoint-EN_ALL; Pin_D0.9mm_L10.0mm_W2.4mm_FlatFork
TP6: TestPoint-Charger_QON; Pin_D0.9mm_L10.0mm_W2.4mm_FlatFork
TP7: TestPoint-Charger_ILIM; Pin_D0.9mm_L10.0mm_W2.4mm_FlatFork
TP8: TestPoint-5V_EN; Pin_D0.9mm_L10.0mm_W2.4mm_FlatFork
TP9: TestPoint-5V; Pin_D0.9mm_L10.0mm_W2.4mm_FlatFork
TP10: TestPoint-5V_B; Pin_D0.9mm_L10.0mm_W2.4mm_FlatFork
TP11: TestPoint-5V_A; Pin_D0.9mm_L10.0mm_W2.4mm_FlatFork
U1: LDC1614; WQFN-16-1EP_4x4mm_P0.5mm_EP2.6x2.6mm
U2, U6: TXB0304RUT; Texas_R-PUQFN-N12
U3: TPS61088RHLR; RHL0020A
U4: AP33772; QFN-24-1EP_4x4mm_P0.5mm_EP2.6x2.6mm
U5, U13: TPD4E02B04DQA; USON-10_2.5x1.0mm_P0.5mm
U7: SL8261D-G3JE; SOT-23-6
U8: PCA9306DC; VSSOP-8_2.3x2mm_P0.5mm
U9: BQ25895RTW; Texas_S-PWQFN-N24_EP2.7x2.7mm_ThermalVias
U11: ESP32-S3-WROOM
U12: LD39200; DFN-8-1EP_4x4mm_P0.8mm_EP2.3x3.24mm
U15: TS3USB3031; Texas_X2QFN-12_1.6x1.6mm_P0.4mm
U17: BateriCell_2x; battery_dock
U52: MCP1700x-180xxTT; SOT-23
U53: SMN-305-ARP7

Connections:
/HlavniDeska/3V3: C134.2, C135.2, C149.1, C155.1, J7.1 (VCC), J9.2, J11.36, LED6.2 (A), R2.1, R9.1, R10.1, R23.1, R34.1, R37.1, R38.1, R39.1, R45.2, R48.2, R67.2, R70.2, U2.11 (VCCB), U6.11 (VCCB), U11.2 (3V3), U12.1 (OUT), U12.2 (OUT), U12.3 (ADJ/SENSE), U15.12 (VCC), U52.3 (VI)
/HlavniDeska/5V-OUT: J11.1, J11.2, J11.3, J11.4, J11.5, J11.6, J11.7, J11.8, J11.9, J11.10, J11.11, J11.12, J11.13, Q13.5 (D), TP10.1
/HlavniDeska/C.D+: J2.A6 (D+), J2.B6 (D+), U13.5 (IO4), U15.11 (D+)
/HlavniDeska/C.D-: J2.A7 (D-), J2.B7 (D-), U13.4 (IO3), U15.10 (D-)
/HlavniDeska/ESP32S3/BOOT: C132.1, J7.4 (BOOT), R9.2, SW4.2, U11.27 (IO00-PU)
/HlavniDeska/ESP32S3/EN: C133.1, J7.3 (EN), R10.2, SW5.2, U11.3 (EN)
/HlavniDeska/ESP32S3/IO01: BZ1.2 (+), U11.39 (IO01)
/HlavniDeska/ESP32S3/IO02: R49.2, U5.4 (IO3), U11.38 (IO02)
/HlavniDeska/ESP32S3/IO03-PD: BZ1.1 (-), R8.1, U11.15 (IO03-PD)
/HlavniDeska/ESP32S3/IO07: U6.10 (B1), U11.7 (IO07)
/HlavniDeska/ESP32S3/IO08: J3.6, U11.12 (IO08)
/HlavniDeska/ESP32S3/IO15: J3.1, U11.8 (IO15)
/HlavniDeska/ESP32S3/IO16: J3.75, U11.9 (IO16)
/HlavniDeska/ESP32S3/IO17: J3.69, U11.10 (IO17)
/HlavniDeska/ESP32S3/IO18: J3.21, U11.11 (IO18)
/HlavniDeska/ESP32S3/IO21: R69.2, U11.23 (IO21)
/HlavniDeska/ESP32S3/IO35: Qe.1 (D), R70.1, U11.28 (IO35)
/HlavniDeska/ESP32S3/IO36: SW1.2, U11.29 (IO36)
/HlavniDeska/ESP32S3/IO37: SW2.2, U11.30 (IO37)
/HlavniDeska/ESP32S3/IO38: LED1.2 (A), U11.31 (IO38)
/HlavniDeska/ESP32S3/IO39: LED2.2 (A), U11.32 (IO39)
/HlavniDeska/ESP32S3/IO41: R29.2, U5.1 (IO1), U11.34 (IO41)
/HlavniDeska/ESP32S3/IO42: R30.2, U5.2 (IO2), U11.35 (IO42)
/HlavniDeska/ESP32S3/IO45-PD: D122.1 (K), Q11.2 (G), R7.1, U11.26 (IO45-PD)
/HlavniDeska/ESP32S3/IO46-PD: D122.2 (K), Q1.2 (G), R6.1, U11.16 (IO46-PD)
/HlavniDeska/ESP32S3/RX_ESP: J7.5 (RX), U11.36 (IO44-RX)
/HlavniDeska/ESP32S3/TX_ESP: J7.6 (TX), U11.37 (IO43-TX)
/HlavniDeska/ESP.D+: U11.14 (IO20-D+), U15.5 (USB2+)
/HlavniDeska/ESP.D-: U11.13 (IO19-D-), U15.6 (USB2-)
/HlavniDeska/GPSKomunikacniModul/1V8: C148.1, R24.1, R25.1, U2.1 (VCCA), U2.12 (OE), U6.1 (VCCA), U6.12 (OE), U8.2 (VREF1), U52.2 (VO)
/HlavniDeska/GPSKomunikacniModul/SCL(1.8V): J3.40, R24.2, U8.3 (SCL1)
/HlavniDeska/GPSKomunikacniModul/SDA(1.8V): J3.42, R25.2, U8.4 (SDA1)
/HlavniDeska/GPSKomunikacniModul/SIM_CD: J3.66, U53.D (CD)
/HlavniDeska/GPSKomunikacniModul/SIM_CLK: J3.32, U53.3 (CLK)
/HlavniDeska/GPSKomunikacniModul/SIM_I/O: J3.34, U53.7 (I/O)
/HlavniDeska/GPSKomunikacniModul/SIM_RST: J3.30, U53.2 (RST)
/HlavniDeska/GPSKomunikacniModul/SIM_VCC: J3.36, U53.1 (VCC)
/HlavniDeska/GPSKomunikacniModul/UART_CTS(O)(1.8V): J3.56, U2.4 (A3)
/HlavniDeska/GPSKomunikacniModul/UART_DTR(I)(1.8V): J3.52, U6.3 (A2)
/HlavniDeska/GPSKomunikacniModul/UART_RTS(I)(1.8V): J3.54, U2.5 (A4)
/HlavniDeska/GPSKomunikacniModul/UART_RXD(I)(1.8V): R14.1, R15.1, U2.3 (A2)
/HlavniDeska/GPSKomunikacniModul/UART_TXD(O)(1.8V): R16.1, R17.1, U2.2 (A1)
/HlavniDeska/INT: J3.23, J11.38, R34.2, R38.2, U4.9 (GPIO3), U9.7 (INT), U11.4 (IO04)
/HlavniDeska/IO40: J11.27, U11.33 (IO40)
/HlavniDeska/KM_CST: U2.8 (B3), U11.19 (IO11)
/HlavniDeska/KM_DTR: U6.9 (B2), U11.17 (IO09)
/HlavniDeska/KM_RTS: U2.7 (B4), U11.18 (IO10)
/HlavniDeska/KM_RXD: U2.9 (B2), U11.20 (IO12)
/HlavniDeska/KM_TXD: U2.10 (B1), U11.21 (IO13)
/HlavniDeska/KomunikacniModul.D+: J3.9, U15.7 (MHL+)
/HlavniDeska/KomunikacniModul.D-: J3.7, U15.8 (MHL-)
/HlavniDeska/ModulovyKonektor/5V: J4.2, J4.6, Q10.5 (D), TP11.1, U5.5 (IO4)
/HlavniDeska/Nabijecka.D+: U9.2 (D+), U15.3 (USB1+)
/HlavniDeska/Nabijecka.D-: U9.3 (D-), U15.4 (USB1-)
/HlavniDeska/SCL: J11.40, R37.2, U4.5 (SCL), U8.6 (SCL2), U9.5 (SCL), U11.5 (IO05)
/HlavniDeska/SDA: J11.39, R39.2, U4.4 (SDA), U8.5 (SDA2), U9.6 (SDA), U11.6 (IO06)
/HlavniDeska/SpravceNapajeni/5V-IN: C142.1, C153.1, C156.1, C159.1, Q10.1 (S), Q10.2 (S), Q10.3 (S), Q13.1 (S), Q13.2 (S), Q13.3 (S), R1.1, R32.1, R46.1, TP9.1, U3.14 (VOUT), U3.15 (VOUT), U3.16 (VOUT)
/HlavniDeska/SpravceNapajeni/DSEL: R23.2, U9.24 (DSEL), U15.1 (SEL0)
/HlavniDeska/SpravceNapajeni/Nabijecka/STAT: R18.1, U9.4 (STAT)
/HlavniDeska/SpravceNapajeni/NapajeciRozcesti/EN-5V: D122.3 (A), R41.2, TP8.1, U3.2 (EN)
/HlavniDeska/SpravceNapajeni/VBUS: C137.2, C141.1, C166.1, R11.2, U4.22 (VUSB), U4.24 (VCC), U9.1 (VBUS)
/HlavniDeska/USB/AP-3V3: C139.2, U4.12 (3V3)
/HlavniDeska/USB/USB_CC1: J2.A5 (CC1), R4.1, U4.17 (CC1), U13.1 (IO1)
/HlavniDeska/USB/USB_CC2: J2.B5 (CC2), R3.1, U4.16 (CC2), U13.2 (IO2)
/HlavniDeska/USB/V_USB: C136.1, C137.1, D123.3 (K), J2.A4 (VBUS), J2.A9 (VBUS), J2.B4 (VBUS), J2.B9 (VBUS), LED3.2 (A), R11.1, U4.1 (ISENP)
/LedDeska/3V3: C3.1, C4.1, J10.36, U1.7 (VDD)
/LedDeska/5V: C1.1, C2.1, C12.1, C13.1, C14.1, C15.1, C16.1, C17.1, C18.1, C19.1, C20.1, C21.1, C22.1, C23.1, C24.1, C25.1, C26.1, C27.1, C28.1, C29.1, C30.1, C31.1, C32.1, C33.1, C34.1, C35.1, C36.1, C37.1, C38.1, C39.1, C40.1, C41.1, C42.1, C43.1, C44.1, C45.1, C46.1, C47.1, C48.1, C49.1, C50.1, C51.1, C52.1, C53.1, C54.1, C55.1, C56.1, C57.1, C58.1, C59.1, C60.1, C61.1, C62.1, C63.1, C64.1, C65.1, C66.1, C67.1, C68.1, C69.1, C70.1, C71.1, C72.1, C73.1, C74.1, C75.1, C76.1, C77.1, C78.1, C79.1, C80.1, C81.1, C82.1, C83.1, C84.1, C85.1, C86.1, C87.1, C88.1, C89.1, C90.1, C91.1, C92.1, C93.1, C94.1, C95.1, C96.1, C97.1, C98.1, C99.1, C100.1, C101.1, C102.1, C103.1, C104.1, C105.1, C106.1, C107.1, C108.1, C109.1, C110.1, C111.1, C112.1, C113.1, C114.1, C115.1, C116.1, C117.1, C118.1, C119.1, C120.1, C121.1, C122.1, C123.1, C124.1, C125.1, C126.1, C127.1, C128.1, C129.1, C130.1, C131.1, D1.1 (VDD), D2.1 (VDD), D3.1 (VDD), D4.1 (VDD), D5.1 (VDD), D6.1 (VDD), D7.1 (VDD), D8.1 (VDD), D9.1 (VDD), D10.1 (VDD), D11.1 (VDD), D12.1 (VDD), D13.1 (VDD), D14.1 (VDD), D15.1 (VDD), D16.1 (VDD), D17.1 (VDD), D18.1 (VDD), D19.1 (VDD), D20.1 (VDD), D21.1 (VDD), D22.1 (VDD), D23.1 (VDD), D24.1 (VDD), D25.1 (VDD), D26.1 (VDD), D27.1 (VDD), D28.1 (VDD), D29.1 (VDD), D30.1 (VDD), D31.1 (VDD), D32.1 (VDD), D33.1 (VDD), D34.1 (VDD), D35.1 (VDD), D36.1 (VDD), D37.1 (VDD), D38.1 (VDD), D39.1 (VDD), D40.1 (VDD), D41.1 (VDD), D42.1 (VDD), D43.1 (VDD), D44.1 (VDD), D45.1 (VDD), D46.1 (VDD), D47.1 (VDD), D48.1 (VDD), D49.1 (VDD), D50.1 (VDD), D51.1 (VDD), D52.1 (VDD), D53.1 (VDD), D54.1 (VDD), D55.1 (VDD), D56.1 (VDD), D57.1 (VDD), D58.1 (VDD), D59.1 (VDD), D60.1 (VDD), D61.1 (VDD), D62.1 (VDD), D63.1 (VDD), D64.1 (VDD), D65.1 (VDD), D66.1 (VDD), D67.1 (VDD), D68.1 (VDD), D69.1 (VDD), D70.1 (VDD), D71.1 (VDD), D72.1 (VDD), D73.1 (VDD), D74.1 (VDD), D75.1 (VDD), D76.1 (VDD), D77.1 (VDD), D78.1 (VDD), D79.1 (VDD), D80.1 (VDD), D81.1 (VDD), D82.1 (VDD), D83.1 (VDD), D84.1 (VDD), D85.1 (VDD), D86.1 (VDD), D87.1 (VDD), D88.1 (VDD), D89.1 (VDD), D90.1 (VDD), D91.1 (VDD), D92.1 (VDD), D93.1 (VDD), D94.1 (VDD), D95.1 (VDD), D96.1 (VDD), D97.1 (VDD), D98.1 (VDD), D99.1 (VDD), D100.1 (VDD), D101.1 (VDD), D102.1 (VDD), D103.1 (VDD), D104.1 (VDD), D105.1 (VDD), D106.1 (VDD), D107.1 (VDD), D108.1 (VDD), D109.1 (VDD), D110.1 (VDD), D111.1 (VDD), D112.1 (VDD), D113.1 (VDD), D114.1 (VDD), D115.1 (VDD), D116.1 (VDD), D117.1 (VDD), D118.1 (VDD), D119.1 (VDD), D120.1 (VDD), J10.1, J10.2, J10.3, J10.4, J10.5, J10.6, J10.7, J10.8, J10.9, J10.10, J10.11, J10.12, J10.13
/LedDeska/AN-GND: C3.2, C4.2, J10.37, U1.3 (CLKIN), U1.4 (ADDR), U1.6 (SD), U1.8 (GND), U1.17 (GND)
/LedDeska/INT-LDC: J10.38, U1.5 (INTB)
/LedDeska/LED-GND: C1.2, C2.2, C12.2, C13.2, C14.2, C15.2, C16.2, C17.2, C18.2, C19.2, C20.2, C21.2, C22.2, C23.2, C24.2, C25.2, C26.2, C27.2, C28.2, C29.2, C30.2, C31.2, C32.2, C33.2, C34.2, C35.2, C36.2, C37.2, C38.2, C39.2, C40.2, C41.2, C42.2, C43.2, C44.2, C45.2, C46.2, C47.2, C48.2, C49.2, C50.2, C51.2, C52.2, C53.2, C54.2, C55.2, C56.2, C57.2, C58.2, C59.2, C60.2, C61.2, C62.2, C63.2, C64.2, C65.2, C66.2, C67.2, C68.2, C69.2, C70.2, C71.2, C72.2, C73.2, C74.2, C75.2, C76.2, C77.2, C78.2, C79.2, C80.2, C81.2, C82.2, C83.2, C84.2, C85.2, C86.2, C87.2, C88.2, C89.2, C90.2, C91.2, C92.2, C93.2, C94.2, C95.2, C96.2, C97.2, C98.2, C99.2, C100.2, C101.2, C102.2, C103.2, C104.2, C105.2, C106.2, C107.2, C108.2, C109.2, C110.2, C111.2, C112.2, C113.2, C114.2, C115.2, C116.2, C117.2, C118.2, C119.2, C120.2, C121.2, C122.2, C123.2, C124.2, C125.2, C126.2, C127.2, C128.2, C129.2, C130.2, C131.2, D1.3 (VSS), D2.3 (VSS), D3.3 (VSS), D4.3 (VSS), D5.3 (VSS), D6.3 (VSS), D7.3 (VSS), D8.3 (VSS), D9.3 (VSS), D10.3 (VSS), D11.3 (VSS), D12.3 (VSS), D13.3 (VSS), D14.3 (VSS), D15.3 (VSS), D16.3 (VSS), D17.3 (VSS), D18.3 (VSS), D19.3 (VSS), D20.3 (VSS), D21.3 (VSS), D22.3 (VSS), D23.3 (VSS), D24.3 (VSS), D25.3 (VSS), D26.3 (VSS), D27.3 (VSS), D28.3 (VSS), D29.3 (VSS), D30.3 (VSS), D31.3 (VSS), D32.3 (VSS), D33.3 (VSS), D34.3 (VSS), D35.3 (VSS), D36.3 (VSS), D37.3 (VSS), D38.3 (VSS), D39.3 (VSS), D40.3 (VSS), D41.3 (VSS), D42.3 (VSS), D43.3 (VSS), D44.3 (VSS), D45.3 (VSS), D46.3 (VSS), D47.3 (VSS), D48.3 (VSS), D49.3 (VSS), D50.3 (VSS), D51.3 (VSS), D52.3 (VSS), D53.3 (VSS), D54.3 (VSS), D55.3 (VSS), D56.3 (VSS), D57.3 (VSS), D58.3 (VSS), D59.3 (VSS), D60.3 (VSS), D61.3 (VSS), D62.3 (VSS), D63.3 (VSS), D64.3 (VSS), D65.3 (VSS), D66.3 (VSS), D67.3 (VSS), D68.3 (VSS), D69.3 (VSS), D70.3 (VSS), D71.3 (VSS), D72.3 (VSS), D73.3 (VSS), D74.3 (VSS), D75.3 (VSS), D76.3 (VSS), D77.3 (VSS), D78.3 (VSS), D79.3 (VSS), D80.3 (VSS), D81.3 (VSS), D82.3 (VSS), D83.3 (VSS), D84.3 (VSS), D85.3 (VSS), D86.3 (VSS), D87.3 (VSS), D88.3 (VSS), D89.3 (VSS), D90.3 (VSS), D91.3 (VSS), D92.3 (VSS), D93.3 (VSS), D94.3 (VSS), D95.3 (VSS), D96.3 (VSS), D97.3 (VSS), D98.3 (VSS), D99.3 (VSS), D100.3 (VSS), D101.3 (VSS), D102.3 (VSS), D103.3 (VSS), D104.3 (VSS), D105.3 (VSS), D106.3 (VSS), D107.3 (VSS), D108.3 (VSS), D109.3 (VSS), D110.3 (VSS), D111.3 (VSS), D112.3 (VSS), D113.3 (VSS), D114.3 (VSS), D115.3 (VSS), D116.3 (VSS), D117.3 (VSS), D118.3 (VSS), D119.3 (VSS), D120.3 (VSS), J10.14, J10.15, J10.16, J10.17, J10.18, J10.19, J10.20, J10.21, J10.22, J10.23, J10.24, J10.25, J10.26
/LedDeska/LedRing-Axial/DOUT: D60.2 (DOUT), D61.4 (DIN)
/LedDeska/SCL: J10.40, U1.1 (SCL)
/LedDeska/SDA: J10.39, U1.2 (SDA)
/LedDeska/WS2812: D1.4 (DIN), J10.27
GND: C5.2, C6.2, C7.2, C132.2, C133.2, C134.1, C135.1, C136.2, C138.2, C139.1, C140.1, C141.2, C142.2, C145.2, C146.2, C147.2, C148.2, C149.2, C150.2, C152.2, C153.2, C154.2, C155.2, C156.2, C157.2, C159.2, C160.2, C163.2, C164.2, C166.2, D123.1 (A), D123.2 (A), J2.A1 (GND), J2.A12 (GND), J2.B1 (GND), J2.B12 (GND), J2.S1 (SHIELD), J3.3, J3.5, J3.11, J3.25, J3.27, J3.33, J3.39, J3.45, J3.51, J3.57, J3.71, J3.73, J4.3, J4.5, J7.2 (GND), J11.14, J11.15, J11.16, J11.17, J11.18, J11.19, J11.20, J11.21, J11.22, J11.23, J11.24, J11.25, J11.26, J11.37, Q1.3 (S), Q11.3 (S), Q14.1 (S), Q14.2 (S), Q14.3 (S), Q17.3 (S), Qe.3 (S), R3.2, R4.2, R5.1, R6.2, R7.2, R8.2, R12.1, R13.1, R19.2, R21.1, R22.2, R27.1, R28.1, R33.1, R41.1, R44.2, R47.1, R68.1, R71.1, R72.2, SW1.1, SW2.1, SW3.1, SW4.1, SW5.1, U2.6 (GND), U3.0 (PGND), U3.20 (AGND), U3.21 (PGND), U4.3 (GND), U4.25 (GND), U5.3 (G), U5.8 (G), U6.6 (GND), U8.1 (GND), U9.17 (PGND), U9.18 (PGND), U9.25 (PGND), U11.1 (GND), U11.40 (GND), U11.41 (GND), U12.4 (GND), U12.9 (GND), U13.3 (G), U13.8 (G), U15.9 (GND), U52.1 (GND), U53.5 (GND)
unnamed: C157.1, R42.2
unnamed: C165.1, L7.1, U9.19 (SW), U9.20 (SW)
unnamed: D1.2 (DOUT), D7.4 (DIN)
unnamed: D2.4 (DIN), D55.2 (DOUT)
unnamed: D2.2 (DOUT), D8.4 (DIN)
unnamed: D3.4 (DIN), D56.2 (DOUT)
unnamed: D3.2 (DOUT), D9.4 (DIN)
unnamed: D4.4 (DIN), D57.2 (DOUT)
unnamed: D5.4 (DIN), D58.2 (DOUT)
unnamed: D4.2 (DOUT), D10.4 (DIN)
unnamed: D10.2 (DOUT), D16.4 (DIN)
unnamed: D5.2 (DOUT), D11.4 (DIN)
unnamed: D11.2 (DOUT), D17.4 (DIN)
unnamed: D6.2 (DOUT), D12.4 (DIN)
unnamed: D12.2 (DOUT), D18.4 (DIN)
unnamed: D7.2 (DOUT), D13.4 (DIN)
unnamed: D13.2 (DOUT), D19.4 (DIN)
unnamed: D8.2 (DOUT), D14.4 (DIN)
unnamed: D14.2 (DOUT), D20.4 (DIN)
unnamed: D9.2 (DOUT), D15.4 (DIN)
unnamed: D15.2 (DOUT), D21.4 (DIN)
unnamed: D16.2 (DOUT), D22.4 (DIN)
unnamed: D17.2 (DOUT), D23.4 (DIN)
unnamed: D18.2 (DOUT), D24.4 (DIN)
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

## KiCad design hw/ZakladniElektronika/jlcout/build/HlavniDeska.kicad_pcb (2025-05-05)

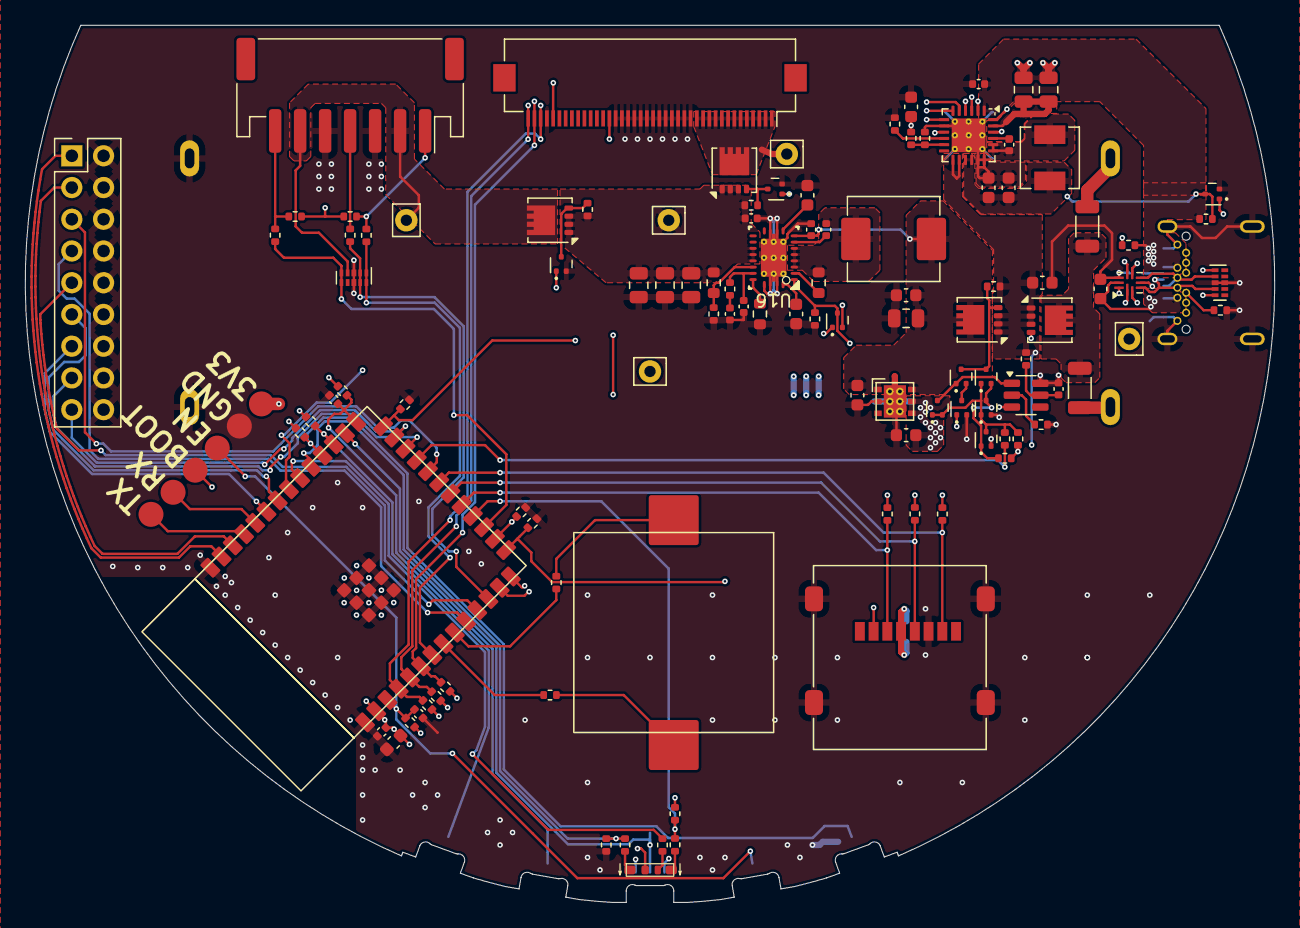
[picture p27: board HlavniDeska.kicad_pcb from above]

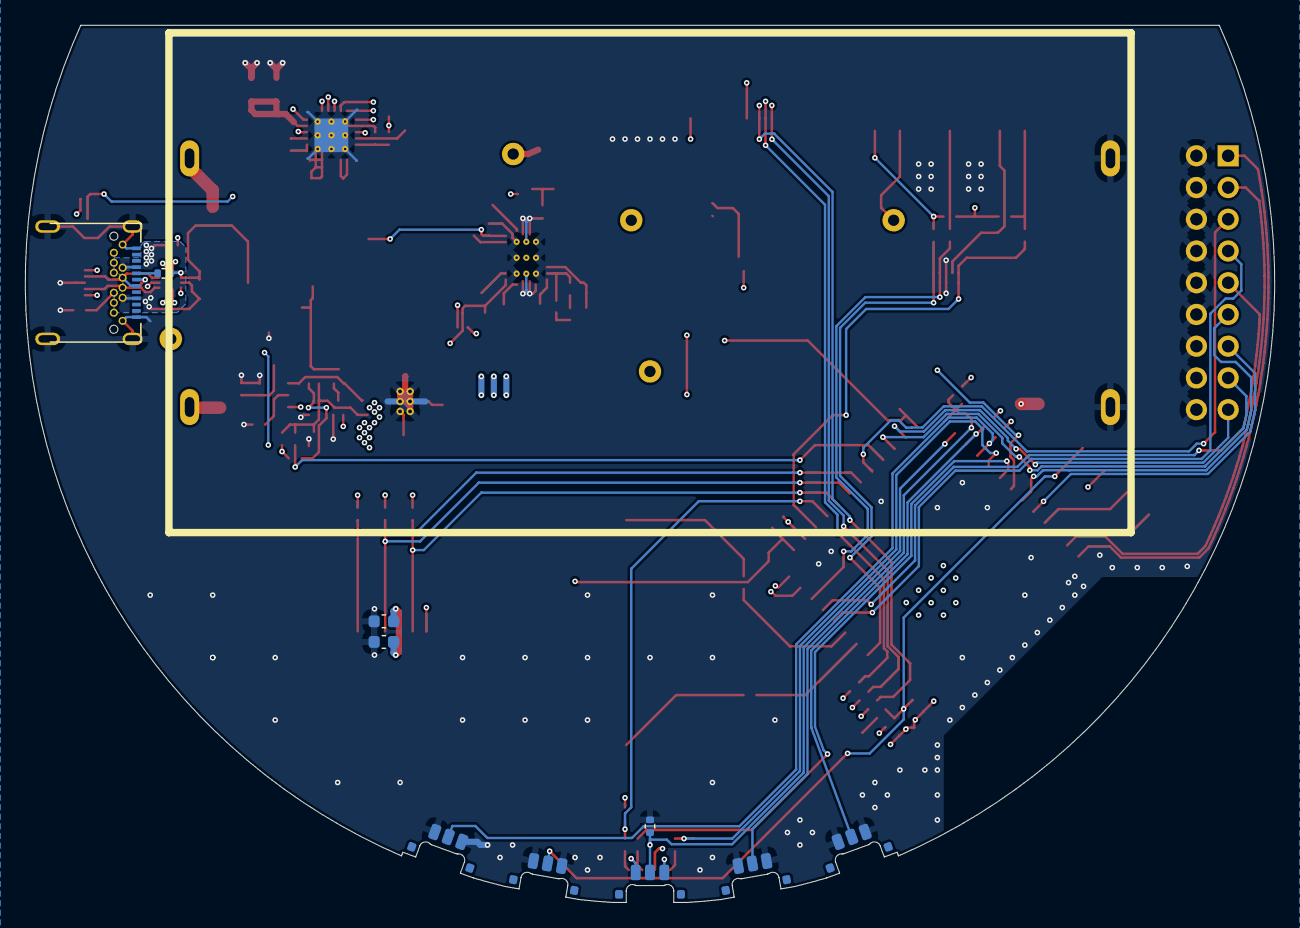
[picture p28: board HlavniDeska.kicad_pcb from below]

Board: 4 copper layers, 100.0 x 70.2 mm, 123 parts (11 on the bottom side), 92 nets.

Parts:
B1: HlavniDeska; Board
BZ1: Buzzer; ELKS-PIEZO
C5, C132, C133, C149: 1u; C_0402_1005Metric
C6: 47n; C_0402_1005Metric
C7, C145, C155: 4.7u; C_0603_1608Metric
C134, C143, C152, C159, C160, C161, C162: 10u; C_0603_1608Metric
C135, C144, C146, C148: 100n; C_0402_1005Metric
C136, C137: 10uF; C_0603_1608Metric
C142, C147, C151, C153, C154, C156: 22u; C_0805_2012Metric
C150: 47n; C_0603_1608Metric
C157: 10n; C_0402_1005Metric
C158: 100p; C_0402_1005Metric
D122: D_Dual_CommonCathode_AAK_Parallel; SOT-723
D125: LED_ARGB; XL-3806RGBC-4L
F1, F2: 3A-6A; L_1206_3216Metric
J1: Conn_02x09_Counter_Clockwise; PinHeader_2x09_P2.54mm_Vertical
J2: USB_C_Receptacle_USB2.0; USB31-TYPEC-33141-2FS
J4: Conn_01x07; JST_PH_S7B-PH-SM4-TB_1x07-1MP_P2.00mm_Horizontal
J5: Micro_SD_Card; microSD_HC_Molex_47219-2001
J7: ESP-Programing_conector
J11: Conn_01x40; Hirose_FH12-40S-0.5SH_1x40-1MP_P0.50mm_Horizontal
L5: 1.2u; L_Abracon_ASPI-0630LR
L6: 0.47u; L_Sunlord_MWSA0402S
Q1, Q2, Q4, Q5, Q6, Q7, Q8, Q9, Q28: NMOS; SOT-723
R1, R2, R6, R7, R8, R9, R10, R12, R13, R16, R17, R32, R35, R36, R41, R51, R79: 10k; R_0402_1005Metric
R3, R4: 5.1k; R_0402_1005Metric
R5, R11, R28: 1k; R_0402_1005Metric
R14, R15: 330; R_0402_1005Metric
R19: 150; R_0402_1005Metric
R20: 56k; R_0402_1005Metric
R21, R40: 100k; R_0402_1005Metric
R26: 470; R_0402_1005Metric
R29, R30, R49, R52: 200; R_0402_1005Metric
R34: 2k; R_0402_1005Metric
R37, R38, R39, R45, R48: 4.7k; R_0402_1005Metric
R47, R53: 200k; R_0402_1005Metric
R50, R58: 17.4k; R_0402_1005Metric
R54, R55: 150k; R_0603_1608Metric
R56: 3.92k; R_0402_1005Metric
R57: 56k; R_0603_1608Metric
SW1, SW2: SW_Push; TCF2QR
SW3: ON; TCF2QR
SW4: BOOT; TCF2QR
SW5: EN; TCF2QR
TP1, TP11: TestPoint-5V_A; Pin_D0.9mm_L10.0mm_W2.4mm_FlatFork
TP8: TestPoint-5V_EN; Pin_D0.9mm_L10.0mm_W2.4mm_FlatFork
TP9: TestPoint-5V; Pin_D0.9mm_L10.0mm_W2.4mm_FlatFork
TP10: TestPoint-5V_B; Pin_D0.9mm_L10.0mm_W2.4mm_FlatFork
U2: BL1530TQFN; UQFN-10_1.4x1.8mm_P0.4mm
U3: BQ25895M; Texas_RTW_WQFN-24-1EP_4x4mm_P0.5mm_EP2.7x2.7mm_ThermalVias
U5, U13: TPD4E02B04DQA; USON-10_2.5x1.0mm_P0.5mm
U7, U8, U9, U15: WSD20L75DN33; Diodes_PowerDI3333-8
U10: NCP708; UDFN6-3x3mm
U11: ESP32-S3-WROOM
U12: SL8261D-G3JE; SOT-23-6
U14: BateriCell_2x; battery_dock
U16: TPS61088RHLR; RHL0020A

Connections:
/HlavniDeska/3V3: C134.2, C135.2, C136.1, C137.1, C152.1, D125.1 (A), J5.4 (VDD), J7.1 (VCC), J11.36, R9.1, R10.1, R16.1, R17.1, R35.1, R36.1, R37.1, R38.1, R39.1, R41.1, R45.2, R48.2, R50.2, R51.1, U10.4 (Vout), U10.5 (SNS), U11.2 (3V3)
/HlavniDeska/5V-OUT: J11.1, J11.2, J11.3, J11.4, J11.5, J11.6, J11.7, J11.8, J11.9, J11.10, J11.11, J11.12, J11.13, TP10.1, U15.5 (D)
/HlavniDeska/ESP32S3/BOOT: C132.1, J7.4 (BOOT), R9.2, SW4.2, U11.27 (IO00-PU)
/HlavniDeska/ESP32S3/EN: C133.1, J7.3 (EN), R10.2, SW5.2, U11.3 (EN)
/HlavniDeska/ESP32S3/IO01: J1.1, U11.39 (IO01)
/HlavniDeska/ESP32S3/IO02: J1.3, U11.38 (IO02)
/HlavniDeska/ESP32S3/IO03-PD: J5.2 (DAT3/CD), R8.1, U11.15 (IO03-PD)
/HlavniDeska/ESP32S3/IO07: R29.2, U5.1 (IO1), U5.10 (NC), U11.7 (IO07)
/HlavniDeska/ESP32S3/IO08: R30.2, U5.2 (IO2), U5.9 (NC), U11.12 (IO08)
/HlavniDeska/ESP32S3/IO09: R49.2, U5.5 (IO4), U5.6 (NC), U11.17 (IO09)
/HlavniDeska/ESP32S3/IO10: R13.2, R28.2, U11.18 (IO10)
/HlavniDeska/ESP32S3/IO11: J5.3 (CMD), R41.2, U11.19 (IO11)
/HlavniDeska/ESP32S3/IO12: J5.5 (CLK), R36.2, U11.20 (IO12)
/HlavniDeska/ESP32S3/IO13: J5.7 (DAT0), R35.2, U11.21 (IO13)
/HlavniDeska/ESP32S3/IO14: J1.5, U11.22 (IO14)
/HlavniDeska/ESP32S3/IO15: R14.1, U11.8 (IO15)
/HlavniDeska/ESP32S3/IO16: R15.1, U11.9 (IO16)
/HlavniDeska/ESP32S3/IO17: J1.7, U11.10 (IO17)
/HlavniDeska/ESP32S3/IO18: J1.9, U11.11 (IO18)
/HlavniDeska/ESP32S3/IO21: R52.2, U11.23 (IO21)
/HlavniDeska/ESP32S3/IO35: Q28.1 (G), R79.1, SW3.2, U11.28 (IO35)
/HlavniDeska/ESP32S3/IO36: R16.2, SW1.2, U11.29 (IO36)
/HlavniDeska/ESP32S3/IO37: R17.2, SW2.2, U11.30 (IO37)
/HlavniDeska/ESP32S3/IO38: R11.2, R12.1, U11.31 (IO38)
/HlavniDeska/ESP32S3/IO39: R5.2, U11.32 (IO39)
/HlavniDeska/ESP32S3/IO41: J1.11, U11.34 (IO41)
/HlavniDeska/ESP32S3/IO42: J1.13, U11.35 (IO42)
/HlavniDeska/ESP32S3/IO45-PD: D122.2 (K), Q2.1 (G), R7.1, U11.26 (IO45-PD)
/HlavniDeska/ESP32S3/IO46-PD: D122.1 (K), Q1.1 (G), R6.1, U11.16 (IO46-PD)
/HlavniDeska/ESP32S3/IO47: J1.15, U11.24 (IO47)
/HlavniDeska/ESP32S3/IO48: J1.17, U11.25 (IO48)
/HlavniDeska/ESP32S3/RX_ESP: J7.5 (RX), U11.36 (IO44-RX)
/HlavniDeska/ESP32S3/TX_ESP: J7.6 (TX), U11.37 (IO43-TX)
/HlavniDeska/ESP.D+: U2.2 (Dp2), U11.14 (IO20-D+)
/HlavniDeska/ESP.D-: U2.6 (Dn2), U11.13 (IO19-D-)
/HlavniDeska/INT: J11.38, R38.2, U3.7 (INT), U11.4 (IO04)
/HlavniDeska/IO40: J11.27, U11.33 (IO40)
/HlavniDeska/ModulovyKonektor/5V: J4.2, J4.6, TP11.1, U5.4 (IO3), U9.5 (D)
/HlavniDeska/Nabijecka.D+: U2.1 (Dp1), U3.2 (D+)
/HlavniDeska/Nabijecka.D-: U2.7 (Dn1), U3.3 (D-)
/HlavniDeska/SCL: J11.40, R37.2, U3.5 (SCL), U11.5 (IO05)
/HlavniDeska/SDA: J11.39, R39.2, U3.6 (SDA), U11.6 (IO06)
/HlavniDeska/SpravceNapajeni/5V-IN: C149.1, C153.1, C154.1, C156.1, R1.1, R32.1, R57.1, TP9.1, U9.1 (S), U9.2 (S), U9.3 (S), U15.1 (S), U15.2 (S), U15.3 (S), U16.14 (VOUT), U16.15 (VOUT), U16.16 (VOUT)
/HlavniDeska/SpravceNapajeni/CHARGER_STAT: R13.1, U3.4 (STAT)
/HlavniDeska/SpravceNapajeni/Charging/BATT: C159.1, R26.1, R40.1, SW3.1, U3.13 (BAT), U3.14 (BAT), U7.1 (S), U7.2 (S), U7.3 (S), U8.1 (S), U8.2 (S), U8.3 (S)
/HlavniDeska/SpravceNapajeni/Charging/CE: Q9.3 (D), R53.2, U3.9 (~CE)
/HlavniDeska/SpravceNapajeni/Charging/SW: C6.1, L6.1, U3.19 (SW), U3.20 (SW)
/HlavniDeska/SpravceNapajeni/Charging/SYS: C160.1, C161.1, L6.2, U3.15 (SYS), U3.16 (SYS)
/HlavniDeska/SpravceNapajeni/Power multiplier/EN-5V: D122.3 (A), R47.2, TP8.1, U16.2 (EN)
/HlavniDeska/SpravceNapajeni/Power multiplier/VCC: C142.1, C143.1, C145.1, C146.1, L5.1, U8.5 (D), U10.1 (EN), U10.6 (Vin), U16.9 (VIN)
/HlavniDeska/SpravceNapajeni/USB_SEL: R2.2, U2.10 (SEL), U3.24 (DSEL)
/HlavniDeska/USB/D+: J2.A6 (D+), J2.B6 (D+), U2.3 (Dp), U13.4 (IO3)
/HlavniDeska/USB/D-: J2.A7 (D-), J2.B7 (D-), U2.5 (Dn), U13.2 (IO2)
/HlavniDeska/USB/USB_CC1: J2.A5 (CC1), R4.1
/HlavniDeska/USB/USB_CC2: J2.B5 (CC2), R3.1
/HlavniDeska/USB/V_USB: C5.1, C162.1, J2.A4 (VBUS), J2.A9 (VBUS), J2.B4 (VBUS), J2.B9 (VBUS), R2.1, R53.1, TP1.1, U2.9 (VCC), U3.1 (VBUS), U13.1 (IO1), U13.5 (IO4)
GND: C5.2, C7.2, C132.2, C133.2, C134.1, C135.1, C136.2, C137.2, C142.2, C143.2, C144.2, C145.2, C146.2, C147.2, C149.2, C150.2, C151.2, C152.2, C153.2, C154.2, C155.2, C156.2, C157.2, C158.2, C159.2, C160.2, C161.2, C162.2, J1.2, J1.4, J1.6, J1.8, J1.10, J1.12, J1.14, J1.16, J1.18, J2.A1 (GND), J2.A12 (GND), J2.B1 (GND), J2.B12 (GND), J2.S1 (SHIELD), J4.3, J4.5, J5.6 (VSS), J5.9 (SHIELD), J7.2 (GND), J11.14, J11.15, J11.16, J11.17, J11.18, J11.19, J11.20, J11.21, J11.22, J11.23, J11.24, J11.25, J11.26, J11.37, Q1.2 (S), Q2.2 (S), Q7.2 (S), Q8.2 (S), Q9.2 (S), Q28.2 (S), R3.2, R4.2, R6.2, R7.2, R8.2, R12.2, R19.2, R21.1, R34.1, R47.1, R55.2, R58.1, R79.2, SW1.1, SW2.1, SW4.1, SW5.1, U2.4 (GND), U2.8 (OEb), U3.8 (OTG), U3.17 (PGND), U3.18 (PGND), U3.25 (PGND), U5.3 (G), U5.8 (G), U7.4 (G), U10.2 (GND), U10.7 (GND), U11.1 (GND), U11.40 (GND), U11.41 (GND), U12.6 (GND), U13.3 (G), U13.8 (G), U14.2 (-), U14.4 (-), U16.0 (PGND), U16.20 (AGND), U16.21 (PGND)
unnamed: BZ1.2 (+), R15.2
unnamed: BZ1.1 (-), R14.2
unnamed: C157.1, R56.2
unnamed: D125.4 (BK), R28.1
unnamed: D125.3 (GK), R5.1
unnamed: D125.2 (RK), R11.1
unnamed: F1.2, U14.3 (+)
unnamed: F2.2, U14.1 (+)
unnamed: J4.1, R29.1, R48.1
unnamed: J4.4, R30.1
unnamed: J4.7, R45.1, R49.1
unnamed: Q1.3 (D), R1.2, U9.4 (G)
unnamed: Q2.3 (D), R32.2, U15.4 (G)
unnamed: Q4.3 (D), Q5.1 (G), U12.1 (OD)
unnamed: Q4.1 (G), Q4.2 (S), Q6.1 (G), Q7.1 (G), Q8.3 (D), R51.2, R52.1
unnamed: Q5.3 (D), Q6.3 (D), R40.2, U8.4 (G)
unnamed: Q6.2 (S), Q7.3 (D), Q8.1 (G), R50.1
unnamed: Q9.1 (G), U12.3 (OC)
unnamed: Q5.2 (S), Q28.3 (D)
unnamed: C6.2, U3.21 (BTST)
unnamed: R19.1, U3.10 (ILIM)
unnamed: C147.1, C151.1, U3.23 (PMID)
unnamed: C7.1, R20.1, U3.22 (REGN)
unnamed: R20.2, R21.2, U3.11 (TS)
unnamed: F1.1, F2.1, U7.5 (D)
unnamed: C144.1, R26.2, U12.5 (VCC)
unnamed: R34.2, U12.2 (VM)
unnamed: C148.2, U16.8 (BOOT)
unnamed: C158.1, R56.1, U16.18 (COMP)
unnamed: R57.2, R58.2, U16.17 (FB)
unnamed: R54.2, U16.3 (FSW)
unnamed: R55.1, U16.19 (ILIM)
unnamed: C150.1, U16.10 (SS)
unnamed: C155.1, U16.1 (VCC)
SW: C148.1, L5.2, R54.1, U16.4 (SW), U16.5 (SW), U16.6 (SW), U16.7 (SW)

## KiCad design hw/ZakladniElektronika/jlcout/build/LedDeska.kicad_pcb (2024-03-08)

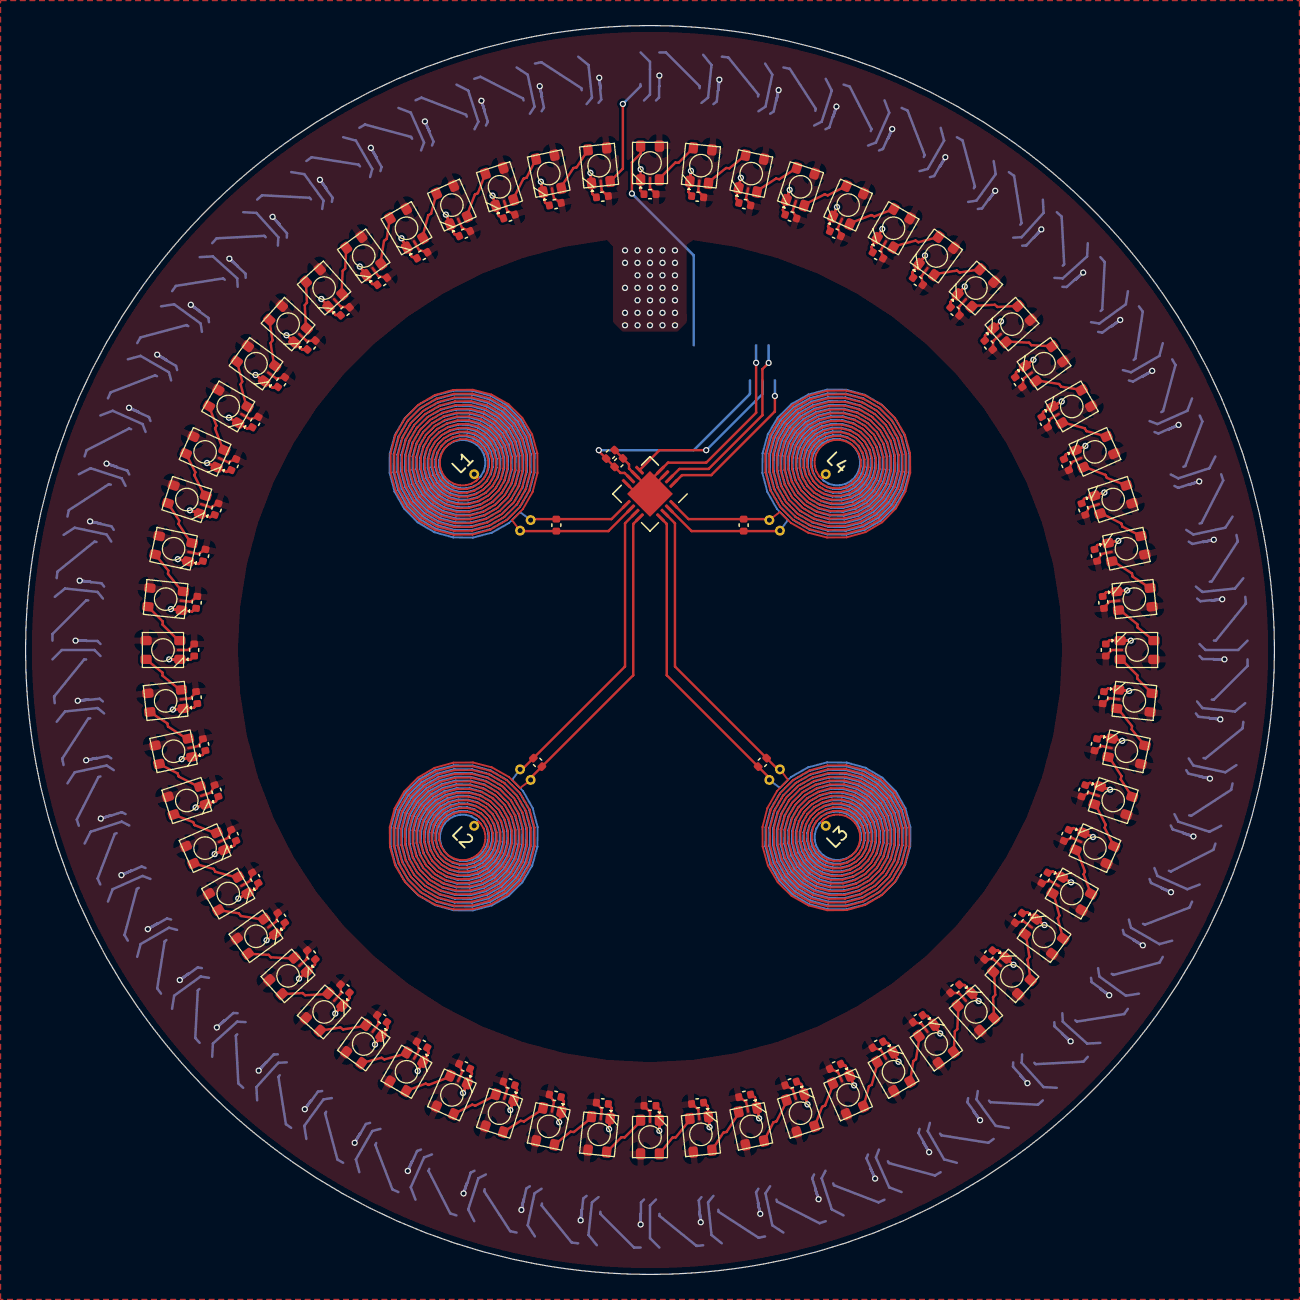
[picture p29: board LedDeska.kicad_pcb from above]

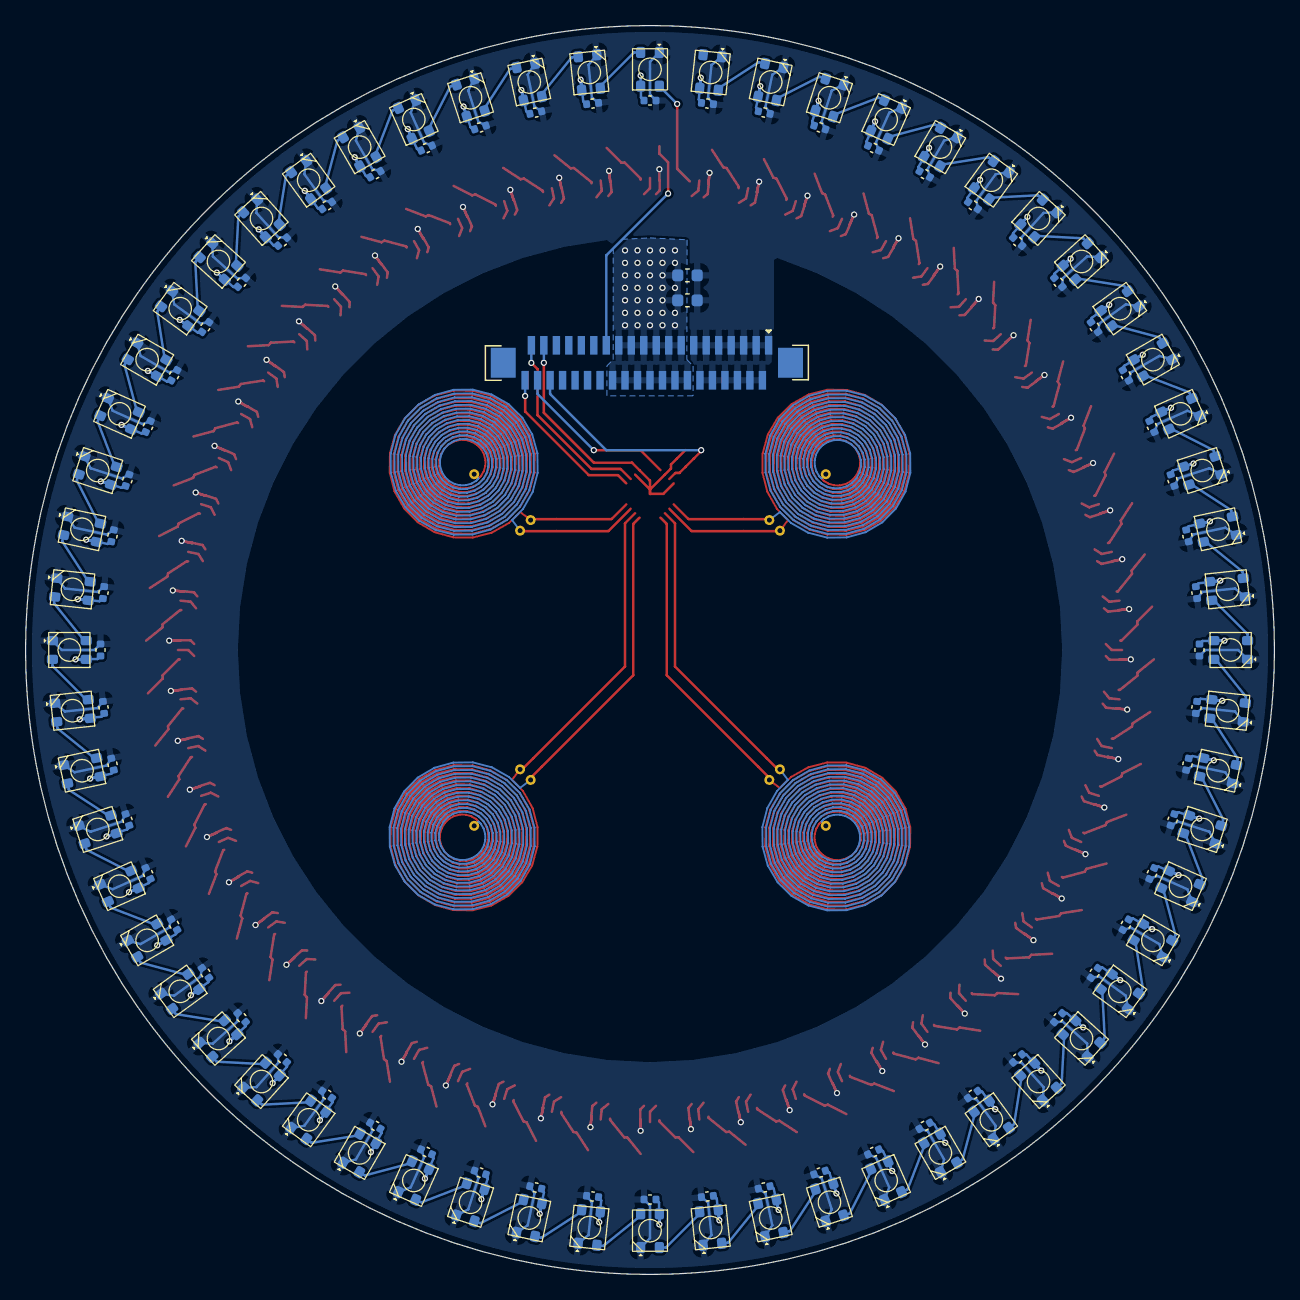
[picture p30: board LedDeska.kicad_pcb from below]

Board: 2 copper layers, 100.0 x 100.0 mm, 254 parts (123 on the bottom side), 135 nets.

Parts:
C1, C2: 10u; C_0603_1608Metric
C3: 1u; C_0402_1005Metric
C4, C12, C13, C14, C15, C16, C17, C18, C19, C20, C21, C22, C23, C24, C25, C26, C27, C28, C29, C30, C31, C32, C33, C34, C35, C36, C37, C38, C39, C40, C41, C42, C43, C44, C45, C46, C47, C48, C49, C50, C51, C52, C53, C54, C55, C56, C57, C58, C59, C60, C61, C62, C63, C64, C65, C66, C67, C68, C69, C70, C71, C72, C73, C74, C75, C76, C77, C78, C79, C80, C81, C82, C83, C84, C85, C86, C87, C88, C89, C90, C91, C92, C93, C94, C95, C96, C97, C98, C99, C100, C101, C102, C103, C104, C105, C106, C107, C108, C109, C110, C111, C112, C113, C114, C115, C116, C117, C118, C119, C120, C121, C122, C123, C124, C125, C126, C127, C128, C129, C130, C131: 100n; C_0402_1005Metric
C8, C9, C10, C11: 1000p; C_0402_1005Metric
D1, D2, D3, D4, D5, D6, D7, D8, D9, D10, D11, D12, D13, D14, D15, D16, D17, D18, D19, D20, D21, D22, D23, D24, D25, D26, D27, D28, D29, D30, D31, D32, D33, D34, D35, D36, D37, D38, D39, D40, D41, D42, D43, D44, D45, D46, D47, D48, D49, D50, D51, D52, D53, D54, D55, D56, D57, D58, D59, D60, D61, D62, D63, D64, D65, D66, D67, D68, D69, D70, D71, D72, D73, D74, D75, D76, D77, D78, D79, D80, D81, D82, D83, D84, D85, D86, D87, D88, D89, D90, D91, D92, D93, D94, D95, D96, D97, D98, D99, D100, D101, D102, D103, D104, D105, D106, D107, D108, D109, D110, D111, D112, D113, D114, D115, D116, D117, D118, D119, D120: WS2812B; 3528RGBW-WS2812B
J10: Conn_01x40; AFC11-S40ICC-00
L1, L2, L3, L4: 5.738 µH; PCB_coil
U1: LDC1614; WQFN-16-1EP_4x4mm_P0.5mm_EP2.6x2.6mm

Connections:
/LedDeska/3V3: C3.1, C4.1, J10.36, U1.7 (VDD)
/LedDeska/5V: C1.1, C2.1, C12.1, C13.1, C14.1, C15.1, C16.1, C17.1, C18.1, C19.1, C20.1, C21.1, C22.1, C23.1, C24.1, C25.1, C26.1, C27.1, C28.1, C29.1, C30.1, C31.1, C32.1, C33.1, C34.1, C35.1, C36.1, C37.1, C38.1, C39.1, C40.1, C41.1, C42.1, C43.1, C44.1, C45.1, C46.1, C47.1, C48.1, C49.1, C50.1, C51.1, C52.1, C53.1, C54.1, C55.1, C56.1, C57.1, C58.1, C59.1, C60.1, C61.1, C62.1, C63.1, C64.1, C65.1, C66.1, C67.1, C68.1, C69.1, C70.1, C71.1, C72.1, C73.1, C74.1, C75.1, C76.1, C77.1, C78.1, C79.1, C80.1, C81.1, C82.1, C83.1, C84.1, C85.1, C86.1, C87.1, C88.1, C89.1, C90.1, C91.1, C92.1, C93.1, C94.1, C95.1, C96.1, C97.1, C98.1, C99.1, C100.1, C101.1, C102.1, C103.1, C104.1, C105.1, C106.1, C107.1, C108.1, C109.1, C110.1, C111.1, C112.1, C113.1, C114.1, C115.1, C116.1, C117.1, C118.1, C119.1, C120.1, C121.1, C122.1, C123.1, C124.1, C125.1, C126.1, C127.1, C128.1, C129.1, C130.1, C131.1, D1.1 (VDD), D2.1 (VDD), D3.1 (VDD), D4.1 (VDD), D5.1 (VDD), D6.1 (VDD), D7.1 (VDD), D8.1 (VDD), D9.1 (VDD), D10.1 (VDD), D11.1 (VDD), D12.1 (VDD), D13.1 (VDD), D14.1 (VDD), D15.1 (VDD), D16.1 (VDD), D17.1 (VDD), D18.1 (VDD), D19.1 (VDD), D20.1 (VDD), D21.1 (VDD), D22.1 (VDD), D23.1 (VDD), D24.1 (VDD), D25.1 (VDD), D26.1 (VDD), D27.1 (VDD), D28.1 (VDD), D29.1 (VDD), D30.1 (VDD), D31.1 (VDD), D32.1 (VDD), D33.1 (VDD), D34.1 (VDD), D35.1 (VDD), D36.1 (VDD), D37.1 (VDD), D38.1 (VDD), D39.1 (VDD), D40.1 (VDD), D41.1 (VDD), D42.1 (VDD), D43.1 (VDD), D44.1 (VDD), D45.1 (VDD), D46.1 (VDD), D47.1 (VDD), D48.1 (VDD), D49.1 (VDD), D50.1 (VDD), D51.1 (VDD), D52.1 (VDD), D53.1 (VDD), D54.1 (VDD), D55.1 (VDD), D56.1 (VDD), D57.1 (VDD), D58.1 (VDD), D59.1 (VDD), D60.1 (VDD), D61.1 (VDD), D62.1 (VDD), D63.1 (VDD), D64.1 (VDD), D65.1 (VDD), D66.1 (VDD), D67.1 (VDD), D68.1 (VDD), D69.1 (VDD), D70.1 (VDD), D71.1 (VDD), D72.1 (VDD), D73.1 (VDD), D74.1 (VDD), D75.1 (VDD), D76.1 (VDD), D77.1 (VDD), D78.1 (VDD), D79.1 (VDD), D80.1 (VDD), D81.1 (VDD), D82.1 (VDD), D83.1 (VDD), D84.1 (VDD), D85.1 (VDD), D86.1 (VDD), D87.1 (VDD), D88.1 (VDD), D89.1 (VDD), D90.1 (VDD), D91.1 (VDD), D92.1 (VDD), D93.1 (VDD), D94.1 (VDD), D95.1 (VDD), D96.1 (VDD), D97.1 (VDD), D98.1 (VDD), D99.1 (VDD), D100.1 (VDD), D101.1 (VDD), D102.1 (VDD), D103.1 (VDD), D104.1 (VDD), D105.1 (VDD), D106.1 (VDD), D107.1 (VDD), D108.1 (VDD), D109.1 (VDD), D110.1 (VDD), D111.1 (VDD), D112.1 (VDD), D113.1 (VDD), D114.1 (VDD), D115.1 (VDD), D116.1 (VDD), D117.1 (VDD), D118.1 (VDD), D119.1 (VDD), D120.1 (VDD), J10.1, J10.2, J10.3, J10.4, J10.5, J10.6, J10.7, J10.8, J10.9, J10.10, J10.11, J10.12, J10.13
/LedDeska/AN-GND: C3.2, C4.2, J10.37, U1.3 (CLKIN), U1.4 (ADDR), U1.6 (SD), U1.8 (GND), U1.17 (GND)
/LedDeska/INT-LDC: J10.38, U1.5 (INTB)
/LedDeska/LED-GND: C1.2, C2.2, C12.2, C13.2, C14.2, C15.2, C16.2, C17.2, C18.2, C19.2, C20.2, C21.2, C22.2, C23.2, C24.2, C25.2, C26.2, C27.2, C28.2, C29.2, C30.2, C31.2, C32.2, C33.2, C34.2, C35.2, C36.2, C37.2, C38.2, C39.2, C40.2, C41.2, C42.2, C43.2, C44.2, C45.2, C46.2, C47.2, C48.2, C49.2, C50.2, C51.2, C52.2, C53.2, C54.2, C55.2, C56.2, C57.2, C58.2, C59.2, C60.2, C61.2, C62.2, C63.2, C64.2, C65.2, C66.2, C67.2, C68.2, C69.2, C70.2, C71.2, C72.2, C73.2, C74.2, C75.2, C76.2, C77.2, C78.2, C79.2, C80.2, C81.2, C82.2, C83.2, C84.2, C85.2, C86.2, C87.2, C88.2, C89.2, C90.2, C91.2, C92.2, C93.2, C94.2, C95.2, C96.2, C97.2, C98.2, C99.2, C100.2, C101.2, C102.2, C103.2, C104.2, C105.2, C106.2, C107.2, C108.2, C109.2, C110.2, C111.2, C112.2, C113.2, C114.2, C115.2, C116.2, C117.2, C118.2, C119.2, C120.2, C121.2, C122.2, C123.2, C124.2, C125.2, C126.2, C127.2, C128.2, C129.2, C130.2, C131.2, D1.3 (VSS), D2.3 (VSS), D3.3 (VSS), D4.3 (VSS), D5.3 (VSS), D6.3 (VSS), D7.3 (VSS), D8.3 (VSS), D9.3 (VSS), D10.3 (VSS), D11.3 (VSS), D12.3 (VSS), D13.3 (VSS), D14.3 (VSS), D15.3 (VSS), D16.3 (VSS), D17.3 (VSS), D18.3 (VSS), D19.3 (VSS), D20.3 (VSS), D21.3 (VSS), D22.3 (VSS), D23.3 (VSS), D24.3 (VSS), D25.3 (VSS), D26.3 (VSS), D27.3 (VSS), D28.3 (VSS), D29.3 (VSS), D30.3 (VSS), D31.3 (VSS), D32.3 (VSS), D33.3 (VSS), D34.3 (VSS), D35.3 (VSS), D36.3 (VSS), D37.3 (VSS), D38.3 (VSS), D39.3 (VSS), D40.3 (VSS), D41.3 (VSS), D42.3 (VSS), D43.3 (VSS), D44.3 (VSS), D45.3 (VSS), D46.3 (VSS), D47.3 (VSS), D48.3 (VSS), D49.3 (VSS), D50.3 (VSS), D51.3 (VSS), D52.3 (VSS), D53.3 (VSS), D54.3 (VSS), D55.3 (VSS), D56.3 (VSS), D57.3 (VSS), D58.3 (VSS), D59.3 (VSS), D60.3 (VSS), D61.3 (VSS), D62.3 (VSS), D63.3 (VSS), D64.3 (VSS), D65.3 (VSS), D66.3 (VSS), D67.3 (VSS), D68.3 (VSS), D69.3 (VSS), D70.3 (VSS), D71.3 (VSS), D72.3 (VSS), D73.3 (VSS), D74.3 (VSS), D75.3 (VSS), D76.3 (VSS), D77.3 (VSS), D78.3 (VSS), D79.3 (VSS), D80.3 (VSS), D81.3 (VSS), D82.3 (VSS), D83.3 (VSS), D84.3 (VSS), D85.3 (VSS), D86.3 (VSS), D87.3 (VSS), D88.3 (VSS), D89.3 (VSS), D90.3 (VSS), D91.3 (VSS), D92.3 (VSS), D93.3 (VSS), D94.3 (VSS), D95.3 (VSS), D96.3 (VSS), D97.3 (VSS), D98.3 (VSS), D99.3 (VSS), D100.3 (VSS), D101.3 (VSS), D102.3 (VSS), D103.3 (VSS), D104.3 (VSS), D105.3 (VSS), D106.3 (VSS), D107.3 (VSS), D108.3 (VSS), D109.3 (VSS), D110.3 (VSS), D111.3 (VSS), D112.3 (VSS), D113.3 (VSS), D114.3 (VSS), D115.3 (VSS), D116.3 (VSS), D117.3 (VSS), D118.3 (VSS), D119.3 (VSS), D120.3 (VSS), J10.14, J10.15, J10.16, J10.17, J10.18, J10.19, J10.20, J10.21, J10.22, J10.23, J10.24, J10.25, J10.26
/LedDeska/LedRing-Axial/DOUT: D60.2 (DOUT), D61.4 (DIN)
/LedDeska/SCL: J10.40, U1.1 (SCL)
/LedDeska/SDA: J10.39, U1.2 (SDA)
/LedDeska/WS2812: D1.4 (DIN), J10.27
unnamed: D1.2 (DOUT), D2.4 (DIN)
unnamed: D2.2 (DOUT), D3.4 (DIN)
unnamed: D3.2 (DOUT), D4.4 (DIN)
unnamed: D4.2 (DOUT), D5.4 (DIN)
unnamed: D5.2 (DOUT), D6.4 (DIN)
unnamed: D6.2 (DOUT), D7.4 (DIN)
unnamed: D7.2 (DOUT), D8.4 (DIN)
unnamed: D8.2 (DOUT), D9.4 (DIN)
unnamed: D9.2 (DOUT), D10.4 (DIN)
unnamed: D10.2 (DOUT), D11.4 (DIN)
unnamed: D11.2 (DOUT), D12.4 (DIN)
unnamed: D12.2 (DOUT), D13.4 (DIN)
unnamed: D13.2 (DOUT), D14.4 (DIN)
unnamed: D14.2 (DOUT), D15.4 (DIN)
unnamed: D15.2 (DOUT), D16.4 (DIN)
unnamed: D16.2 (DOUT), D17.4 (DIN)
unnamed: D17.2 (DOUT), D18.4 (DIN)
unnamed: D18.2 (DOUT), D19.4 (DIN)
unnamed: D19.2 (DOUT), D20.4 (DIN)
unnamed: D20.2 (DOUT), D21.4 (DIN)
unnamed: D21.2 (DOUT), D22.4 (DIN)
unnamed: D22.2 (DOUT), D23.4 (DIN)
unnamed: D23.2 (DOUT), D24.4 (DIN)
unnamed: D24.2 (DOUT), D25.4 (DIN)
unnamed: D25.2 (DOUT), D26.4 (DIN)
unnamed: D26.2 (DOUT), D27.4 (DIN)
unnamed: D27.2 (DOUT), D28.4 (DIN)
unnamed: D28.2 (DOUT), D29.4 (DIN)
unnamed: D29.2 (DOUT), D30.4 (DIN)
unnamed: D30.2 (DOUT), D31.4 (DIN)
unnamed: D31.2 (DOUT), D32.4 (DIN)
unnamed: D32.2 (DOUT), D33.4 (DIN)
unnamed: D33.2 (DOUT), D34.4 (DIN)
unnamed: D34.2 (DOUT), D35.4 (DIN)
unnamed: D35.2 (DOUT), D36.4 (DIN)
unnamed: D36.2 (DOUT), D37.4 (DIN)
unnamed: D37.2 (DOUT), D38.4 (DIN)
unnamed: D38.2 (DOUT), D39.4 (DIN)
unnamed: D39.2 (DOUT), D40.4 (DIN)
unnamed: D40.2 (DOUT), D41.4 (DIN)
unnamed: D41.2 (DOUT), D42.4 (DIN)
unnamed: D42.2 (DOUT), D43.4 (DIN)
unnamed: D43.2 (DOUT), D44.4 (DIN)
unnamed: D44.2 (DOUT), D45.4 (DIN)
unnamed: D45.2 (DOUT), D46.4 (DIN)
unnamed: D46.2 (DOUT), D47.4 (DIN)
unnamed: D47.2 (DOUT), D48.4 (DIN)
unnamed: D48.2 (DOUT), D49.4 (DIN)
unnamed: D49.2 (DOUT), D50.4 (DIN)
unnamed: D50.2 (DOUT), D51.4 (DIN)
unnamed: D51.2 (DOUT), D52.4 (DIN)
unnamed: D52.2 (DOUT), D53.4 (DIN)
unnamed: D53.2 (DOUT), D54.4 (DIN)
unnamed: D54.2 (DOUT), D55.4 (DIN)
unnamed: D55.2 (DOUT), D56.4 (DIN)
unnamed: D56.2 (DOUT), D57.4 (DIN)
unnamed: D57.2 (DOUT), D58.4 (DIN)
unnamed: D58.2 (DOUT), D59.4 (DIN)
unnamed: D59.2 (DOUT), D60.4 (DIN)
unnamed: D61.2 (DOUT), D62.4 (DIN)
unnamed: D62.2 (DOUT), D63.4 (DIN)
unnamed: D63.2 (DOUT), D64.4 (DIN)
unnamed: D64.2 (DOUT), D65.4 (DIN)
unnamed: D65.2 (DOUT), D66.4 (DIN)
unnamed: D66.2 (DOUT), D67.4 (DIN)
unnamed: D67.2 (DOUT), D68.4 (DIN)
unnamed: D68.2 (DOUT), D69.4 (DIN)
unnamed: D69.2 (DOUT), D70.4 (DIN)
unnamed: D70.2 (DOUT), D71.4 (DIN)
unnamed: D71.2 (DOUT), D72.4 (DIN)
unnamed: D72.2 (DOUT), D73.4 (DIN)
unnamed: D73.2 (DOUT), D74.4 (DIN)
unnamed: D74.2 (DOUT), D75.4 (DIN)
unnamed: D75.2 (DOUT), D76.4 (DIN)
unnamed: D76.2 (DOUT), D77.4 (DIN)
unnamed: D77.2 (DOUT), D78.4 (DIN)
unnamed: D78.2 (DOUT), D79.4 (DIN)
unnamed: D79.2 (DOUT), D80.4 (DIN)
unnamed: D80.2 (DOUT), D81.4 (DIN)
unnamed: D81.2 (DOUT), D82.4 (DIN)
unnamed: D82.2 (DOUT), D83.4 (DIN)
unnamed: D83.2 (DOUT), D84.4 (DIN)
unnamed: D84.2 (DOUT), D85.4 (DIN)
unnamed: D85.2 (DOUT), D86.4 (DIN)
unnamed: D86.2 (DOUT), D87.4 (DIN)
unnamed: D87.2 (DOUT), D88.4 (DIN)
unnamed: D88.2 (DOUT), D89.4 (DIN)
unnamed: D89.2 (DOUT), D90.4 (DIN)
unnamed: D90.2 (DOUT), D91.4 (DIN)
unnamed: D91.2 (DOUT), D92.4 (DIN)
unnamed: D92.2 (DOUT), D93.4 (DIN)
unnamed: D93.2 (DOUT), D94.4 (DIN)
unnamed: D94.2 (DOUT), D95.4 (DIN)
unnamed: D95.2 (DOUT), D96.4 (DIN)
unnamed: D96.2 (DOUT), D97.4 (DIN)
unnamed: D97.2 (DOUT), D98.4 (DIN)
unnamed: D98.2 (DOUT), D99.4 (DIN)
unnamed: D99.2 (DOUT), D100.4 (DIN)
unnamed: D100.2 (DOUT), D101.4 (DIN)
unnamed: D101.2 (DOUT), D102.4 (DIN)
unnamed: D102.2 (DOUT), D103.4 (DIN)
unnamed: D103.2 (DOUT), D104.4 (DIN)
unnamed: D104.2 (DOUT), D105.4 (DIN)
unnamed: D105.2 (DOUT), D106.4 (DIN)
unnamed: D106.2 (DOUT), D107.4 (DIN)
unnamed: D107.2 (DOUT), D108.4 (DIN)
unnamed: D108.2 (DOUT), D109.4 (DIN)
unnamed: D109.2 (DOUT), D110.4 (DIN)
unnamed: D110.2 (DOUT), D111.4 (DIN)
unnamed: D111.2 (DOUT), D112.4 (DIN)
unnamed: D112.2 (DOUT), D113.4 (DIN)
unnamed: D113.2 (DOUT), D114.4 (DIN)
unnamed: D114.2 (DOUT), D115.4 (DIN)
unnamed: D115.2 (DOUT), D116.4 (DIN)
unnamed: D116.2 (DOUT), D117.4 (DIN)
unnamed: D117.2 (DOUT), D118.4 (DIN)
unnamed: D118.2 (DOUT), D119.4 (DIN)
unnamed: D119.2 (DOUT), D120.4 (DIN)
unnamed: C8.1, L1.2, U1.9 (IN0A)
unnamed: C8.2, L1.1, U1.10 (IN0B)
unnamed: C9.1, L2.2, U1.11 (IN1A)
unnamed: C9.2, L2.1, U1.12 (IN1B)
unnamed: C10.1, L3.2, U1.13 (IN2A)
unnamed: C10.2, L3.1, U1.14 (IN2B)
unnamed: C11.1, L4.2, U1.15 (IN3A)
unnamed: C11.2, L4.1, U1.16 (IN3B)

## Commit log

2023-11-17 Nastin schematu
    [ESP332S3.kicad_sch, GPSKomunikacniModul.kicad_sch, HlavniDeska.kicad_sch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]
2023-12-03 Zaciame psat
    [ESP332S3.kicad_sch, HlavniDeska.kicad_sch, Nabijecka.kicad_sch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]
2023-12-08 Zavazbení zapínání
    [GPSKomunikacniModul.kicad_sch, HlavniDeska.kicad_sch, ModuloviKonektor.kicad_sch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]
2023-12-12 Přepys na case study
    [ZpravceNapajeni.kicad_sch]
2023-12-20 USB_multiplexer a přehlednost
    [ESP32S3.kicad_sch, GPSKomunikacniModul.kicad_sch, HlavniDeska.kicad_sch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]
2023-12-23 Likvidace MiniUI jako samostatné desky a výběr všech komponent
    [ESP32S3.kicad_sch, GPSKomunikacniModul.kicad_sch, HlavniDeska.kicad_sch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]
2023-12-26 Výmněna ochrany baterie
    Předchozí ochranný čip JLCPCB nemělo na skladě
    [ESP32S3.kicad_sch, GPSKomunikacniModul.kicad_sch, HlavniDeska.kicad_sch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]
2024-01-21 Hodnoty senzorických cívek
    [LedDeska.kicad_sch]
2024-05-24 Řešení issue "Držák baterek" a " SemiSemafor V0"
    [HlavniDeska.kicad_sch, NapajeciRozcesti.kicad_sch, Zdroj.kicad_sch]
2024-05-25 Řešení issue "Čtení zapínacího tlačítka"
    [Zdroj.kicad_sch]
2024-05-25 WPI (zápínací logika)
    [Zdroj.kicad_sch]
2025-03-21 KiCad V8
    [ESP32S3.kicad_sch, GPSKomunikacniModul.kicad_sch, HlavniDeska.kicad_sch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]
2025-04-04 Hw wip
    [LedRing.kicad_sch, ZpravceNapajeni.kicad_sch, charging.kicad_sch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]
2025-04-04 Text wip
    [power_manager.kicad_sch]
2025-04-15 Hw PCB
    [ESP32S3.kicad_sch, HlavniDeska.kicad_sch, LedDeska.kicad_sch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]
2025-05-05 Bordel Hw
    [ESP32S3.kicad_sch, HlavniDeska.kicad_pcb, HlavniDeska.kicad_sch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]
